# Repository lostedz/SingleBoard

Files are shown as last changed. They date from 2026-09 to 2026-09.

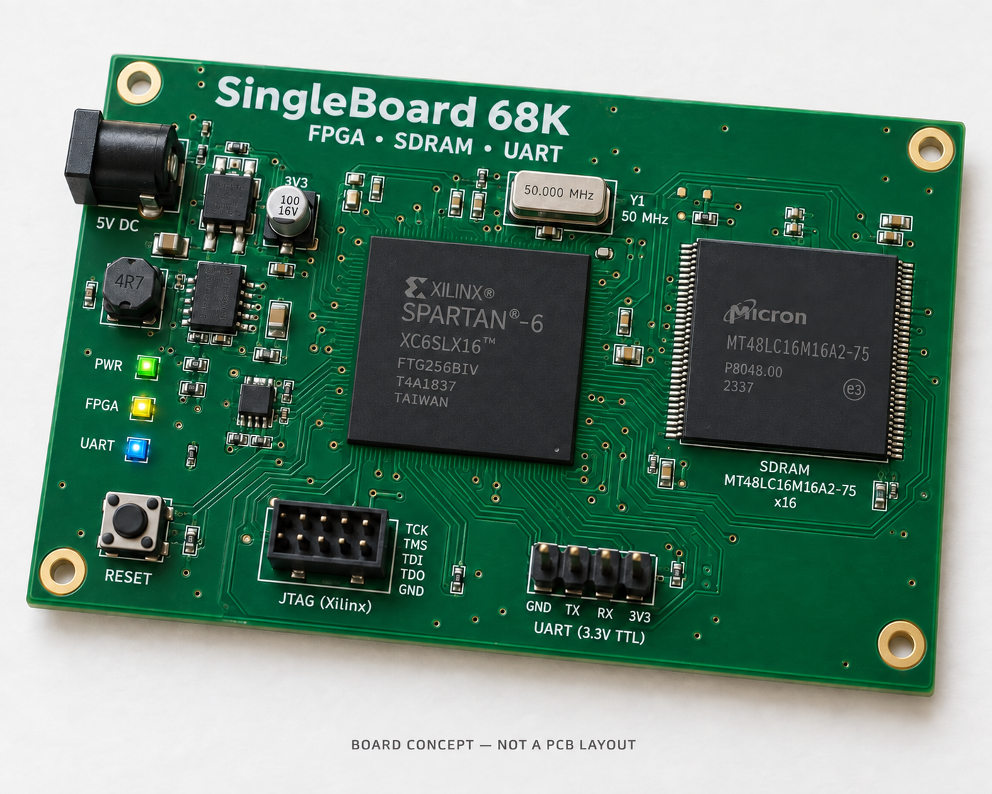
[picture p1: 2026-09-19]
docs/images/singleboard-concept.png

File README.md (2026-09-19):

# 68000 Verilog CPU

Target: **Xilinx Spartan-6 XC6SLX16 / FTG256 at 50 MHz** (speed grade -2
provisional). See `fpga/spartan6/README.md` for the ISE/XST
synthesis flow and board integration requirements.

An **MT48LC16M16A2-75 SDRAM controller** is included for the same 50 MHz clock.
See [SDRAM integration](docs/sdram.md) for its 32 MiB address mapping, CPU bus
connection, Spartan-6 clock forwarding, initialization and refresh behavior.
Run its standalone and CPU integration tests with `python scripts/test_sdram.py`.

A [memory-mapped UART](docs/uart.md) is available at **0xFF0000**, defaulting
to **115200 baud, 8N1** at 50 MHz. It includes TX/RX buffering, receive error
flags and optional interrupts. Run `python scripts/test_uart.py` for serial
and 68000 interrupt/echo tests.

A [schematic and board](hardware/README.md) for this target are in `hardware/`, as
a KiCad 10 project covering power, FPGA supply and configuration, the boot flash,
the SDRAM and the UART/clock/reset front panel. Both are generated:
`python scripts/gen_schematic.py` emits the drawing and the matching
`fpga/spartan6/singleboard.ucf` from one ball-assignment table, and
`python scripts/gen_pcb.py` builds the board from the schematic's own netlist —
a 120 × 90 mm four-layer placement whose floorplan follows which bank each
block's balls are in. The schematic passes ERC, the board passes DRC, and the
copper has been read back and compared to the assignment table. It is still a
concept: **the board has no tracks on it**, and there has been no ISE run and no
hardware validation.

`rtl/m68000.v` provides a synthesizable Verilog-2005 CPU for FPGA integration,
based on Frederic Requin's ISC-licensed [J68](https://github.com/fredrequin/j68_cpu).
The execution engine is vendored J68 RTL, not a newly written CPU. Local work
adds a 24-bit address interface, portable inferred memories, and executable
self-checking integration tests.

J68 implements the 68000 instruction set using a microcoded 16-bit datapath:
eight 32-bit data registers, eight address registers, separate user and
supervisor stacks, condition codes, effective-address decoding, multiply/divide,
traps, and autovectored interrupts. See `rtl/j68/PROVENANCE.md` for the pinned
revision and changes.

## Interface

All signals use one rising-edge clock. Inputs must be synchronous to `clk`.

| Signal | Meaning |
| --- | --- |
| `clk`, `reset` | Clock and active-high reset; hold reset for at least two clock edges and deassert synchronously |
| `clk_en` | CPU step enable; tie high for continuous execution |
| `ipl_n[2:0]` | Active-low encoded interrupt level; `111` is no interrupt, `101` is level 2 |
| `bus_valid` | Pending memory transaction |
| `bus_write` | 1 for write, 0 for read; meaningful while valid |
| `bus_addr[23:0]` | Byte address, including the low bit; high internal address bits are truncated to the 68000's 24-bit address space |
| `bus_be[1:0]` | Active-high byte lanes: bit 1 selects the even-address/high byte, bit 0 the odd-address/low byte |
| `bus_wdata[15:0]` | Write data already positioned in the selected lanes |
| `bus_rdata[15:0]` | Read data for the aligned word containing `bus_addr` |
| `bus_ready` | Memory acknowledgement; reads must have valid data on the completion edge |
| `bus_fc[2:0]` | J68 function-code output (user/supervisor, data/program/vector) |
| `debug_pc`, `debug_sr` | Internal 32-bit program counter and 16-bit status register |

A transfer completes on a rising edge when **`clk_en && bus_valid && bus_ready`**.
The memory slave must use that same condition for write side effects. Address,
direction, lanes, function code and write data remain stable during a pending
transaction, including CPU pauses. A slave may keep `bus_ready` high, or delay
it for any number of cycles. If the CPU is paused, retain read data/acknowledgement
until an enabled completion edge. Reset cancels a pending transaction.

Memory is big-endian. A longword uses two word transactions, high word first
for normal forward accesses. Fetch the initial SSP from addresses 0–3 and
initial PC from 4–7. Supply a valid reset-vector table and executable memory.
The testbench is a complete example memory slave.

## Build and test

Run from the project root so `$readmemb` can locate `rtl/j68/*.mem`. Include
every source in `rtl/files.f` and select `m68000` as the synthesis top. Memory
initialization must be supported by the target FPGA/toolchain; this is not
an ASIC ROM implementation. There are no vendor primitives or SystemVerilog
dependencies in the RTL.

With Python 3 and Icarus Verilog (`iverilog` and `vvp`) on PATH:

```sh
python scripts/test.py
python scripts/test.py --vcd
```

The runner also recognizes a local portable Windows installation in
`.tools/bin`. Test firmware is committed as `tests/smoke.hex`; an assembler
is not needed to run tests. To rebuild it with vasm:

```sh
vasmm68k -m68000 -Fbin -o build/smoke.bin tests/smoke.asm
python scripts/rom_to_hex.py
```

The self-checking program covers reset vectors, MOVE and MOVEQ, big-endian
byte/word/long transfers, postincrement/predecrement/indexed addressing,
arithmetic and overflow/carry/zero/negative flags, logic, shifts, bit operations,
DBRA, subroutine calls, signed/unsigned multiply/divide, MOVEM, TRAP/RTE,
STOP wakeup, and level-2 interrupts. It runs twice per simulation to check
reset recovery, with zero/one/seven wait cycles, periodic CPU pauses, and
deterministic irregular pauses with thirteen wait cycles. The bench also
checks request stability while stalled. Any failure or missing PASS fails
the Python runner, including with older VVP versions that return zero on `$fatal`.

## Compatibility limits

- This is not cycle-exact or a pin-compatible replacement for a physical MC68000.
  The interface is synchronous valid/ready, without AS/UDS/LDS, bus arbitration,
  a peripheral E clock, or a locked bus-cycle signal. External logic is needed
  for such system interfaces; multiprocessor atomic TAS is not provided.
- Bus-error exceptions and externally supplied interrupt vectors are not
  implemented. Interrupts use internal autovectors, without an external IACK cycle.
- J68's `RESET` opcode enters its CPU initialization routine; it does not emit
  the original processor's external peripheral-reset pulse.
- Address-error and other exception machinery comes from upstream. The included
  tests are smoke/integration coverage, not exhaustive instruction or exception
  conformance certification. No FPGA synthesis, timing closure, or hardware
  validation has been performed for this project.

Licensed under ISC; upstream attribution and licensing are retained.

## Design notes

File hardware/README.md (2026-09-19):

# SingleBoard 68K schematic and board

A KiCad schematic and board for the target the rest of this repository aims at: the
J68-derived 68000 soft CPU running inside an **XC6SLX16-FTG256** at 50 MHz, with the
**MT48LC16M16A2-75** SDRAM of [docs/sdram.md](../docs/sdram.md) and the 3.3 V
logic-level UART of [docs/uart.md](../docs/uart.md).

**This is a concept.** The schematic has not been simulated, fabricated or reviewed
by anyone, and the board is **placed but not routed** — it has no tracks on it at
all. Nothing here has been checked against silicon. Read
[Before you build one](#before-you-build-one) before spending money on it.

## Opening it

Open `singleboard.kicad_pro` in KiCad 10 (the files are written in KiCad 10's
formats: schematic `version 20260101`, board `version 20260206`).
`singleboard.pdf` is the drawing plotted out and `singleboard-pcb.pdf` is the
board's layer plot, if you only want to read them.

Project-specific symbols live in `symbols/singleboard.kicad_sym` and are found
through `sym-lib-table`. Everything else, footprints included, comes from KiCad's
stock libraries, so the board carries no local footprint library.

## Regenerating

Neither file is drawn by hand. The schematic comes first, and the board is
generated from the schematic's own netlist:

```sh
python scripts/gen_schematic.py
python scripts/gen_pcb.py
```

The first run writes the six sheets, the project symbol library, the project file
**and** `fpga/spartan6/singleboard.ucf`. The ball assignment exists once — the
SDRAM half is read from [sp6_SDRAM.ucf](../fpga/spartan6/sp6_SDRAM.ucf), the rest is
in the `BANK0_MAP` / `BANK2_MAP` tables at the top of the script — so the drawing and
the ISE constraints cannot drift apart. Edit the source, re-run; do not edit the
`.kicad_sch`, `.kicad_pcb`, `.kicad_pro` or `singleboard.ucf` by hand.

The second run exports the netlist from the schematic with `kicad-cli` and builds
the board from it, so footprints, references and nets cannot drift away from the
drawing either. It needs KiCad 10 installed and re-executes itself under KiCad's
bundled Python to get `pcbnew`; set `KICAD_HOME` if it is not in the usual place.

Before it draws anything the generator checks that every assigned ball exists on
the FTG256, is an I/O rather than a supply ball, and that the SDRAM sits wholly in
one bank. It fails loudly rather than emitting a wrong drawing.

The FPGA symbol itself is built from `sources/XC6SLX16-FTG256.lib`, so its 256
ball names and numbers are not retyped anywhere.

UUIDs are derived deterministically from sheet and reference names in both
generators, so regenerating an unchanged design produces byte-identical files.
`pcbnew` hands out random ones and sorts footprints by them, so the board
generator reseeds every item from its reference designator before saving.

## Sheets

| Page | Sheet | Contents |
| --- | --- | --- |
| 1 | `singleboard` | Overview and sheet index |
| 2 | `power` | 5 V input protection, 3.3 V and 1.2 V buck converters, test points |
| 3 | `fpga_core` | FPGA supply and ground balls, decoupling, configuration pins, boot flash, JTAG |
| 4 | `fpga_io` | The two I/O bank units, VCCO decoupling (A2 sheet) |
| 5 | `sdram` | MT48LC16M16A2P-75 and its decoupling |
| 6 | `io` | Oscillator, UART header, reset button, status LEDs |

Cross-sheet connectivity is by **global label**; the sheets carry no hierarchy
pins. Every device pin is drawn as a short stub terminated in a label or a power
port, which is the usual style for a part with this many pins and keeps the
generator honest.

## Power

Two rails from a 5 V barrel jack:

| Rail | Source | Feeds |
| --- | --- | --- |
| +3V3 | TPS562200 buck, 100k/30.1k feedback | VCCO banks 0–3, VCCAUX, SDRAM, boot flash, oscillator, LEDs |
| +1V2 | TPS562200 buck, 56.2k/100k feedback | VCCINT |

The input has a 1.1 A polyfuse, a series SS34 for reverse polarity (about 0.4 V
of drop; both bucks accept 4.5 V minimum) and an SMAJ5.0A clamp.

**VCCAUX is run at 3.3 V rather than 2.5 V**, which is what removes the third
rail. The bitstream has to agree, so the generated UCF carries
`CONFIG VCCAUX = 3.3;`.

R3/C3 hold the 3.3 V enable about 100 ms behind the 1.2 V enable, so VCCINT comes
up before VCCO and VCCAUX. This follows the recommended order; confirm against
DS162 whether your device actually requires a sequence.

Decoupling is one 100 nF per supply ball — 8 on VCCINT, 8 on VCCAUX, 20 across the
four VCCO banks, 7 on the SDRAM — plus bulk on each rail. They are only meaningful
if layout puts each one against its ball, which is what the board's
[bypass placement](#bypass-placement) is for.

## Pin assignment

**The SDRAM balls are not chosen here.** All 39 of them are read out of
[sp6_SDRAM.ucf](../fpga/spartan6/sp6_SDRAM.ucf), the constraints file for the
reference Spartan-6 SDRAM board, at generation time. Only the signal names are
translated (`Data[0]` → `SDRAM_DQ0`, `SDCS0` → `SDRAM_CS_N`, and so on); every
`LOC` is taken verbatim, so the schematic follows the physical board rather than
the other way round. Change that file and re-run the generator.

They all land in **bank 3**, and the generator refuses to run if they do not.
Note that the assignment does not line up with the hard memory controller's own
ball names — `SDRAM_DQ0` sits on `IO_L83N_VREF_3`, for instance. That is fine
here: the MCB is not instantiated, and the soft controller in
`rtl/sdram_mt48lc16m16a2.v` drives these as ordinary LVCMOS33 I/O.

Bank 0 carries the 50 MHz clock (on GCLK-capable ball E7), the UART, the reset
button, the four LEDs and the HSWAPEN strap. Bank 2 carries the master-SPI
configuration interface. **Bank 1 is entirely spare**, as is most of bank 0.

`sp6_SDRAM.ucf` also fixes four non-SDRAM pins for its own board — `CLK_50M_IN`
A10, `sys_rst_n` R7, `led_1` T9, `led_2` R9 — which this schematic does *not*
follow; its clock, reset and LEDs are on the bank-0 balls above. If the intent is
to match that board rather than to design a new one, those four should move too.

Unused bank pins carry a no-connect flag. To bring one out later, delete its flag
on the `fpga_io` sheet and add a `LOC` to the UCF.

`R30` (22 Ω) damps the forwarded SDRAM clock. The FPGA-side net is
`SDRAM_CLK_FPGA` and the device-side net is `SDRAM_CLK`;
`rtl/sdram_spartan6_clock.v` drives the FPGA side from an ODDR2 with the clock
inverted so the device samples mid-cycle.

## Configuration

Master SPI from a W25Q32JVSS (32 Mbit; an XC6SLX16 bitstream is about 3.73 Mbit),
with JTAG on a 6-pin 0.1" header in the Digilent order (1 TMS, 2 TDI, 3 TDO,
4 TCK, 5 GND, 6 VREF).

The mode pins are strapped **M[1:0] = 01**. Each strap has a fitted resistor and a
DNP alternate (R16 and R17) so the mode can be changed by rework.
DONE gets the 330 Ω pull-up UG380 asks for; D4 lights while the device is
*un*configured.

## Board

`singleboard.kicad_pcb` is **120 × 90 mm, four layers, placed and planed but with
no tracks on it**. All 129 footprints are down, every pad carries the net the
schematic gives it (bar the barrel jack's unused switched contact), the
planes are poured, and all 220 nets are still ratsnest lines. Routing it is the
next piece of work, not something this file has had.

| Layer | Use |
| --- | --- |
| F.Cu | Components and signal routing |
| In1.Cu (`GND`) | Solid ground plane, 10466 mm² poured |
| In2.Cu (`PWR`) | +3V3 plane with a 1180 mm² +1V2 island cut into it |
| B.Cu | Bypass capacitors, ground pour, signal routing |

Design rules live in `singleboard.kicad_pro` and are sized for an escape out of a
1.0 mm pitch BGA: 0.15 mm track on 0.13 mm clearance with 0.45/0.25 mm vias by
default, and a `Power` class at 0.6 mm track and 0.8/0.4 mm vias for GND, +5V,
+3V3, +1V2 and the two buck switch nodes.

### Floorplan

Nothing about the arrangement is arbitrary — each block sits on the side of the
package its balls are on, which the generator reads out of the same ball map the
schematic uses:

| Block | Where | Why |
| --- | --- | --- |
| SDRAM, `R30` | Left of the FPGA | All 39 SDRAM balls are in bank 3, the −X side |
| Oscillator, reset, LEDs, UART header | Above it | Bank 0 is the −Y side |
| Boot flash, mode straps, JTAG header, PROG | Below it | Bank 2 is the +Y side |
| Both bucks, barrel jack, fuse, TVS, test points | Right-hand column | Bank 1 is entirely spare, so nothing competes for it |

The 1.2 V island on In2.Cu is one connected region spanning the FPGA core, the
1.2 V buck and a neck between them; +3V3 fills the rest of that layer, and the
two are resolved by zone priority rather than by a hand-drawn split.

### Bypass placement

The 36 FPGA bypass capacitors are on the **back**, in the ball shadow. Each one is
assigned to a specific supply ball — `C100`–`C107` to the eight VCCINT balls,
`C120`–`C127` to the eight VCCAUX balls, `C200`–`C219` to the twenty VCCO balls,
in ball order — and then placed on the free slot nearest that ball, closest pair
first. The middle of the package is where the VCCINT cluster is, so it gets the
middle slots.

A 0402 is 1.91 × 1.01 mm and the FTG256 balls are on a 1.0 mm pitch, so one cap
cannot sit centred on every ball; the slot grid is 2.2 × 1.8 mm, which clears the
courtyards both ways. Their reference designators are on the fab layer only —
there is no room to letter them on silkscreen at that pitch. The seven SDRAM caps
are likewise on the back, in a column under the body.

## What has been checked

Run against the generated files with KiCad 10.0.6:

- **ERC: 0 violations** (`kicad-cli sch erc`), errors and warnings.
- **Netlist**: 220 nets. Every net in the assignment tables was confirmed to reach
  the intended FPGA ball, every SDRAM signal was confirmed to reach the intended
  TSOP pin, and every `LOC` in the generated UCF was confirmed against the
  exported netlist. No net has fewer than two nodes apart from the deliberate
  no-connects.
- **SDRAM balls**: all 39 `LOC` values in the generated UCF compared equal to
  `sp6_SDRAM.ucf`, and all 39 are bank-3 I/O balls on the FTG256.
- **Plot**: no content falls outside any sheet frame and no two text strings
  overlap on any sheet.
- **DRC: 0 errors, 1 warning** (`kicad-cli pcb drc`), run by `gen_pcb.py` itself
  on every generation; it exits non-zero if an error appears. The warning is an
  isolated copper fill on the +1V2 island, which is inherent to an unrouted
  board: nothing on an outer layer reaches In2.Cu until there are vias. The 252
  unconnected items are the unrouted nets.
- **Copper against the assignment**: all 55 assigned balls were read back off the
  board and compared to the generator's tables; every one carries the intended
  net. All 39 SDRAM signals land on the intended FTG256 ball, all 38 device-side
  ones reach the intended TSOP pin, and the clock reaches pin 38 through `R30`.
  Every VCCINT, VCCAUX, VCCO and GND ball is on the rail it should be.
- **Placement**: every footprint except `J1` is wholly inside the outline, which
  the generator checks and refuses to write a board otherwise; `J1`'s barrel is
  meant to reach the edge. No courtyards overlap and no silkscreen collides,
  which is what the clean DRC above covers.
- **Reproducibility**: both generators were run twice from scratch and produced
  byte-identical `.kicad_sch`, `.kicad_pcb` and `.kicad_pro`.

## Before you build one

None of the following has been done, and each could change the design:

- **No routing.** The board is placed and poured, and that is all. Every net is
  still a ratsnest line. The FTG256 escape has not been attempted, so whether 220
  nets actually get out of that package on four layers — and whether four layers
  are enough — is an open question; a real escape usually wants via-in-pad or
  more layers, and finding out could push the bypass caps somewhere else.
- **No signal or power integrity work.** No stackup or impedance target, no
  length or skew matching on the SDRAM bus at 50 MHz, no return-path analysis
  across the In2.Cu plane split, no thermal work on the two bucks.
- **No fabrication outputs.** No gerbers, no drill file, no pick-and-place, no
  BOM. The design rules in the project file are a plausible four-layer
  capability, not a quote from a fab.
- **No ISE run.** The UCF has never been through MAP, PAR or static timing. Bank
  and clock-region legality of the assignment is unverified, as is whether the
  design fits and closes timing.
- **No supply validation.** Rail currents are estimates (VCCINT ~0.3 A,
  VCCAUX+VCCO ~0.4 A, SDRAM ~0.15 A). Inductor and capacitor values were chosen by
  convention, not calculated against a load profile or checked for loop stability.
- **Datasheet cross-checks still owed.** In particular: the SDRAM pin numbers
  (drawn to the JEDEC 54-pin TSOP-II arrangement), the Spartan-6 configuration
  mode encoding against UG380 Table 2-3, and the VCCAUX = 3.3 V choice against
  DS162 for the speed grade you buy.
- **The speed grade is still provisional** (-2), as noted in
  [fpga/spartan6/README.md](../fpga/spartan6/README.md).
- **There is no board-level top module yet.** The UCF names ports after
  `rtl/sdram_mt48lc16m16a2.v`, `rtl/uart_mmio.v` and `rtl/sdram_spartan6_clock.v`;
  something still has to instantiate the CPU, the memory arbiter, the boot ROM and
  the UART together and bring those ports out.

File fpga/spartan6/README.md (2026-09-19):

# Spartan-6 / ISE integration

Configured target: **XC6SLX16, FTG256, 50 MHz (20 ns)** in `target.json`.
Speed grade **-2 is provisional**, since it was not specified. Confirm the
full device marking before relying on timing reports; `--part` overrides it.

For the MT48LC16M16A2-75 memory controller, see `docs/sdram.md` and use
`python scripts/synth_spartan6.py --top sdram_mt48lc16m16a2`. Its SDRAM clock
must be forwarded through the supplied ODDR2 module at the board boundary.

For serial I/O, see `docs/uart.md`. Generate the UART core synthesis inputs
with `python scripts/synth_spartan6.py --top uart_mmio --generate-only`.

Use Xilinx ISE/XST for this target. The RTL is Verilog-2005; the core has no
Intel primitives. Microcode uses a 2048 x 20-bit memory (with two byte-write
enables for the register region); instruction decode uses a 256 x 36-bit ROM.
The RAM read output has a synchronous reset, and both memories request block
implementation through XST attributes. Memory contents are included as `.mem`
files. Small internal stacks may map to distributed RAM or registers.

After initializing your ISE environment, synthesize using the saved target:

```sh
python scripts/synth_spartan6.py
```

Add `--generate-only` to inspect the `.prj`, `.xst`, and `.xcf` without ISE.
Override settings with `--part xc6slx16-3-ftg256 --clock-mhz 50` if the
actual speed grade is -3, for example.
Run XST from the repository root to resolve all RTL and `$readmemb` paths.
The resulting NGC is a **core netlist**, with I/O and clock-buffer insertion
disabled. Instantiate it in a board-level design, or include `rtl/files.f`
directly in that design's ISE project.

At board level:

- Feed `clk` from a global clock buffer. Use `clk_en` for throttling; do not
  gate the clock with fabric logic. Constrain the actual clock, without
  assuming multicycle paths from `clk_en`.
- Synchronize deassertion of the external reset and hold the CPU reset for
  at least two running clock edges. Synchronize external interrupt sources
  before forming the active-low priority code.
- Implement the memory slave/arbiter and boot-vector ROM. The microcode files
  are CPU internals, not program memory. Acknowledge each access according to
  the valid/ready contract in the root README.
- Add board-specific UCF pin LOCs, I/O standards and external memory timing.
  The generated XCF constrains only core synthesis; put the corresponding
  PERIOD constraint in the board UCF for implementation.
- Inspect the XST RAM/ROM inference and utilization report. Check that the
  large memories map to block RAM and fit the chosen device. Run MAP, PAR,
  and static timing analysis before generating a board bitstream.

No ISE installation was available for this implementation, so RAM mapping,
resource utilization, maximum frequency and hardware behavior are not yet
validated. Simulation covers the same inferred-memory RTL used for synthesis.

References: AMD/Xilinx [UG687, XST User Guide](https://docs.amd.com/api/khub/documents/PmWWcoPdaZa5uE2SYAF8Vg/content)
and [UG383, Spartan-6 Block RAM User Guide](https://docs.amd.com/api/khub/documents/Xs~b~O94R6gZSgSD34Yh5Q/content).

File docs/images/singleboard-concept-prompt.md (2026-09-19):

# SingleBoard board concept

Generated with the built-in image-generation tool. Concept only; component placement, silkscreen, power circuitry and traces are illustrative, not an electrically validated PCB design.

## Initial prompt

Use case: product-mockup.
Create a high-resolution photorealistic electronics board concept for the SingleBoard project: a 68000-compatible soft CPU implemented INSIDE a Xilinx Spartan-6 XC6SLX16 FPGA, FTG256 BGA package, at 50 MHz, with a Micron MT48LC16M16A2-75 x16 SDRAM and a logic-level UART interface.
Show one compact rectangular green PCB, approximately 100 x 80 mm, in a clean three-quarter near-top-down studio product view on a light neutral background. Entire board in frame, crisp component detail, soft shadows. Realistic solder mask, fine copper traces, plated vias, white silkscreen, sensible decoupling and connector clearances, four mounting holes.
Main square black FPGA has no exposed gull-wing leads because it is BGA; marking "XILINX", "SPARTAN-6", "XC6SLX16". Adjacent rectangular SDRAM in plausible 54-pin TSOP-II package with leads along its two long edges, marked "MT48LC16M16A2-75". A small metal oscillator marked "50 MHz". Near an edge a clearly labeled four-pin 3.3V TTL UART header with silkscreen "GND", "TX", "RX", "3V3". Include a modest JTAG programming header, reset pushbutton, power connector with nearby regulation components, and a few status LEDs as plausible supporting board hardware. No separate physical Motorola 68000 chip, no RS-232 DB9 connector, no invented USB data interface.
Board silkscreen title: "SingleBoard 68K". Secondary silkscreen: "FPGA • SDRAM • UART". Small tasteful caption below the board: "BOARD CONCEPT — NOT A PCB LAYOUT". Prioritize a believable engineered physical board over decorative futuristic circuitry. This is a conceptual visualization, not an existing manufactured board or an electrically validated layout.

## Final edit prompt

Edit this board concept image. Keep the composition, PCB, SDRAM, connectors, oscillator, lighting and board title unchanged. Correct the central Xilinx Spartan-6 FPGA to an FTG256 BGA package: REMOVE EVERY exposed metallic lead and perimeter solder pad along ALL FOUR edges of the FPGA. The FPGA must be a clean square black package with smooth straight sides, sitting slightly above the PCB, all solder balls hidden underneath. Surrounding traces should end at small vias outside the smooth package; absolutely no comb-like pins, no gull-wing leads, no QFP footprint. Preserve its XILINX SPARTAN-6 XC6SLX16 FTG256 marking. Remove the invented decorative slogans "Classic Ideas Modern Logic" and "Small Board Big Possibilities" leaving plain green solder mask in their place. Correct the power connector label to just "5V DC", remove "(7-12V)". Keep the caption "BOARD CONCEPT — NOT A PCB LAYOUT".

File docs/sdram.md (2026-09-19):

# MT48LC16M16A2-75 SDRAM

`rtl/sdram_mt48lc16m16a2.v` is a Verilog-2005 controller for the Micron
MT48LC16M16A2-75 at **50 MHz**. It exposes a 16-bit memory slave compatible
with the CPU's valid/ready bus and implements the full 32 MiB device geometry.
It is deliberately a single-outstanding, single-word controller: burst length
one, CAS latency two, explicit precharge after every access, no open-row cache,
and no self-refresh or clock stopping.

## Device and timing

The device has four banks, 8192 rows per bank, and 512 sixteen-bit columns.
Native bus addresses are 25-bit **byte** addresses:

| Address bits | SDRAM field |
| --- | --- |
| `[24:23]` | Bank BA1:BA0 |
| `[22:10]` | Row A12:A0 during ACTIVE |
| `[9:1]` | Column A8:A0 during READ/WRITE |
| `[0]` | Byte position, expressed by `bus_be`; not sent as a column bit |

The controller uses conservative fixed timing for the -75 at a 20 ns period.
Each access issues ACTIVE, waits, issues READ or WRITE, waits for data/recovery,
then PRECHARGE ALL and waits before allowing another operation. It does not
perform auto-precharge, so write recovery follows the explicit-precharge rule.

| Requirement | Device minimum / limit | Implementation |
| --- | --- | --- |
| Power-up pause | 100 us after stable power/clock | 200 us (`INIT_CYCLES=10000`) |
| Initialization | Precharge, at least 2 refreshes, mode set | PRECHARGE ALL, 2 AUTO REFRESH, MRS `0x020` |
| tRCD / tRP | 20 ns | At least 60 ns between applicable commands |
| tRFC / tRC | 66 ns | Refresh command spacing at least 100 ns; accesses slower |
| tRAS | 44 ns min / 120 us max | Rows closed after each access (at least 120 ns active) |
| tWR, explicit precharge | 15 ns | 60 ns after WRITE |
| tMRD | 2 clocks | At least 2 clocks |
| CL2 tAC | 6 ns max | Falling-edge input capture described below |
| Standard/industrial refresh | 8192 refreshes per 64 ms | Refresh due every 300 clocks (6 us), plus bounded in-flight access |

The FSM may delay a due refresh by at most one short transaction. The default
worst-case gap remains below 7.8125 us. A pending bus response never blocks
refresh. `REFRESH_CYCLES=75` supports the stricter 16 ms/8192-row automotive
refresh interval. Do not exceed 300 or reduce below 16; use the actual device's
temperature grade requirements. These parameters do **not** make the controller
frequency-independent: command delays and the read phase are fixed at 50 MHz.
Do not reduce `INIT_CYCLES` below 10000 for this configuration.

Source: Micron, *256Mb: x4, x8, x16 SDRAM*, Rev. W, May 2015
([manufacturer-authored datasheet mirror](https://www.rxelectronics.pl/datasheet/2e/MT48LC16M16A2P-75-D-TR.pdf)),
particularly the x16 block diagram, -75 AC timing table, initialization, and
READ/WRITE timing sections.

## Clock and FPGA boundary

Feed the controller the existing 50 MHz global clock. Instantiate
`rtl/sdram_spartan6_clock.v` beside it to forward **the inverted clock** to
the SDRAM pin using the Spartan-6 ODDR2 output primitive. The external SDRAM
clock remains running even when the CPU's `clk_en` is low.

```verilog
sdram_spartan6_clock clock_output (
    .clk(clk_50mhz), .sdram_clk(sdram_clk_pin)
);
```

Command/address/write signals launch on the FPGA clock's rising edge and the
SDRAM samples them on its falling edge, giving nominally half a cycle of setup.
For a READ launched at rising edge P0, the device samples it at N0 and supplies
CL2 data after N2. An input register captures that data at N3, before the
device's next clock-to-output transition; the FSM transfers the sample into
the response register at P4. The input register requests IOB placement. This
provides a nominal 20 ns data-arrival interval (14 ns after subtracting the
part's 6 ns maximum tAC), subject to forwarded-clock skew, PCB flight times,
FPGA input delay and setup/hold requirements.

Use a 3.3 V-compatible FPGA I/O bank and appropriate LVTTL/LVCMOS33 constraints
for the actual board. Add UCF LOCs for the SDRAM clock, CKE, CS/RAS/CAS/WE,
A[12:0], BA[1:0], DQM[1:0], and DQ[15:0]. DQM[1] is DQMH and DQM[0] is DQML.
Place the bidirectional DQ nets at the board boundary so XST can infer IOBUFs.
Include the ISE UNISIM library when simulating the ODDR2 wrapper.

The board UCF must constrain the 20 ns clock plus SDRAM input/output timing
relative to the forwarded clock, including its phase and board delays. The
standalone synthesis XCF is **not** a complete external-memory timing constraint
set. No pin assignments or guessed board trace delays are supplied.

## Bus contract and 68000 connection

Hold `bus_valid`, address, direction, byte enables and write data until a rising
edge with `bus_valid && bus_clk_en && bus_ready`. Requests are latched only
while `bus_clk_en` is high. Once accepted internally, an operation finishes
independently of CPU clock enable. The response stays asserted and read data
stays stable until that completion handshake. Tie `bus_clk_en` to the CPU's
`clk_en` (or 1 for an always-running master).

Byte lanes use the CPU's existing big-endian convention: bit 1 selects DQ15:8
at the even byte address; bit 0 selects DQ7:0 at the odd address. Write DQM is
`~bus_be`. Read returns the entire aligned word; the CPU selects the needed
byte. A zero-byte-enable write leaves memory unchanged. DQM remains low during
reads to account for the device's read-mask latency.

The CPU can address only 16 MiB. For an uncomplicated mapping, connect
`bus_addr` to `{1'b0, cpu_addr}` (the lower half of SDRAM). To expose the upper
half, use a software-controlled page bit: `{page, cpu_addr}`. That bit must be
stable for each request. A board-level address decoder should select SDRAM
versus boot ROM and peripherals:

```verilog
// Signals are wires in your board-level module; select comes from your map.
// Controller: bus_valid = cpu_valid && select_sdram
//             bus_clk_en = cpu_clk_en
//             bus_addr = {page, cpu_addr}
//             bus_write/be/wdata = corresponding CPU outputs
assign cpu_ready = select_sdram ? ram_ready : rom_io_ready;
assign cpu_rdata = select_sdram ? ram_rdata : rom_io_rdata;
```

Initialization stalls requests; `init_done` indicates the memory is ready.
SDRAM powers up with undefined contents. Provide a boot ROM at the CPU reset
vectors and a loader (or another master) to populate SDRAM. The integration
test preloads the simulation model; that is not a hardware initialization path.

Controller `reset` is synchronous and restarts initialization, cancelling any
pending response. Treat a controller reset as destructive to memory validity:
an already issued write cannot be undone, and refresh is suspended during
reinitialization. Use a separate CPU warm reset if SDRAM must be preserved;
the controller and SDRAM clock must continue running. Hold controller reset
until power and the FPGA clock are stable, and synchronize its release.

## Build and verification

The source list `rtl/files.f` includes the controller and clock-forwarding module.
Generate or run an ISE synthesis job for the controller with:

```sh
python scripts/synth_spartan6.py --top sdram_mt48lc16m16a2 --generate-only
python scripts/synth_spartan6.py --top sdram_mt48lc16m16a2
python scripts/test_sdram.py
```

The controller synthesis job produces a core netlist; synthesize the ODDR2,
I/O buffers, memory decode and CPU together in the final board design.

The tests use an independent, command-level sparse SDRAM model with complete
physical address tags, CL2 output delay, DQM handling, and checks for power-up,
MRS, tRCD, tRP, tRAS, tRC, tRRD, tWR, tRFC, and refresh deadlines. They cover
both byte lanes, masked writes, all-bank/row/column boundaries, deterministic
random addresses, read/write turnaround, idle refresh, and responses held
while the CPU is paused. The standalone bench includes 2 ns forwarded-clock
delay and 2 ns read flight delay. It checks both standard (64 ms) and automotive
(16 ms) refresh deadlines. The 68000 firmware also runs through SDRAM
with continuous and irregularly paused CPU execution and a CPU warm reset.

The model covers this controller's command subset, not the entire SDRAM
protocol or analog behavior. ISE fit/timing and physical-board validation remain
outstanding; passing simulation is not a claim of hardware timing closure.

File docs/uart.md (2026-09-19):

# Memory-mapped UART

`rtl/uart_mmio.v` implements a full-duplex UART for the SingleBoard CPU bus.
Defaults are **50 MHz, 115200 baud, 8N1**, with no hardware flow control.
The rounded divider is 434 clocks/bit (about 115207 baud). `CLOCK_HZ` and
`BAUD` are synthesis parameters; the divider is not software-programmable.
Use parameter combinations giving 8 through 65535 clocks/bit.

There is a one-byte RX holding register and a one-byte TX holding register
in addition to the TX shift register. Software can queue the next TX byte
while one is transmitting. An RX overrun preserves the unread byte and drops
the new one. RX has a two-flop synchronizer, validates the start bit halfway
through it, samples data at bit centers, and checks the stop bit. A framing
error discards the frame; a continuously low line waits for a return to idle
before detecting another start.

## Register map

The default eight-byte region starts at **0xFF0000**. Change the aligned
`BASE_ADDR` parameter to relocate it; address bits [2:0] of that parameter
are ignored. Byte addresses within a register pair refer to the same register.

| Offset | Register | Read | Write |
| --- | --- | --- | --- |
| +0/+1 | DATA | RX byte, or zero if empty; consumes a valid byte | Queue a TX byte; waits if TX holding register is full |
| +2/+3 | STATUS | Status bits below | Write one to bits 3/4 to clear their sticky error flags |
| +4/+5 | CONTROL | Interrupt enables | Bit 0 RX-ready IRQ; bit 1 TX-space IRQ; bit 2 error IRQ |
| +6/+7 | DIVIDER | 16-bit clocks per serial bit (434 by default) | Ignored |

STATUS bits:

| Bit | Meaning |
| --- | --- |
| 0 | RX byte available |
| 1 | TX can accept a byte |
| 2 | TX completely idle, including its holding register |
| 3 | Sticky RX overrun |
| 4 | Sticky framing error |
| 5–6 | Zero |
| 7 | Interrupt output active |

DATA, STATUS and CONTROL reads duplicate the byte onto both CPU lanes. Thus
68000 byte accesses work at either address in the pair. For writes,
`bus_be[1]` selects `bus_wdata[15:8]`, and `bus_be[0]` selects
`bus_wdata[7:0]`; if both lanes are enabled, the low byte is used once.
Zero-lane transactions have no side effects. Read DIVIDER as a word.

## CPU and SDRAM integration

All bus side effects occur exactly on a rising edge with
`bus_valid && bus_clk_en && bus_ready`. Hold the request until that handshake.
The UART acknowledges only its own address range. Its ready/data outputs are
combinational: status and RX availability are sampled at the completion edge,
not frozen when the CPU pauses. TX and RX continue running independently of
`bus_clk_en`, which must match the CPU's `clk_en`.

Reserve the UART region in the board address decoder; **exclude it from
SDRAM writes**. A typical response mux is:

```verilog
wire uart_select = cpu_addr[23:3] == 21'h1fe000; // 0xFF0000–0xFF0007
// UART gets cpu_valid (it has its own address decoder).
// SDRAM gets cpu_valid && !uart_select && !boot_select.
// Boot ROM gets cpu_valid && boot_select && !uart_select.
assign cpu_ready = uart_select ? uart_ready :
                   boot_select ? boot_ready : sdram_ready;
assign cpu_rdata = uart_select ? uart_rdata :
                   boot_select ? boot_rdata : sdram_rdata;
```

`irq` is an active-high **level** output. With UART as the only interrupt
source, use `ipl_n = irq ? 3'b101 : 3'b111` for 68000 level 2, and install
the handler in autovector 26 at address 0x68. Combine multiple interrupt
sources in a board-level priority encoder. Interrupt enables reset to zero.
Reading DATA clears RX-ready; STATUS W1C clears errors. TX-space IRQ remains
asserted while space is available, so disable it when there is nothing left
to send. A new receive/error event wins over a simultaneous read/clear.

Example polled transmit using odd-address byte accesses:

```asm
wait_tx:
    btst    #1,$ff0003
    beq     wait_tx
    move.b  #'A',$ff0001
```

A write can also wait directly for space, but polling allows software to do
other work. `tests/uart_smoke.asm` is a complete CPU example that transmits
`OK`, receives `!` using a level-2 interrupt, and echoes it.

## FPGA pins and build

Connect `uart_rx` and `uart_tx` to the board's logic-level serial connector
or a compatible USB-to-UART adapter. Cross TX to RX and connect ground. These
are FPGA logic signals, not RS-232 voltage levels; use a transceiver for an
RS-232 connector. Assign LOC and I/O standard in the board UCF according to
the actual connector and bank voltage. RX should idle high. Keep the 50 MHz
clock running while using CPU clock enables.

The design uses ordinary Verilog-2005 registers, with no vendor IP. ISE may
use the `ASYNC_REG` attribute to recognize the RX synchronizer. Board timing
constraints should treat the external RX input as asynchronous, without
cutting the path between the two synchronizer registers.

```sh
python scripts/test_uart.py
python scripts/synth_spartan6.py --top uart_mmio --generate-only
python scripts/synth_spartan6.py --top uart_mmio
```

Tests use independent serial transmit/receive stimulus at the default baud
rate, including a slightly mismatched receive baud. They cover byte lanes,
full-duplex operation, TX backpressure, zero-lane accesses, a paused CPU read,
interrupts, overrun, framing errors, false starts, reset and address decode.
The second test executes the included 68000 firmware against the UART.
The firmware image is committed; rebuilding it requires vasm:

```sh
vasmm68k -m68000 -Fbin -o build/uart_smoke.bin tests/uart_smoke.asm
python scripts/rom_to_hex.py --name uart_smoke
```

ISE fit/timing and board-level validation have not been run here. Pin locations
remain board-specific; no connector pinout has been assumed.

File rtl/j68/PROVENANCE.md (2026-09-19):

# J68 provenance

Source: https://github.com/fredrequin/j68_cpu

Commit: `538badf8def66dc900947be665d0eac6f9ff833e`

Author: Frederic Requin. Upstream declares ISC licensing in its README,
preserved as `UPSTREAM_README.md`. Original copyright headers are retained.
See the project LICENSE for the ISC text.

This directory contains the CPU dependencies, four memory initialization
images, and the microcode assembly source. It excludes the upstream SoC,
UART, third-party assembler, emulator, executables and unrelated ROMs.

Local RTL changes, reproducible with `scripts/import_j68.py`:

- Select inferred memories instead of Intel `altsyncram` primitives.
- Resolve initialization filenames relative to the project root.
- Use synchronous reset for the microcode read output and XST `ram_style` /
  `rom_style` attributes to request Spartan-6 block memories.
- Select the microcode image with an explicit conditional `$readmemb`, avoiding
  differently sized string parameters that older Icarus versions misinterpret.

The top-level wrapper uses the standard `USE_CLK_ENA=0` microcode, whose
decode pipeline includes the extra cycle needed for consecutive enabled
clocks. The upstream optimized clock-enable microcode assumes gaps between
enabled clocks and is not used by this wrapper.

To reproduce, clone upstream into `.upstream-j68`, check out the exact commit
above, and run `python scripts/import_j68.py`. No download is needed to build
or simulate the committed RTL.

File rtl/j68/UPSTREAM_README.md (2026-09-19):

J68 - A Size-Optimized Microcoded 68000 CPU
===========================================

J68 is a CPU core that implements the Motorola/Freescale/NXP [68000 Instruction Set](https://www.nxp.com/files/archives/doc/ref_manual/M68000PRM.pdf).

J68 is free and open hardware licensed under the [ISC license](http://en.wikipedia.org/wiki/ISC_license)
(a license that is similar in terms to the MIT license or the 2-clause BSD license).

Features and Typical Applications
---------------------------------

- Small (1900 LUTs + 8 x M9k on a Cyclone III)
- High f<sub>max</sub> (90 MHz on a Cyclone III, 180 MHz on a Stratix II)
- Stack based CPU with Forth-like microcode
- Not cycle exact : needs a frequency ~3 times higher
- All 68000 instructions are implemented
- Almost all 68000 exceptions are implemented (only bus error missing)
- Only auto-vector interrupts supported

This CPU is meant to be used in Retro gaming / Retro compututing applications. Due to its high f<sub>max</sub>,
it can operate at the SDRAM controller frequency, without clock domain crossing.

Files in this Repository
------------------------

#### README.md

You are reading it right now.

#### rtl/cpu_j68.v

This is the top level of the J68 CPU

#### rtl/j68_addsub_32.v

Optimized 32-bit add / subtract.

#### rtl/j68_alu.v

The 16-bit ALU (ADD, SUB, AND, OR, XOR, NOT and bitmask) with C and V flags generation.

#### rtl/j68_decode.v

Instruction decoder, it generates a 8-bit index for a 256-entry jump table.
It also generates the 4-bit effective address indexes and the immediate values.
Finally, it detects the invalid and privileged instructions.

#### rtl/j68_decode_rom.v

ROM containing the 256-entry jump table.

#### rtl/j68_dpram_2048x20.v

2048 x 20-bit ROM/RAM containing microcode and CPU registers (D0-D7, A0-A7).

#### rtl/j68_flags.v

Flags read / write in the condition code register (CCR).

#### rtl/j68_loop.v

Microcode loop for multi-cycle instructions (MUL, DIV, MOVEM).

#### rtl/j68_test.v

Microcode conditional branching.

#### rtl/j68_mem_io.v

External bus management and special registers (PC, SR, EA1, EA2, VBR, ACCU, SHIFTER).

#### rtl/soc_j68.v

A system-on-a-chip that re-create the Raymatic M68000 development board (68000 + 16 KB ROM + 32 KB RAM + 2 x ACIAs 6850).
The VUBUG debugger can run on this SOC (https://www.retro.co.za/68000/VUBUG/).

#### rtl/acia_6850.v

The 6850 ACIA from the Suska project (https://www.experiment-s.de/en/), translated into verilog.

#### rtl/onchip_ram.v

Parameterized RAM block for Verilator and Altera Cyclone III.

#### rtl/onchip_rom.v

Parameterized ROM block for Verilator and Altera Cyclone III.

#### rtl/tb/tb_clock.v

100 MHz clock and reset generator for the Verilator testbench.

#### rtl/tb/tb_soc_j68.v

Verilator testbench top level.

#### verilator/clock_gen/

Configurable clock generator for Verilator.

#### verilator/m68k_trace/musashi/

Musashi 680x0 trace/emulator from MAME project (https://github.com/kstenerud/Musashi).

#### verilator/m68k_trace/m68k_trace.cpp

DPI-C interface for Musashi.

#### verilator/m68k_trace/musashi.cpp

C++ wrapper for the Musashi 680x0 trace/emulator.

#### verilator/compile

Compile script for the Verilator testbench.

#### verilator/main.cpp

Main loop of the Verilator testbench.

#### verilator/tb_top.v

Verilator testbench configuration file.

#### tools/microcode20/

Micro-code assembler.

#### tools/srecord/

SRecord v1.64 tool (http://srecord.sourceforge.net/).

#### tools/vasmm68k/

VASM M68k assembler (http://sun.hasenbraten.de/vasm/).

#### roms/rom_vubug.asm

Assembly source code of the VUBUG debugger ROM.

#### roms/rom_testbench.asm

Assembly source code of the 1500+ test cases.

#### ucode/j68_ucode.asm

The J68 Forth-like microcode.

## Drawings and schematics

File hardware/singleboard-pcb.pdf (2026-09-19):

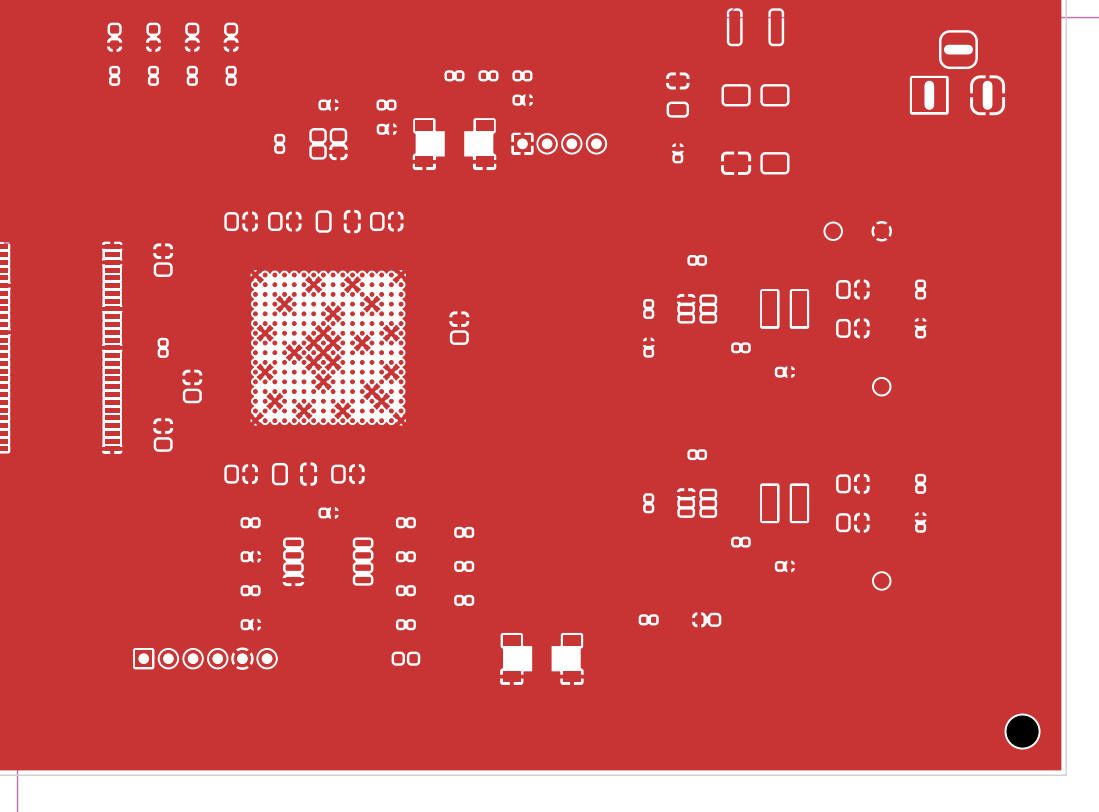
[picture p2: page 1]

Size: A4 | Rev:
KiCad E.D.A. 10.0.6 | Id: 1/7

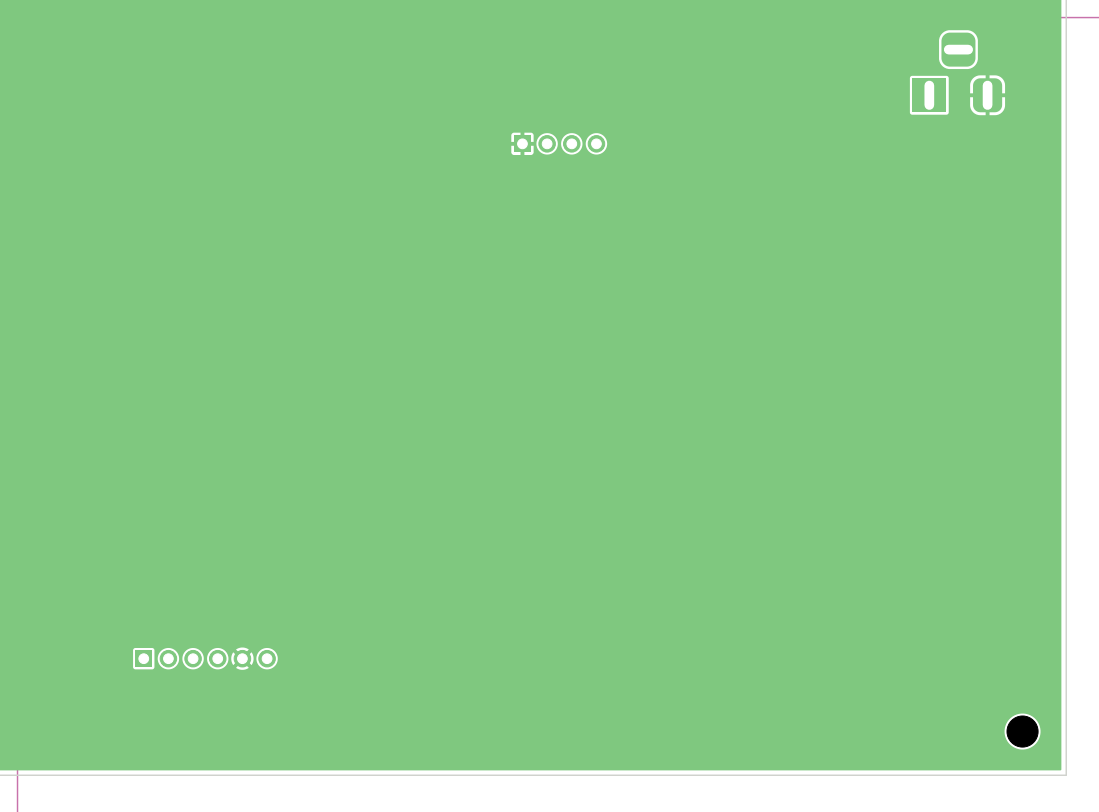
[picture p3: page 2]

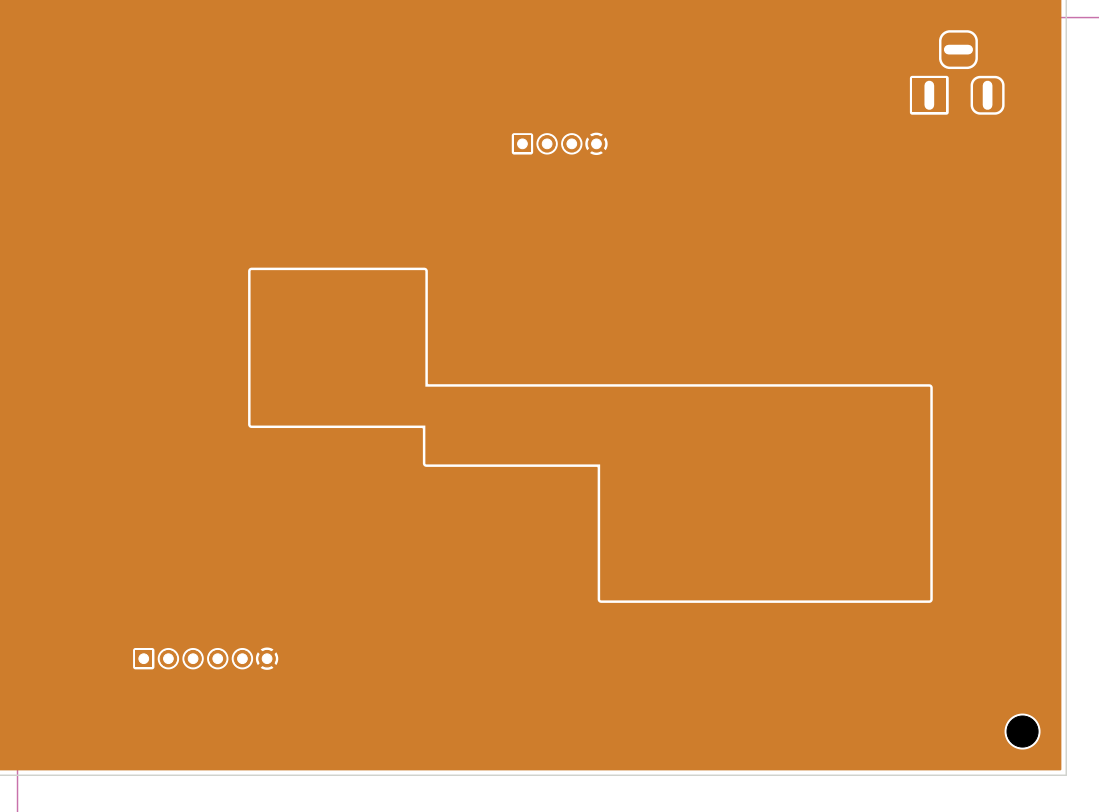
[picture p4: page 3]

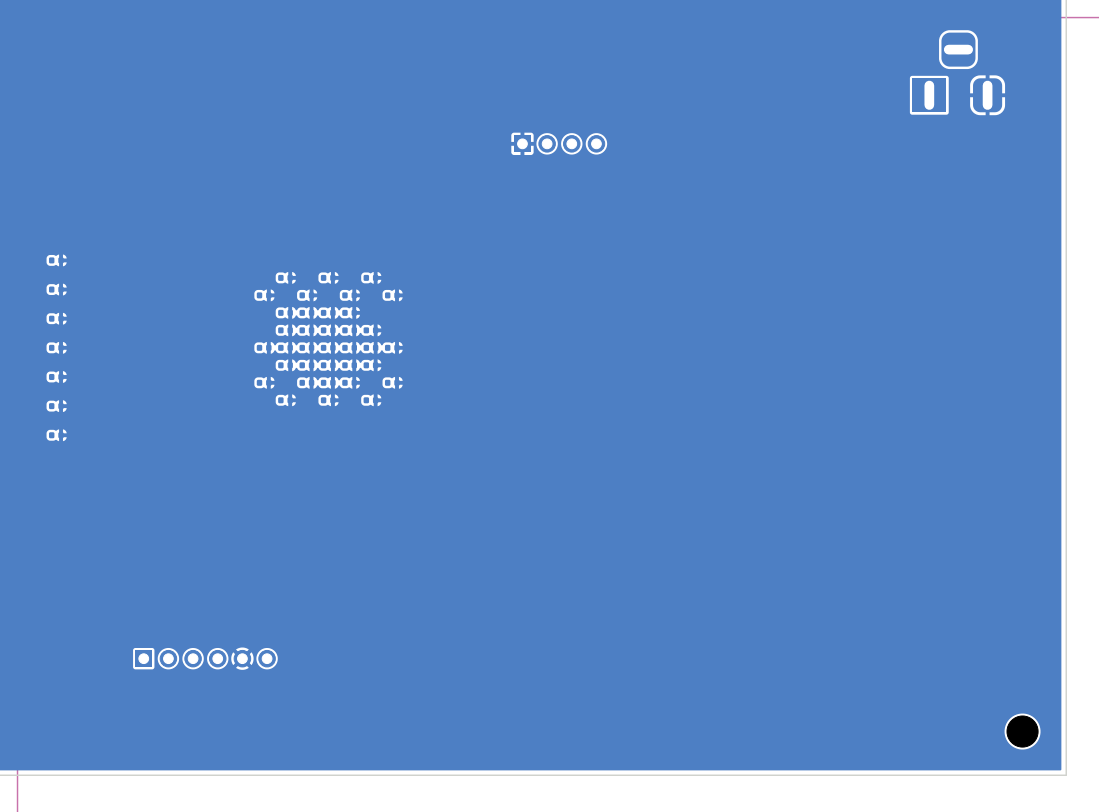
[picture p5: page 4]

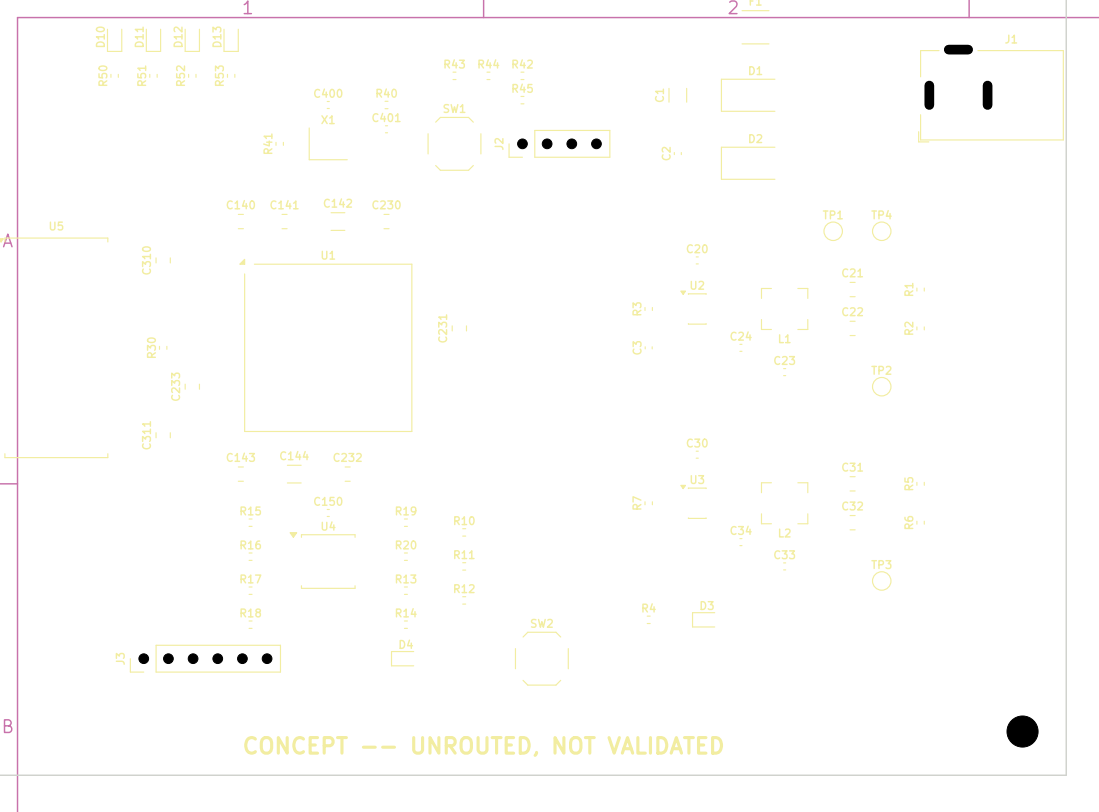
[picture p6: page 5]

XC6SLX16-FTG256 / MT48LC16M16A2 / rev A CONCEPT -- UNROUTED, NOT VALIDATED

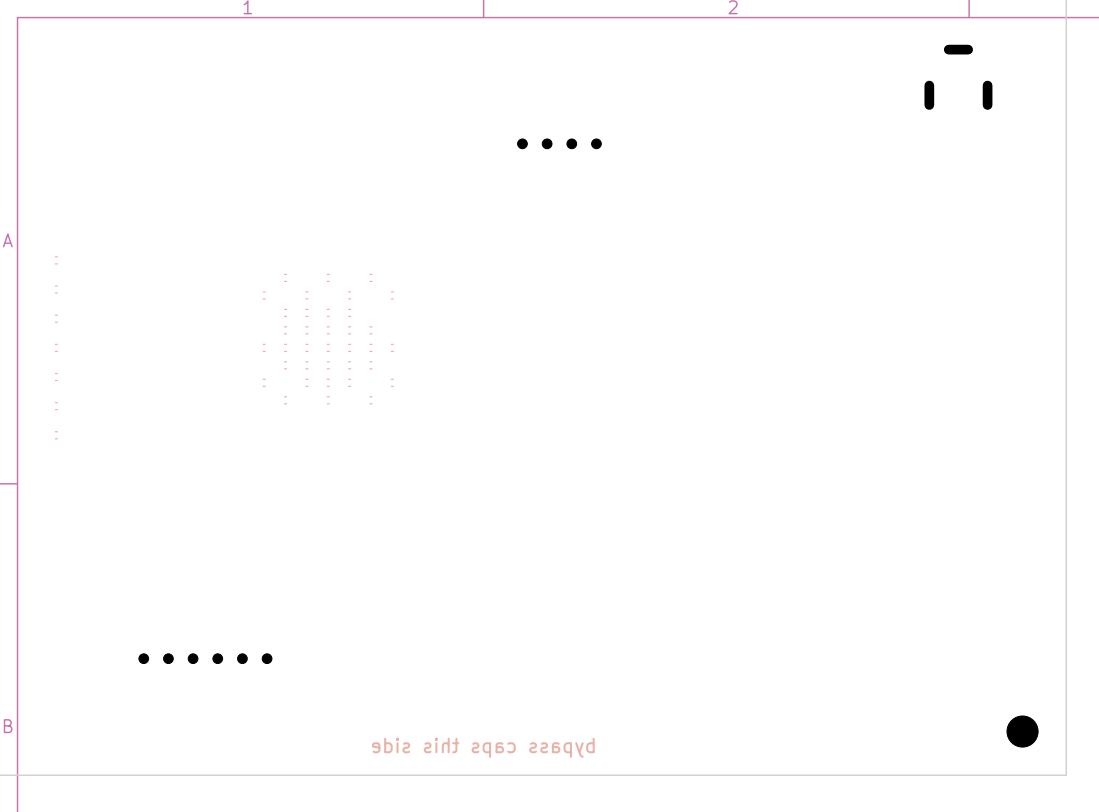
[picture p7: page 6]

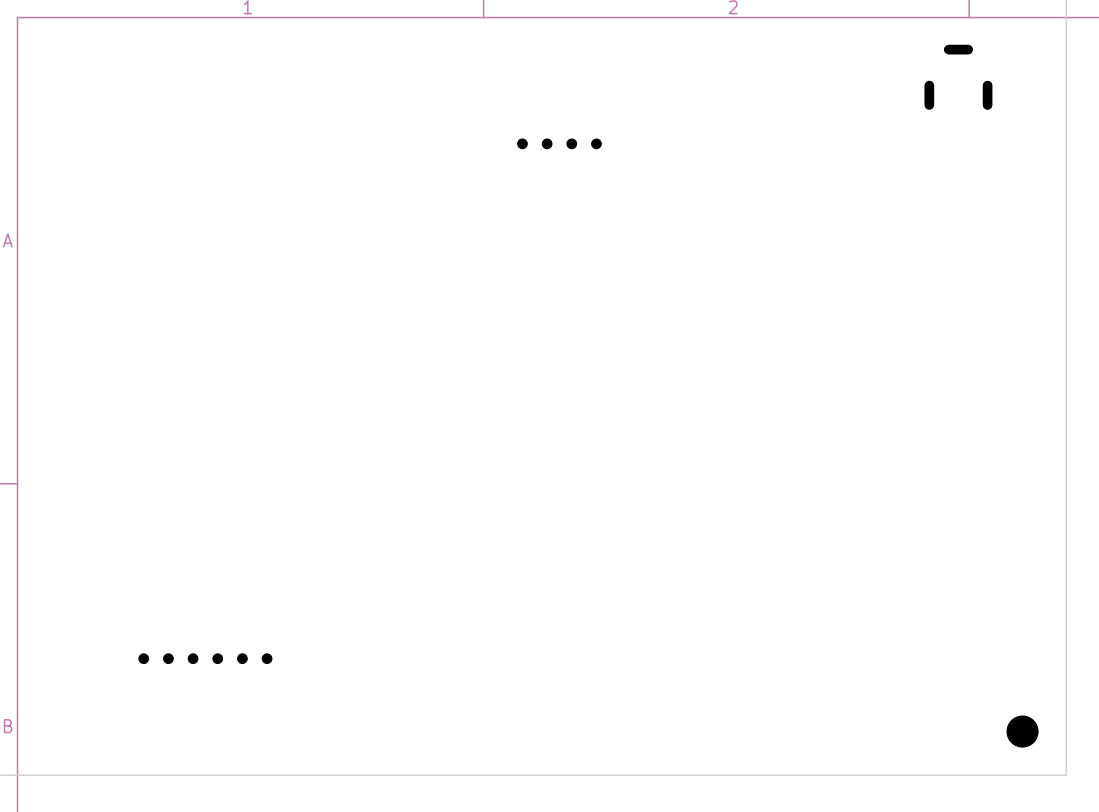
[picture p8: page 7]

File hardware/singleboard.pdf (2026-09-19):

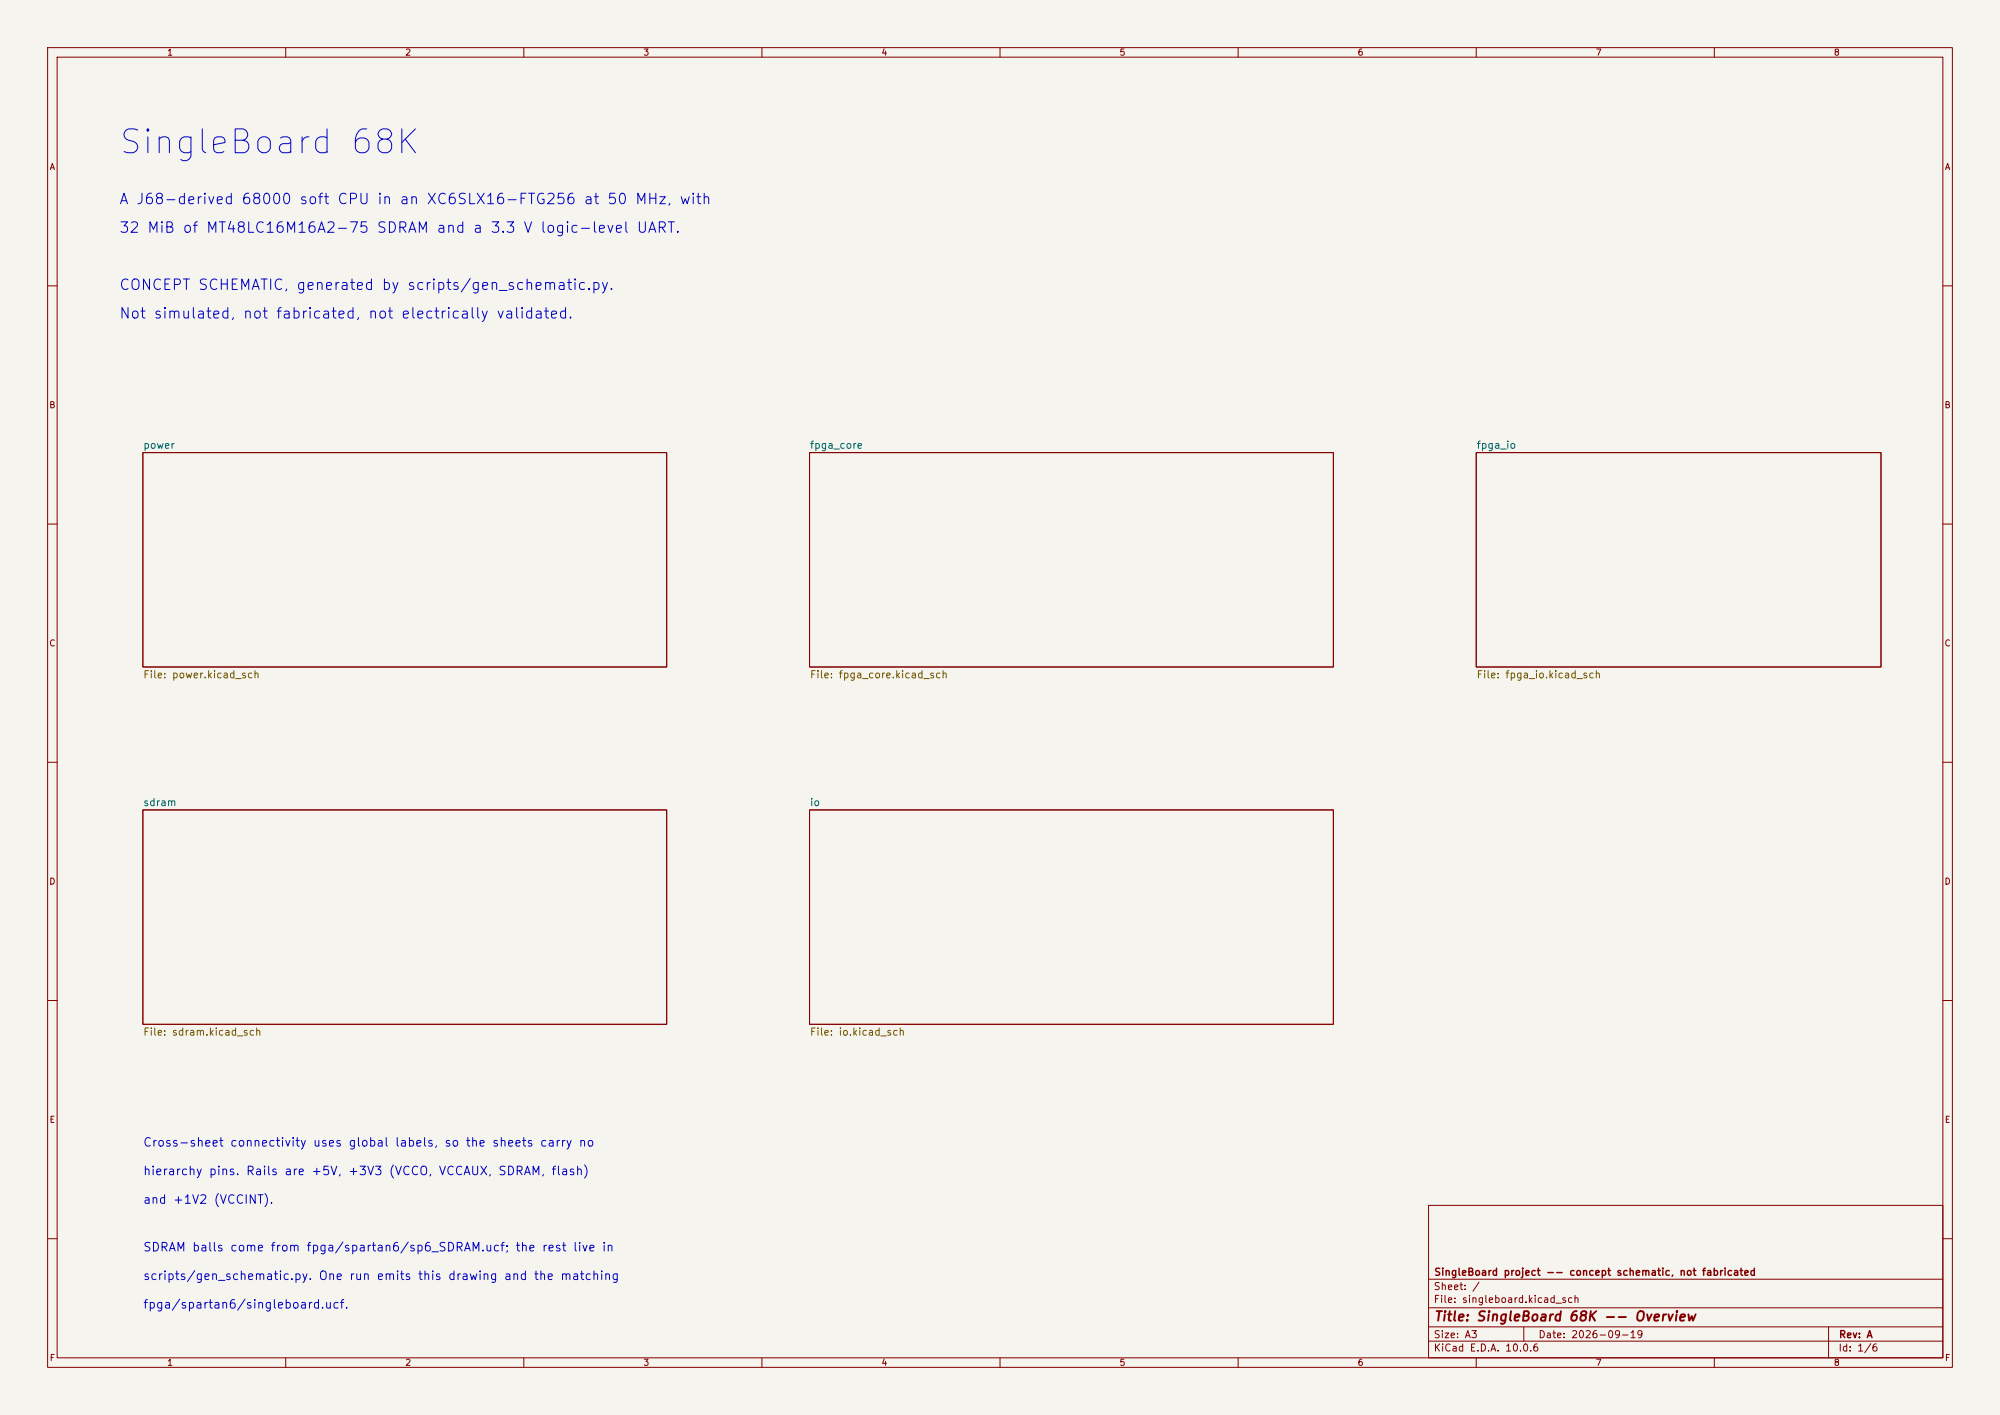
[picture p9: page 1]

A J68-derived 68000 soft CPU in an XC6SLX16-FTG256 at 50 MHz, with
32 MiB of MT48LC16M16A2-75 SDRAM and a 3.3 V logic-level UART.

CONCEPT SCHEMATIC, generated by scripts/gen_schematic.py.
Not simulated, not fabricated, not electrically validated.

Cross-sheet connectivity uses global labels, so the sheets carry no

hierarchy pins. Rails are +5V, +3V3 (VCCO, VCCAUX, SDRAM, flash)

SDRAM balls come from fpga/spartan6/sp6_SDRAM.ucf; the rest live in

scripts/gen_schematic.py. One run emits this drawing and the matching

SingleBoard project -- concept schematic, not fabricated
Sheet: /
File: singleboard.kicad_sch
Title: SingleBoard 68K -- Overview

Size: A3 | Rev: A | F Date: 2026-09-19
KiCad E.D.A. 10.0.6 | Id: 1/6

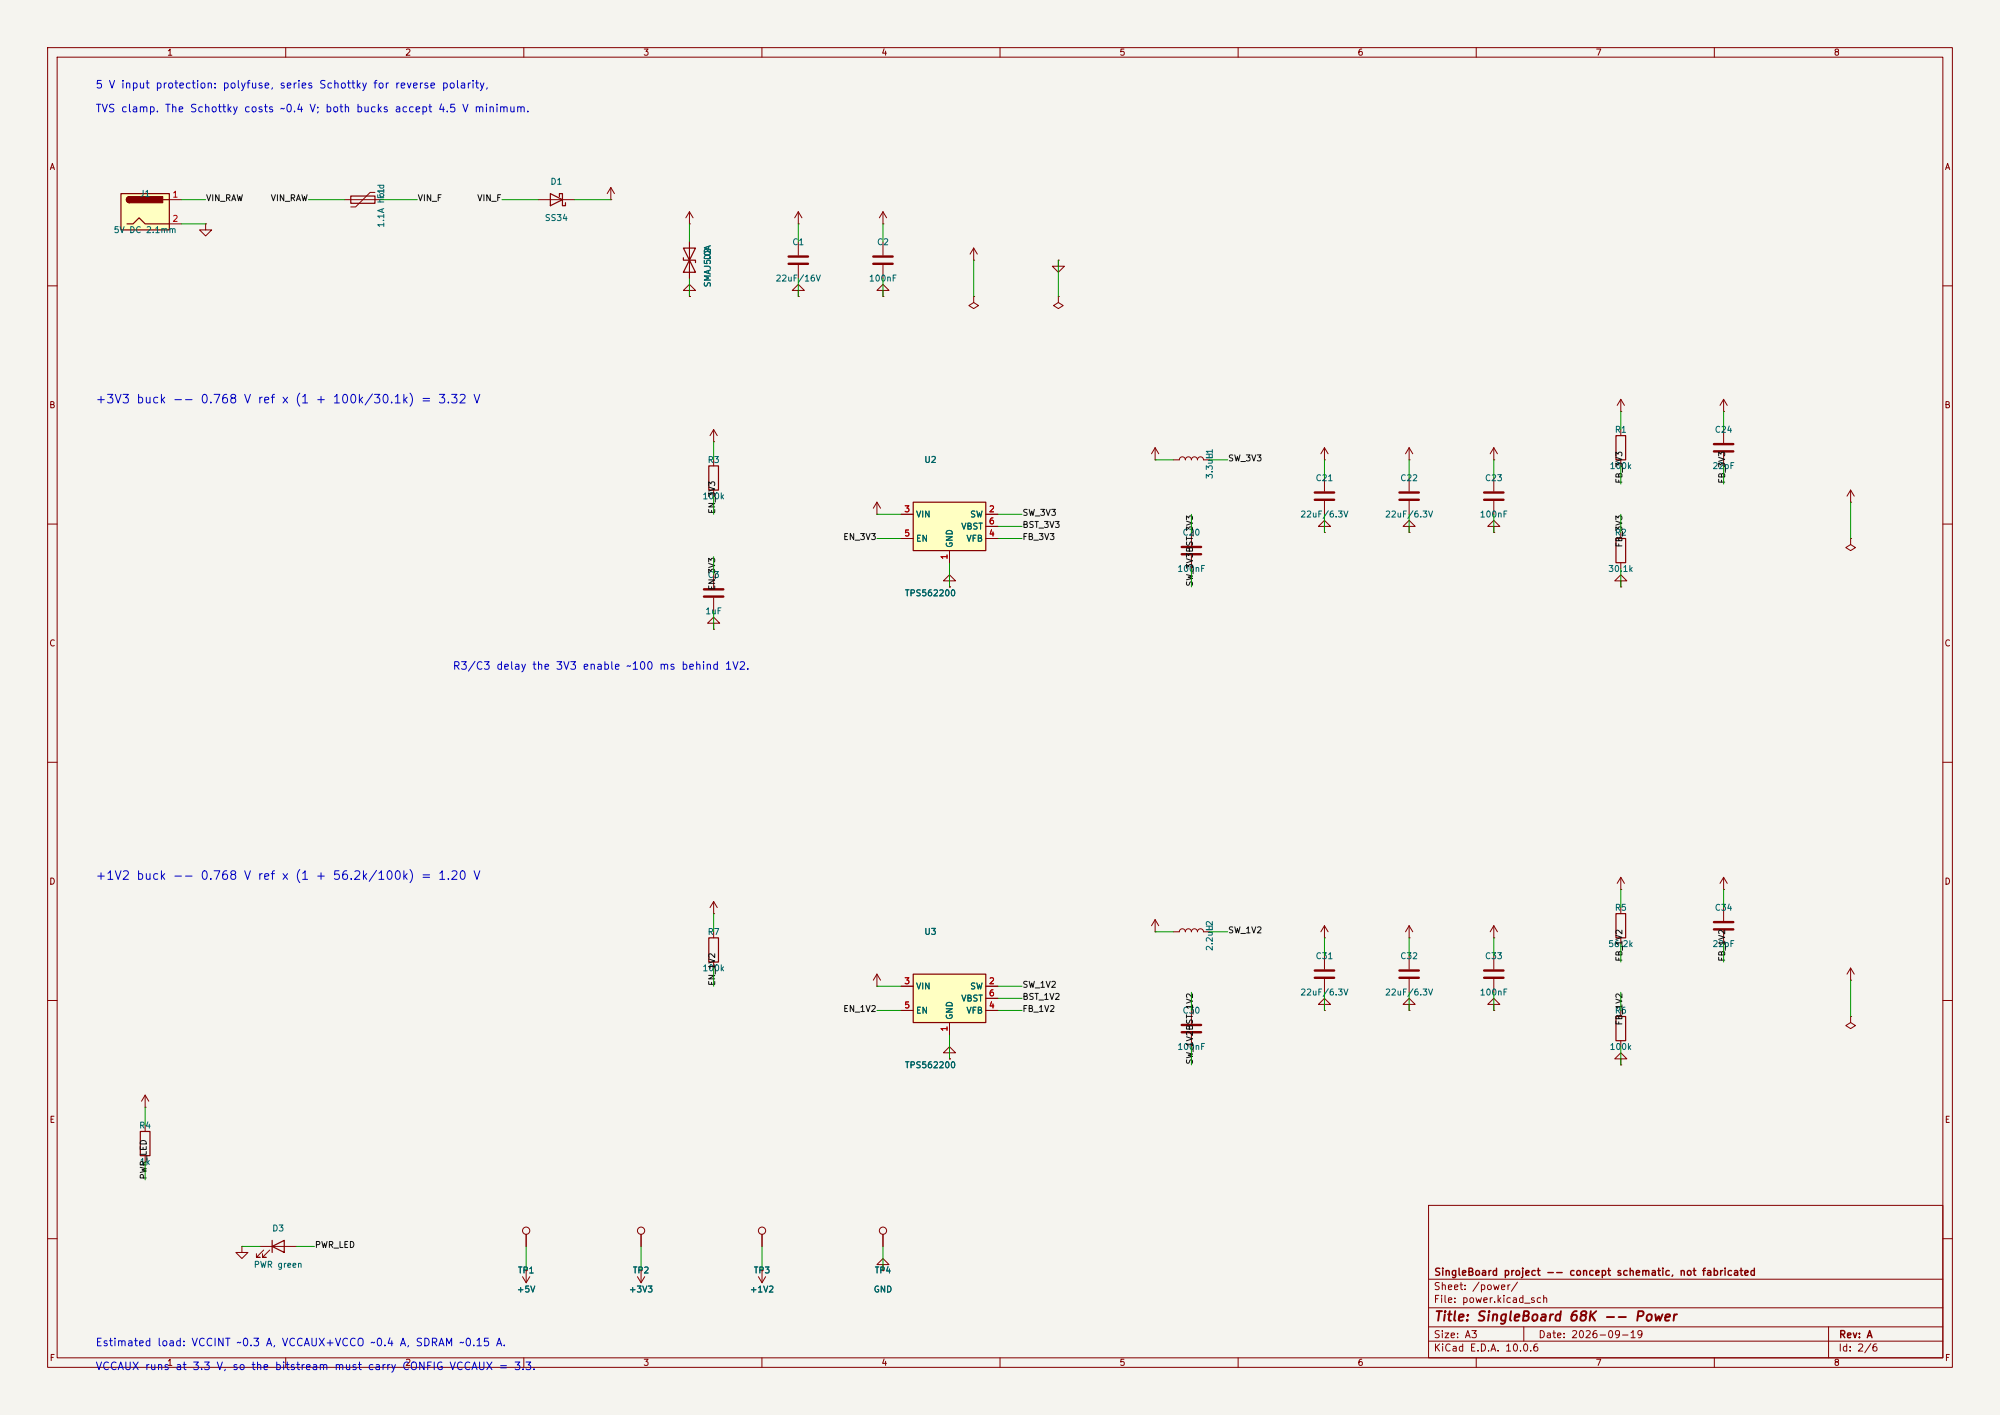
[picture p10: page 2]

5 V input protection: polyfuse, series Schottky for reverse polarity,

TVS clamp. The Schottky costs ~0.4 V; both bucks accept 4.5 V minimum.

R3/C3 delay the 3V3 enable ~100 ms behind 1V2.

SingleBoard project -- concept schematic, not fabricated
Sheet: /power/
File: power.kicad_sch
Title: SingleBoard 68K -- Power

Estimated load: VCCINT ~0.3 A, VCCAUX+VCCO ~0.4 A, SDRAM ~0.15 A.

VCCAUX runs at 3.3 V, so the bitstream must carry CONFIG VCCAUX = 3.3.

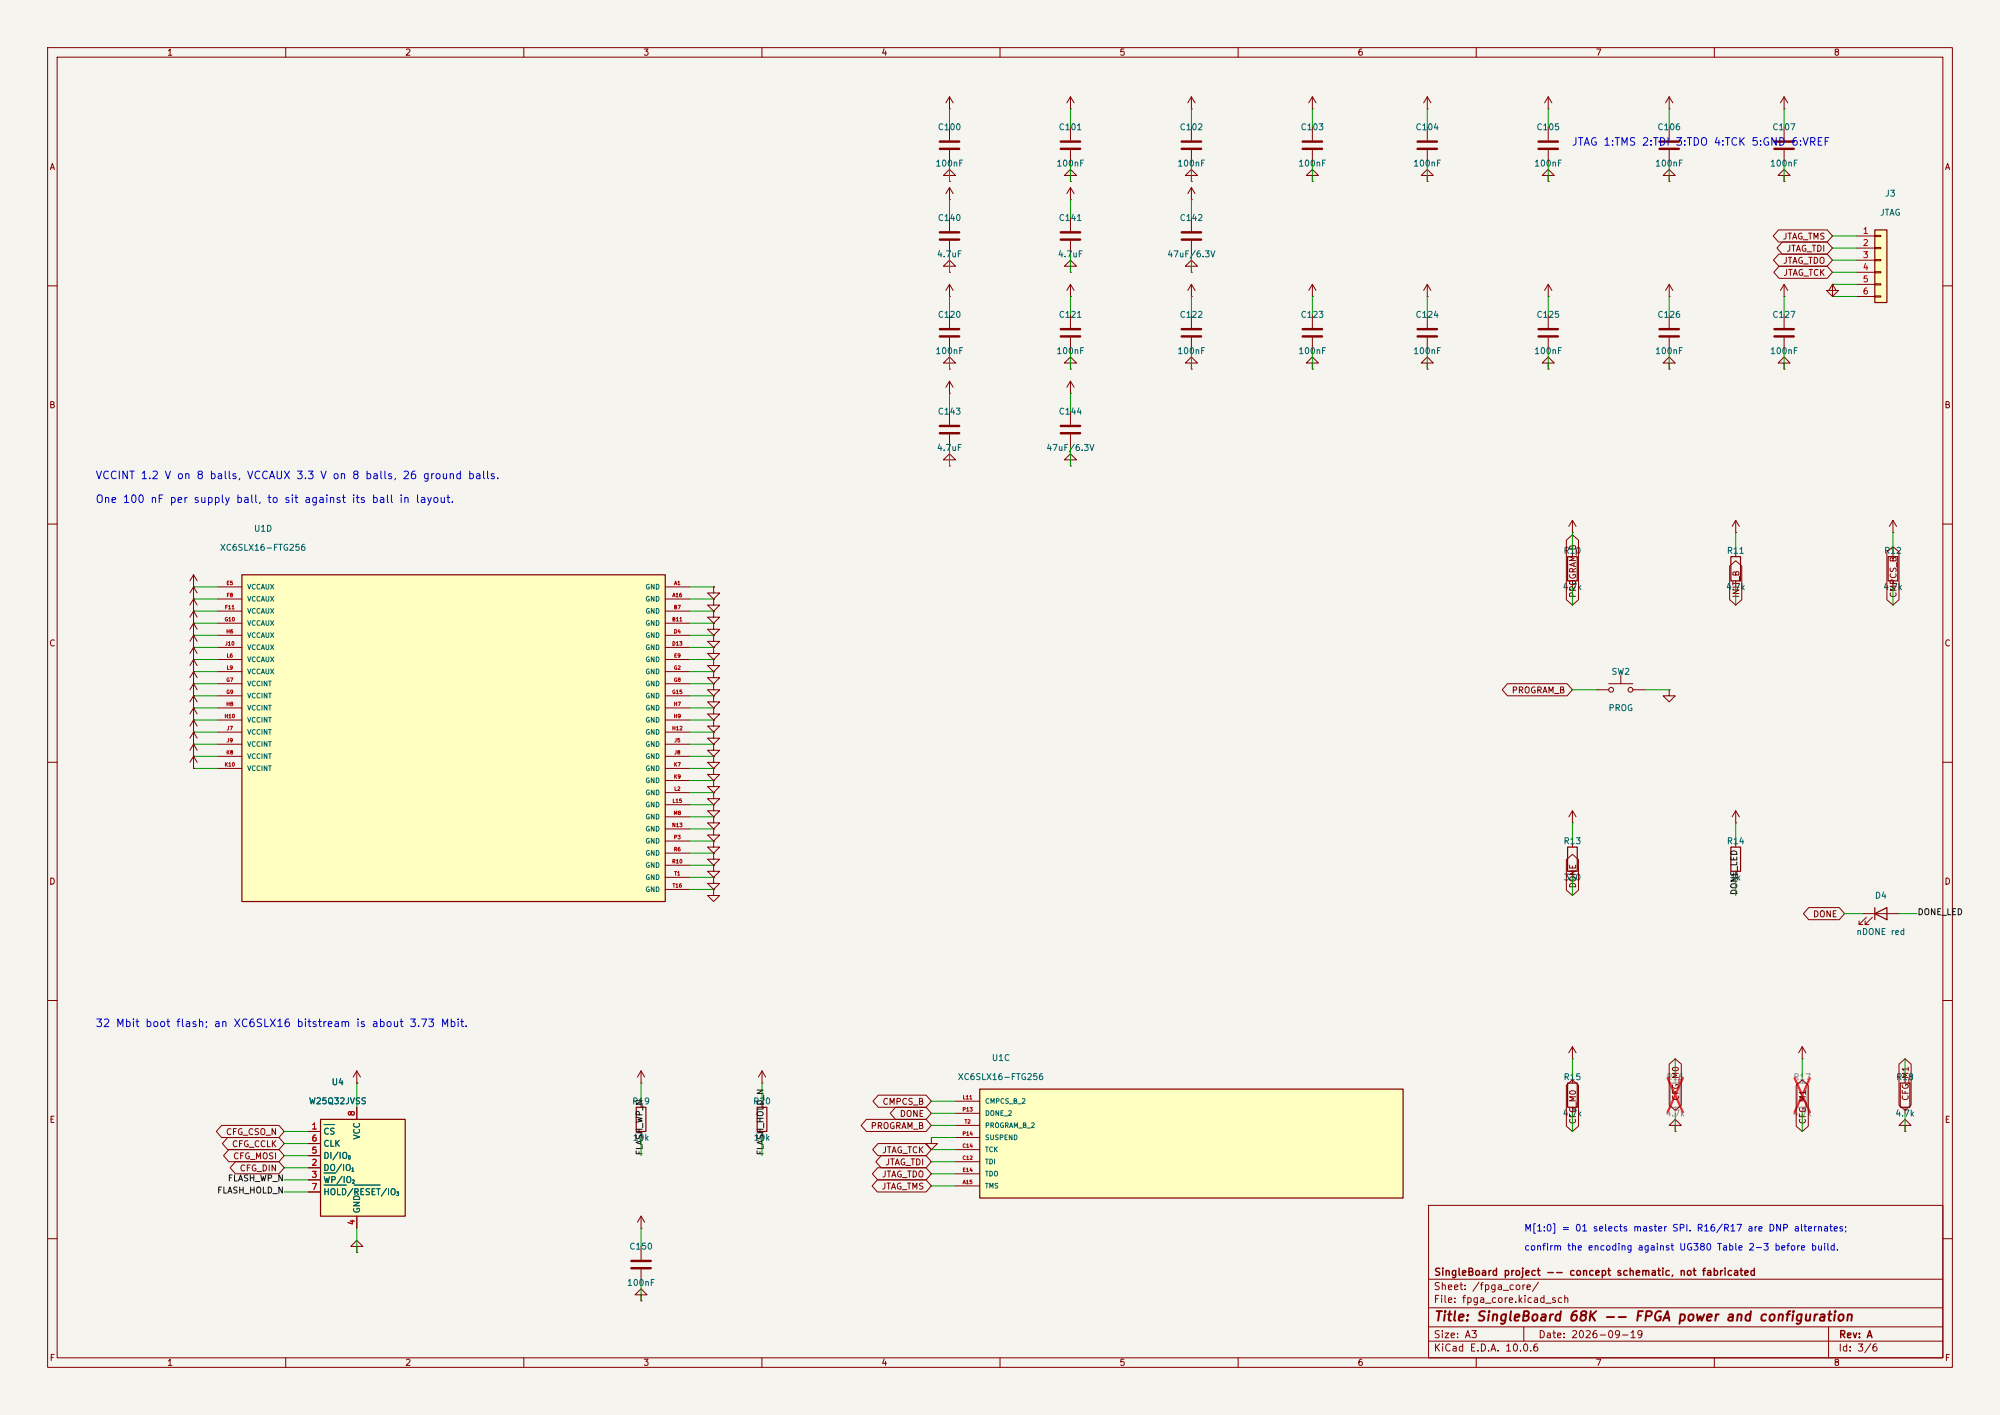
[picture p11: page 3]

JTAG 1:TMS 2:TDI 3:TDO 4:TCK 5:GND 6:VREF

VCCINT 1.2 V on 8 balls, VCCAUX 3.3 V on 8 balls, 26 ground balls.

One 100 nF per supply ball, to sit against its ball in layout.

4 DI/IO0 5 CLK 6 HOLD/RESET/IO3 7 VCC

SingleBoard project -- concept schematic, not fabricated
Sheet: /fpga_core/
File: fpga_core.kicad_sch
Title: SingleBoard 68K -- FPGA power and configuration

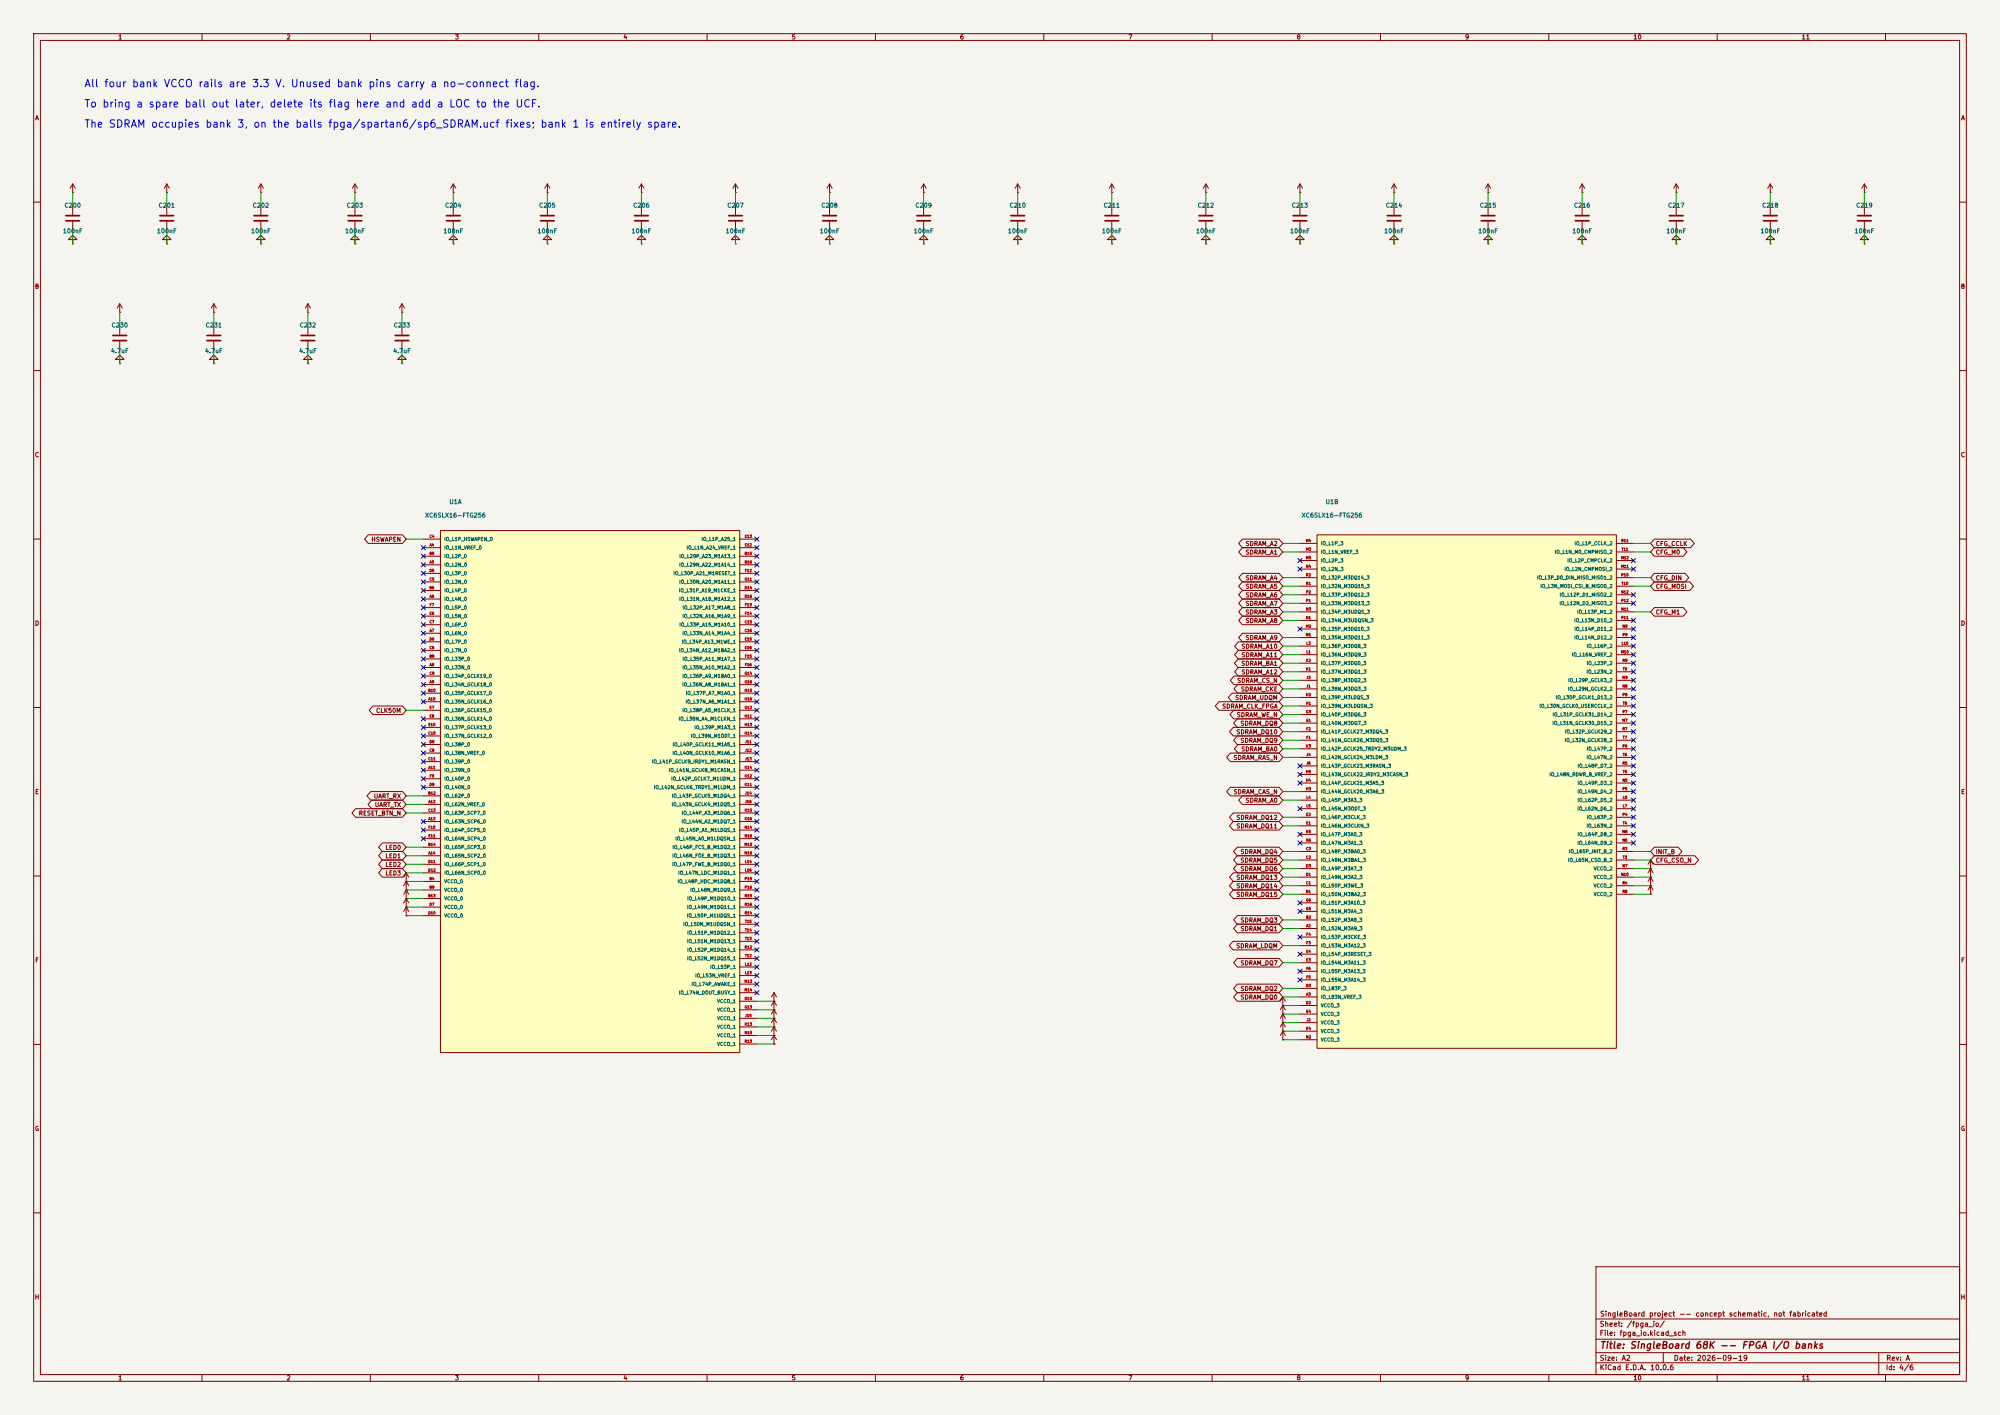
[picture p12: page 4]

All four bank VCCO rails are 3.3 V. Unused bank pins carry a no-connect flag.
To bring a spare ball out later, delete its flag here and add a LOC to the UCF.
The SDRAM occupies bank 3, on the balls fpga/spartan6/sp6_SDRAM.ucf fixes; bank 1 is entirely spare.

SingleBoard project -- concept schematic, not fabricated
Sheet: /fpga_io/
File: fpga_io.kicad_sch
Title: SingleBoard 68K -- FPGA I/O banks

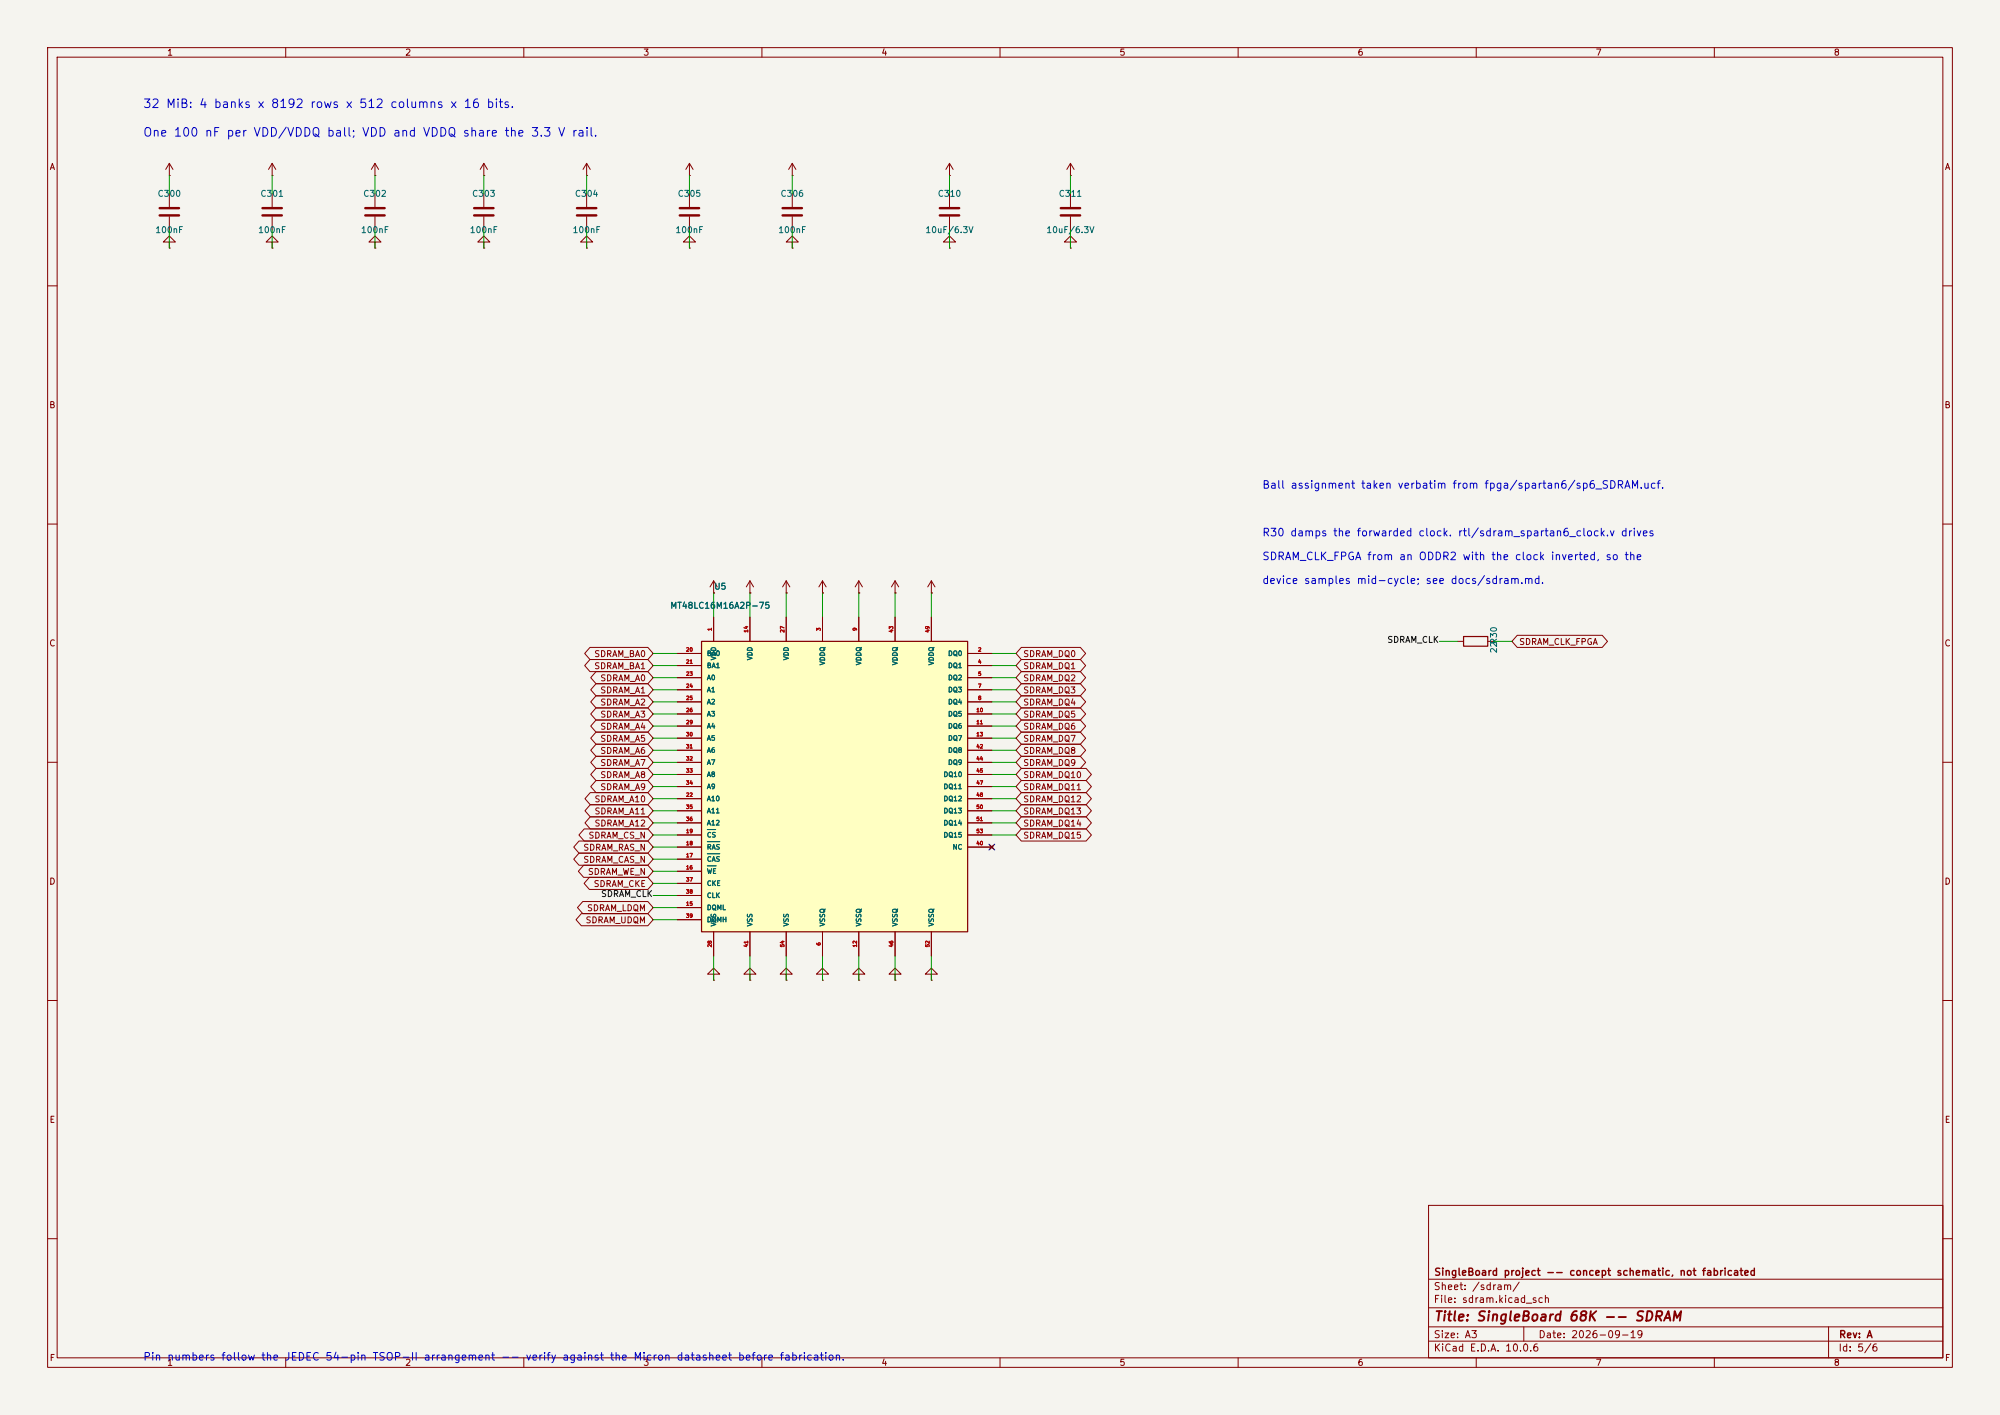
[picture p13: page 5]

One 100 nF per VDD/VDDQ ball; VDD and VDDQ share the 3.3 V rail.

9 DQ5 10 DQ6 11 VSSQ 12 DQ7 13 VDD 14 DQML 15 WE 16 CAS 17 RAS 18 CS 19 BA0 20 BA1 21 A10 22 A0 23 A1 24 A2 25 A3 26 VDD 27 VSS 28 A4 29 A5 30 A6 31 A7 32 A8 33 A9 34 A11 35 A12 36 CKE 37 CLK 38 DQMH 39 NC 40 VSS 41 DQ8 42 VDDQ 43 DQ9 44 DQ10 45 VSSQ 46 DQ11 47 DQ12 48 VDDQ 49 DQ13 50 DQ14 51 VSSQ 52 DQ15 53 VSS 54 U5 MT48LC16M16A2P-75 C310

Ball assignment taken verbatim from fpga/spartan6/sp6_SDRAM.ucf.

R30 damps the forwarded clock. rtl/sdram_spartan6_clock.v drives

SDRAM_CLK_FPGA from an ODDR2 with the clock inverted, so the

device samples mid-cycle; see docs/sdram.md.

SDRAM_CLK Pin numbers follow the JEDEC 54-pin TSOP-II arrangement -- verify against the Micron datasheet before fabrication.

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

SingleBoard project -- concept schematic, not fabricated
Sheet: /sdram/
File: sdram.kicad_sch
Title: SingleBoard 68K -- SDRAM


Active-low button. Synchronise and stretch it in the RTL: the CPU

50 MHz oscillator into GCLK ball E7; the UCF carries the 20 ns PERIOD.

reset must be held for at least two running clock edges. X1

Status LEDs, about 4 mA each, driven high-true from bank 0.

LED1_A J2 1:GND 2:TX board output 3:RX board input 4:3V3. 115200 8N1.

R43 idles RX high when nothing is plugged in.
LED0_A HDR_TX HDR_RX

HSWAPEN low keeps the configuration pull-ups enabled.

SingleBoard project -- concept schematic, not fabricated
Sheet: /io/
File: io.kicad_sch
Title: SingleBoard 68K -- Clock, UART, reset and LEDs

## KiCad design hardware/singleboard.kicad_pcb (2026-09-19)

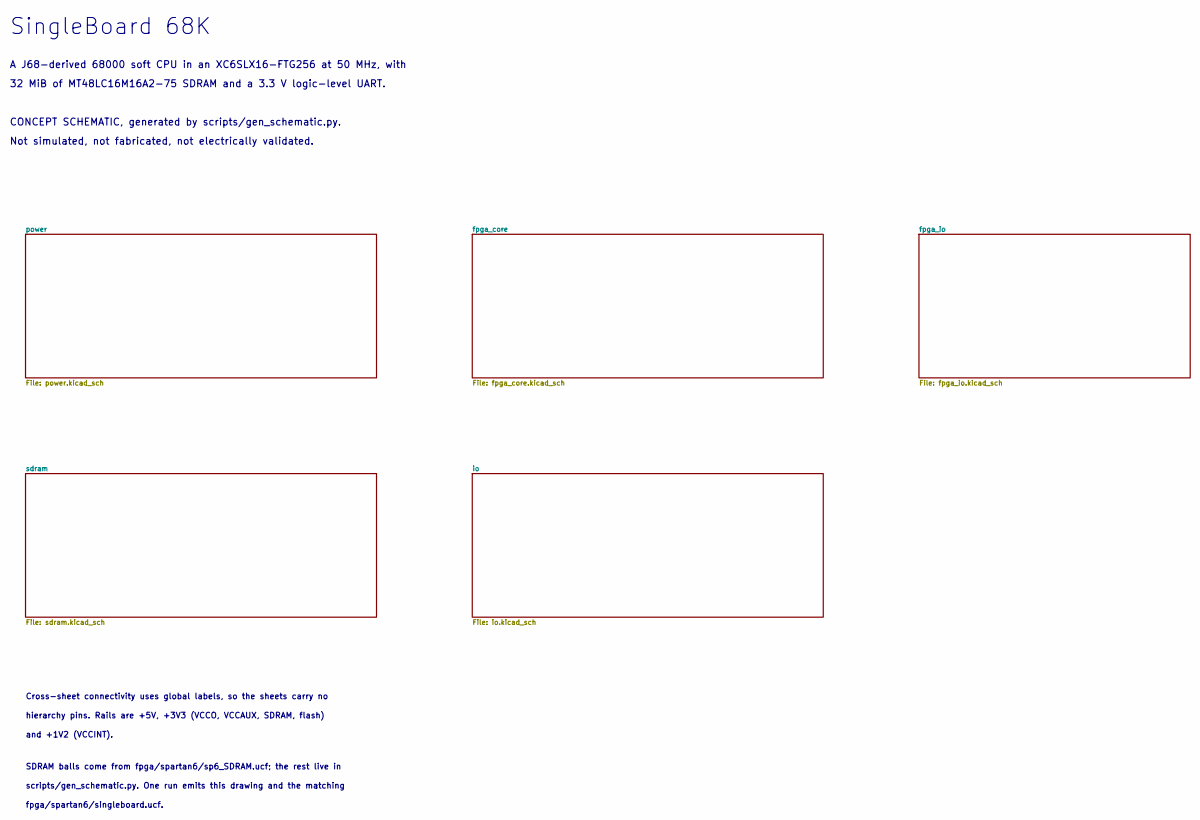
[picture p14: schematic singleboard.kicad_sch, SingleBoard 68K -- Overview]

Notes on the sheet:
SingleBoard 68K
A J68-derived 68000 soft CPU in an XC6SLX16-FTG256 at 50 MHz, with
32 MiB of MT48LC16M16A2-75 SDRAM and a 3.3 V logic-level UART.
CONCEPT SCHEMATIC, generated by scripts/gen_schematic.py.
Not simulated, not fabricated, not electrically validated.
Cross-sheet connectivity uses global labels, so the sheets carry no
hierarchy pins. Rails are +5V, +3V3 (VCCO, VCCAUX, SDRAM, flash)
and +1V2 (VCCINT).
SDRAM balls come from fpga/spartan6/sp6_SDRAM.ucf; the rest live in
scripts/gen_schematic.py. One run emits this drawing and the matching
fpga/spartan6/singleboard.ucf.

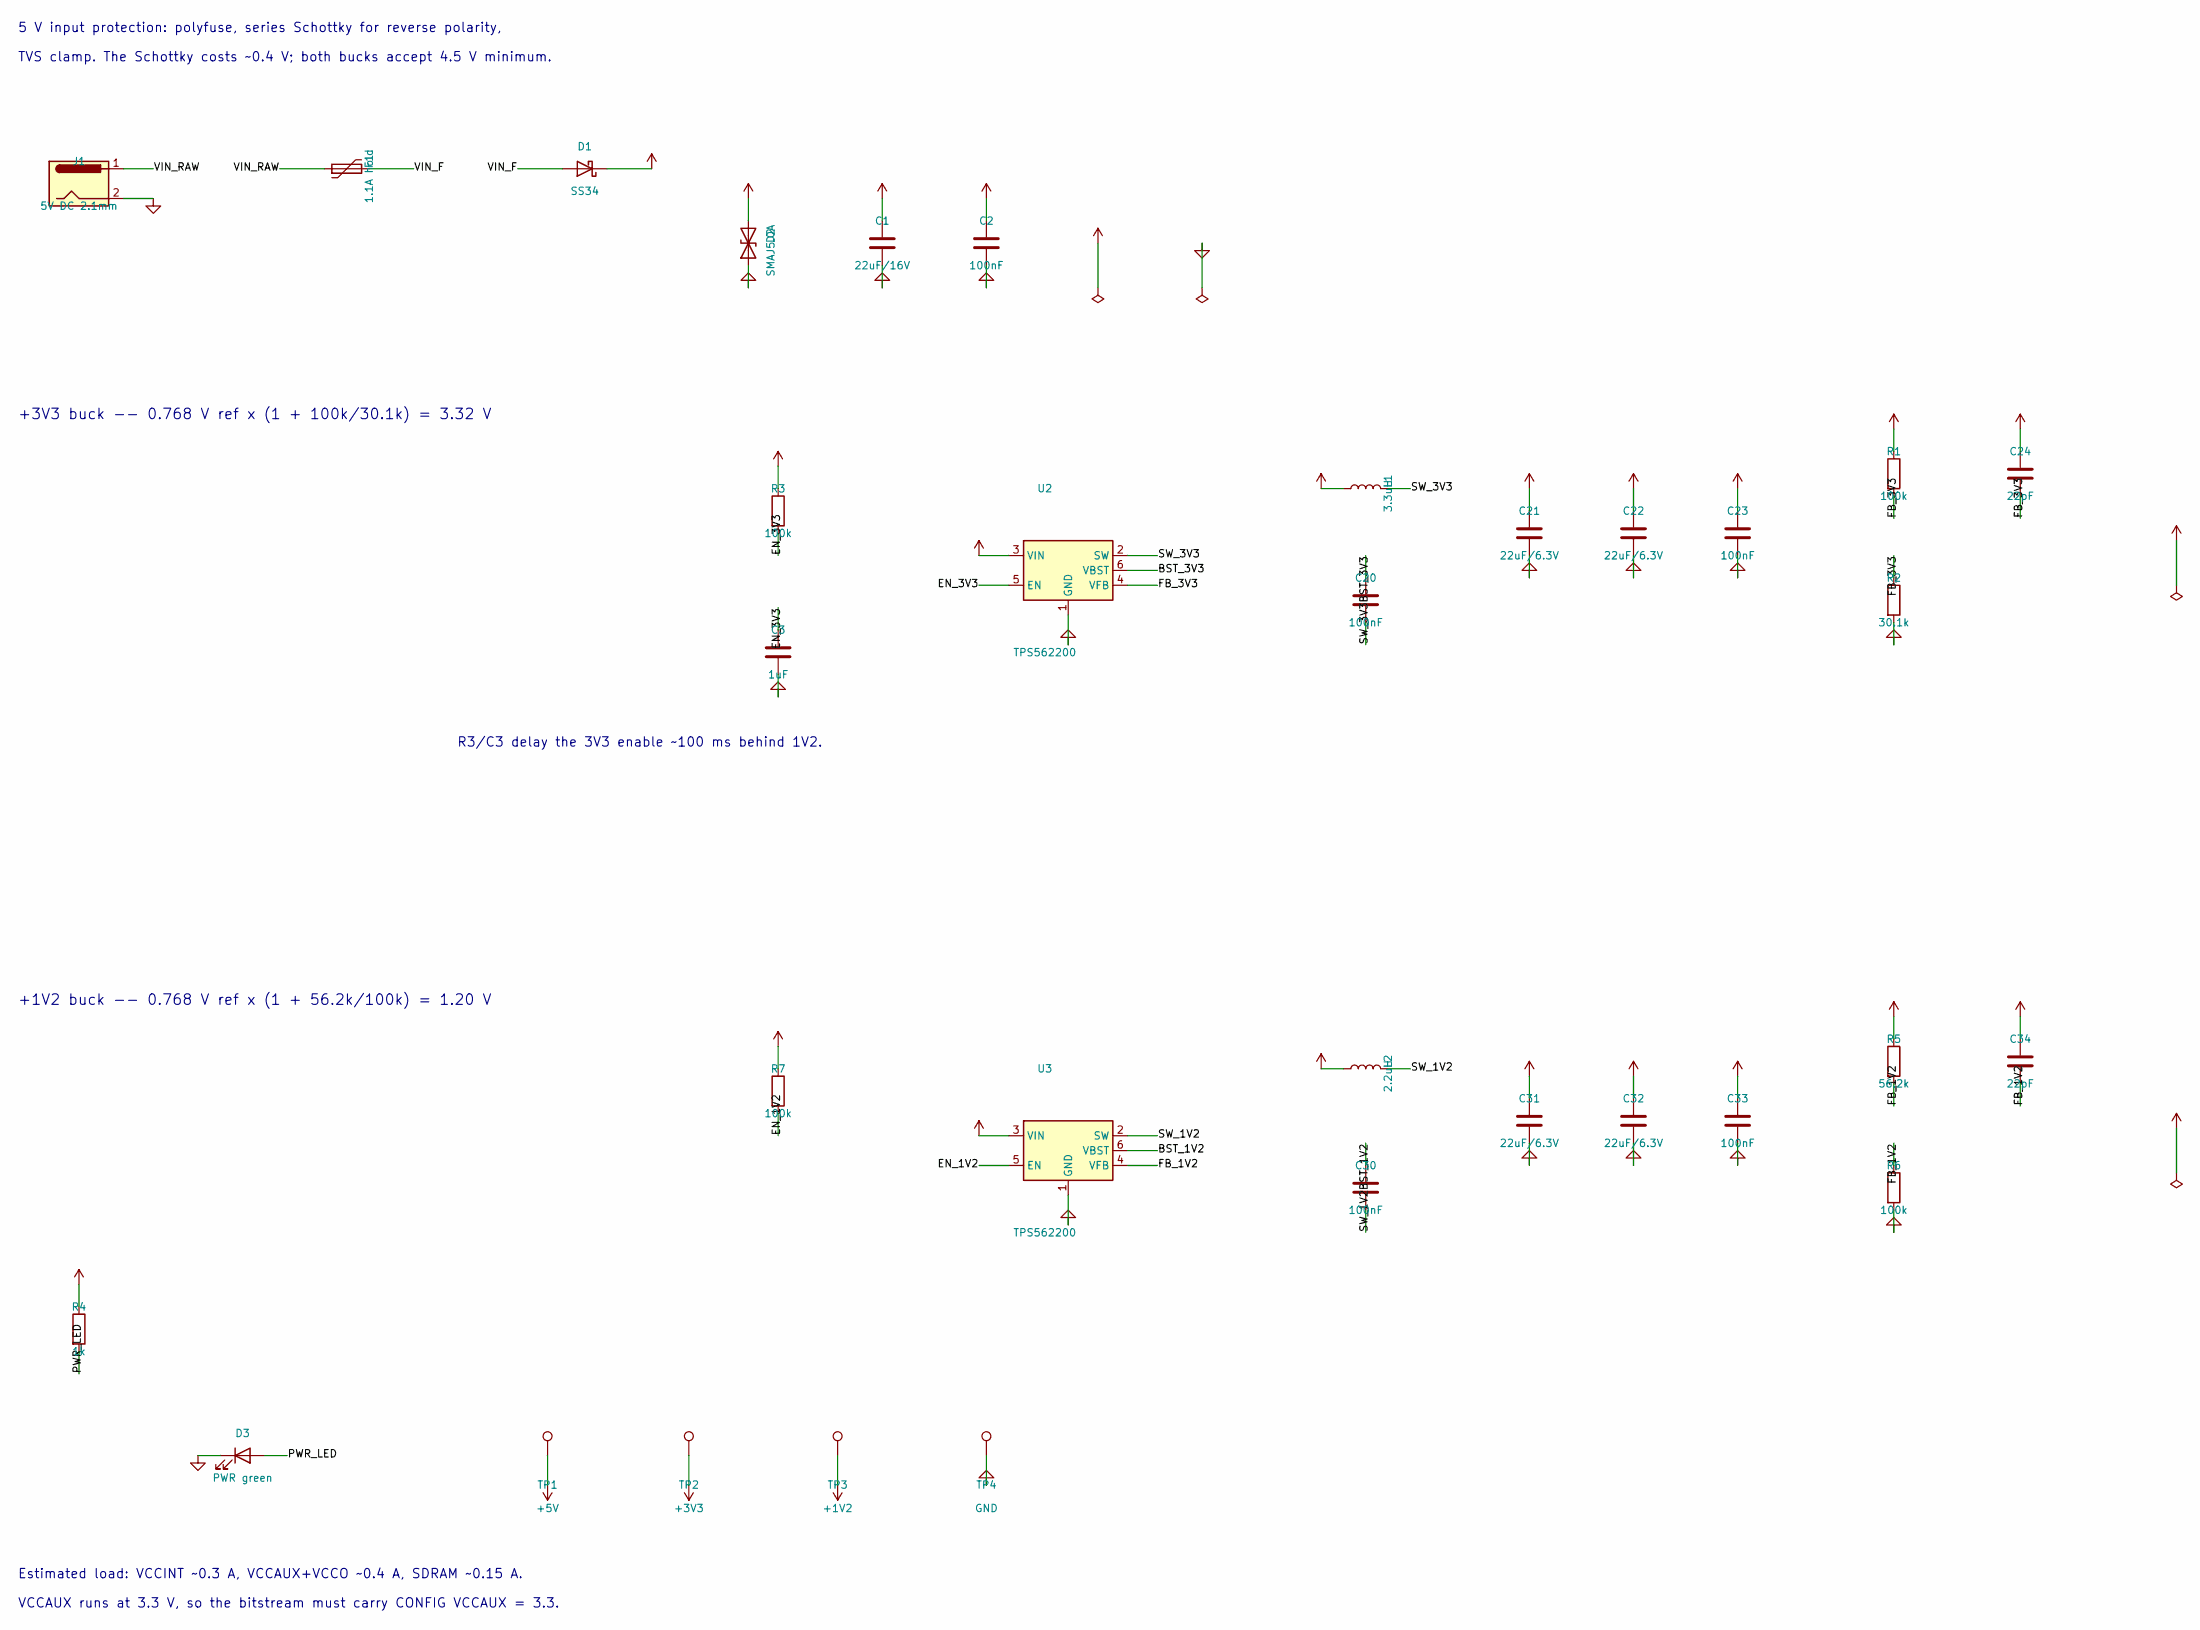
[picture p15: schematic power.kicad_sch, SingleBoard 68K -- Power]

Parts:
C1: 22uF/16V; C_1206_3216Metric
C2, C20, C23, C30, C33: 100nF; C_0402_1005Metric
C3: 1uF; C_0402_1005Metric
C21, C22, C31, C32: 22uF/6.3V; C_0805_2012Metric
C24, C34: 22pF; C_0402_1005Metric
D1: SS34; D_SMA
D2: SMAJ5.0A; D_SMA
D3: PWR green; LED_0603_1608Metric
F1: 1.1A hold; Fuse_1812_4532Metric
J1: 5V DC 2.1mm; BarrelJack_Horizontal
L1: 3.3uH; L_Bourns-SRN4018
L2: 2.2uH; L_Bourns-SRN4018
R1, R3, R6, R7: 100k; R_0402_1005Metric
R2: 30.1k; R_0402_1005Metric
R4: 1k; R_0402_1005Metric
R5: 56.2k; R_0402_1005Metric
TP1: +5V; TestPoint_Pad_D1.5mm
TP2: +3V3; TestPoint_Pad_D1.5mm
TP3: +1V2; TestPoint_Pad_D1.5mm
TP4: GND; TestPoint_Pad_D1.5mm
U2, U3: TPS562200; SOT-23-6

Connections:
+1V2: C31.1, C32.1, C33.1, C34.1, L2.1, R5.1, TP3.1; also elsewhere on the board
+3V3: C21.1, C22.1, C23.1, C24.1, L1.1, R1.1, R4.1, TP2.1; also elsewhere on the board
+5V: C1.1, C2.1, D1.1 (K), D2.2 (A2), R3.1, R7.1, TP1.1, U2.3 (VIN), U3.3 (VIN)
/power/BST_1V2: C30.1, U3.6 (VBST)
/power/BST_3V3: C20.1, U2.6 (VBST)
/power/EN_1V2: R7.2, U3.5 (EN)
/power/EN_3V3: C3.1, R3.2, U2.5 (EN)
/power/FB_1V2: C34.2, R5.2, R6.1, U3.4 (VFB)
/power/FB_3V3: C24.2, R1.2, R2.1, U2.4 (VFB)
/power/PWR_LED: D3.2 (A), R4.2
/power/SW_1V2: C30.2, L2.2, U3.2 (SW)
/power/SW_3V3: C20.2, L1.2, U2.2 (SW)
/power/VIN_F: D1.2 (A), F1.2
/power/VIN_RAW: F1.1, J1.1
GND: C1.2, C2.2, C3.2, C21.2, C22.2, C23.2, C31.2, C32.2, C33.2, D2.1 (A1), D3.1 (K), J1.2, R2.2, R6.2, TP4.1, U2.1 (GND), U3.1 (GND); also elsewhere on the board

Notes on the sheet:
5 V input protection: polyfuse, series Schottky for reverse polarity,
TVS clamp. The Schottky costs ~0.4 V; both bucks accept 4.5 V minimum.
+3V3 buck -- 0.768 V ref x (1 + 100k/30.1k) = 3.32 V
+1V2 buck -- 0.768 V ref x (1 + 56.2k/100k) = 1.20 V
R3/C3 delay the 3V3 enable ~100 ms behind 1V2.
Estimated load: VCCINT ~0.3 A, VCCAUX+VCCO ~0.4 A, SDRAM ~0.15 A.
VCCAUX runs at 3.3 V, so the bitstream must carry CONFIG VCCAUX = 3.3.

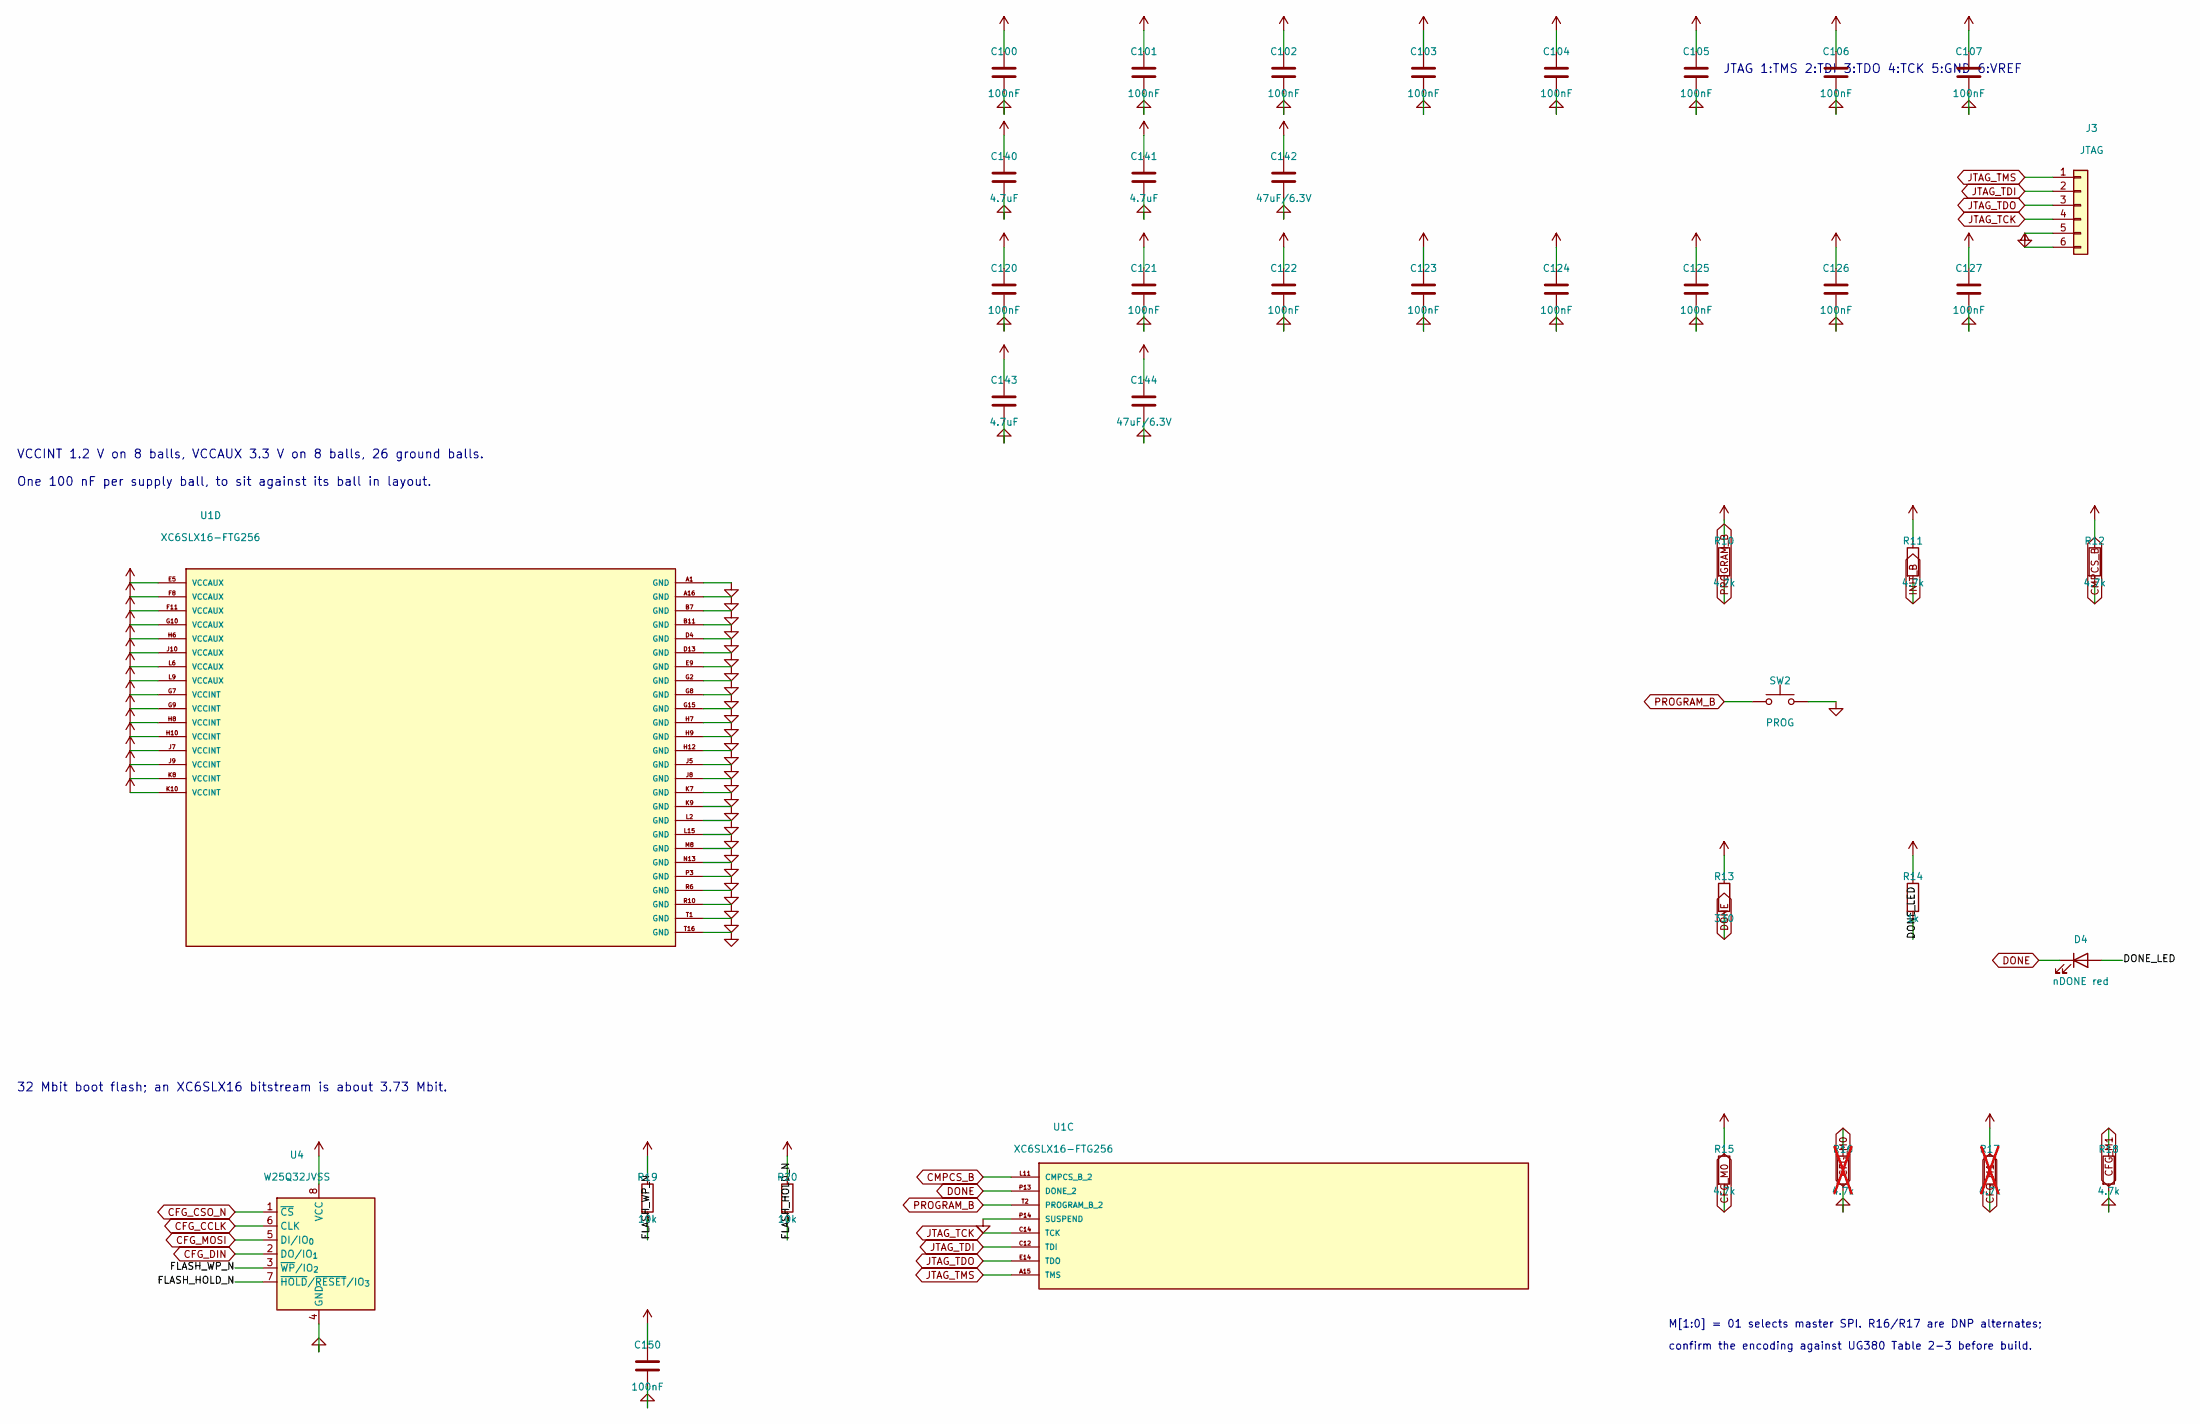
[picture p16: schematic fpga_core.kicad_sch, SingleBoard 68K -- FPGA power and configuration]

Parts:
C100, C101, C102, C103, C104, C105, C106, C107, C120, C121, C122, C123, C124, C125, C126, C127, C150: 100nF; C_0402_1005Metric
C140, C141, C143: 4.7uF; C_0805_2012Metric
C142, C144: 47uF/6.3V; C_1206_3216Metric
D4: nDONE red; LED_0603_1608Metric
J3: JTAG; PinHeader_1x06_P2.54mm_Vertical
R10, R11, R12, R15, R18: 4.7k; R_0402_1005Metric
R13: 330; R_0402_1005Metric
R14: 1k; R_0402_1005Metric
R16, R17: 4.7k; R_0402_1005Metric; not fitted
R19, R20: 10k; R_0402_1005Metric
SW2: PROG; SW_SPST_SKQG_WithStem
U1: XC6SLX16-FTG256; Xilinx_FTG256
U4: W25Q32JVSS; SOIC-8_5.3x5.3mm_P1.27mm

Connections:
+1V2: C100.1, C101.1, C102.1, C103.1, C104.1, C105.1, C106.1, C107.1, C140.1, C141.1, C142.1, U1.G7 (VCCINT), U1.G9 (VCCINT), U1.H8 (VCCINT), U1.H10 (VCCINT), U1.J7 (VCCINT), U1.J9 (VCCINT), U1.K8 (VCCINT), U1.K10 (VCCINT); also elsewhere on the board
+3V3: C120.1, C121.1, C122.1, C123.1, C124.1, C125.1, C126.1, C127.1, C143.1, C144.1, C150.1, J3.6, R10.1, R11.1, R12.1, R13.1, R14.1, R15.1, R17.1, R19.1, R20.1, U1.E5 (VCCAUX), U1.F8 (VCCAUX), U1.F11 (VCCAUX), U1.G10 (VCCAUX), U1.H6 (VCCAUX), U1.J10 (VCCAUX), U1.L6 (VCCAUX), U1.L9 (VCCAUX), U4.8 (VCC); also elsewhere on the board
/fpga_core/DONE_LED: D4.2 (A), R14.2
/fpga_core/FLASH_HOLD_N: R20.2, U4.7 (~HOLD/~RESET/IO_{3})
/fpga_core/FLASH_WP_N: R19.2, U4.3 (~WP/IO_{2})
CFG_CCLK: U4.6 (CLK); also elsewhere on the board
CFG_CSO_N: U4.1 (~CS); also elsewhere on the board
CFG_DIN: U4.2 (DO/IO_{1}); also elsewhere on the board
CFG_M0: R15.2, R16.1; also elsewhere on the board
CFG_M1: R17.2, R18.1; also elsewhere on the board
CFG_MOSI: U4.5 (DI/IO_{0}); also elsewhere on the board
CMPCS_B: R12.2, U1.L11 (CMPCS_B_2)
DONE: D4.1 (K), R13.2, U1.P13 (DONE_2)
GND: C100.2, C101.2, C102.2, C103.2, C104.2, C105.2, C106.2, C107.2, C120.2, C121.2, C122.2, C123.2, C124.2, C125.2, C126.2, C127.2, C140.2, C141.2, C142.2, C143.2, C144.2, C150.2, J3.5, R16.2, R18.2, SW2.2, U1.A1 (GND), U1.A16 (GND), U1.B7 (GND), U1.B11 (GND), U1.D4 (GND), U1.D13 (GND), U1.E9 (GND), U1.G2 (GND), U1.G8 (GND), U1.G15 (GND), U1.H7 (GND), U1.H9 (GND), U1.H12 (GND), U1.J5 (GND), U1.J8 (GND), U1.K7 (GND), U1.K9 (GND), U1.L2 (GND), U1.L15 (GND), U1.M8 (GND), U1.N13 (GND), U1.P3 (GND), U1.P14 (SUSPEND), U1.R6 (GND), U1.R10 (GND), U1.T1 (GND), U1.T16 (GND), U4.4 (GND); also elsewhere on the board
INIT_B: R11.2; also elsewhere on the board
JTAG_TCK: J3.4, U1.C14 (TCK)
JTAG_TDI: J3.2, U1.C12 (TDI)
JTAG_TDO: J3.3, U1.E14 (TDO)
JTAG_TMS: J3.1, U1.A15 (TMS)
PROGRAM_B: R10.2, SW2.1, U1.T2 (PROGRAM_B_2)

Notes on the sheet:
VCCINT 1.2 V on 8 balls, VCCAUX 3.3 V on 8 balls, 26 ground balls.
One 100 nF per supply ball, to sit against its ball in layout.
M[1:0] = 01 selects master SPI. R16/R17 are DNP alternates;
confirm the encoding against UG380 Table 2-3 before build.
32 Mbit boot flash; an XC6SLX16 bitstream is about 3.73 Mbit.
JTAG 1:TMS 2:TDI 3:TDO 4:TCK 5:GND 6:VREF

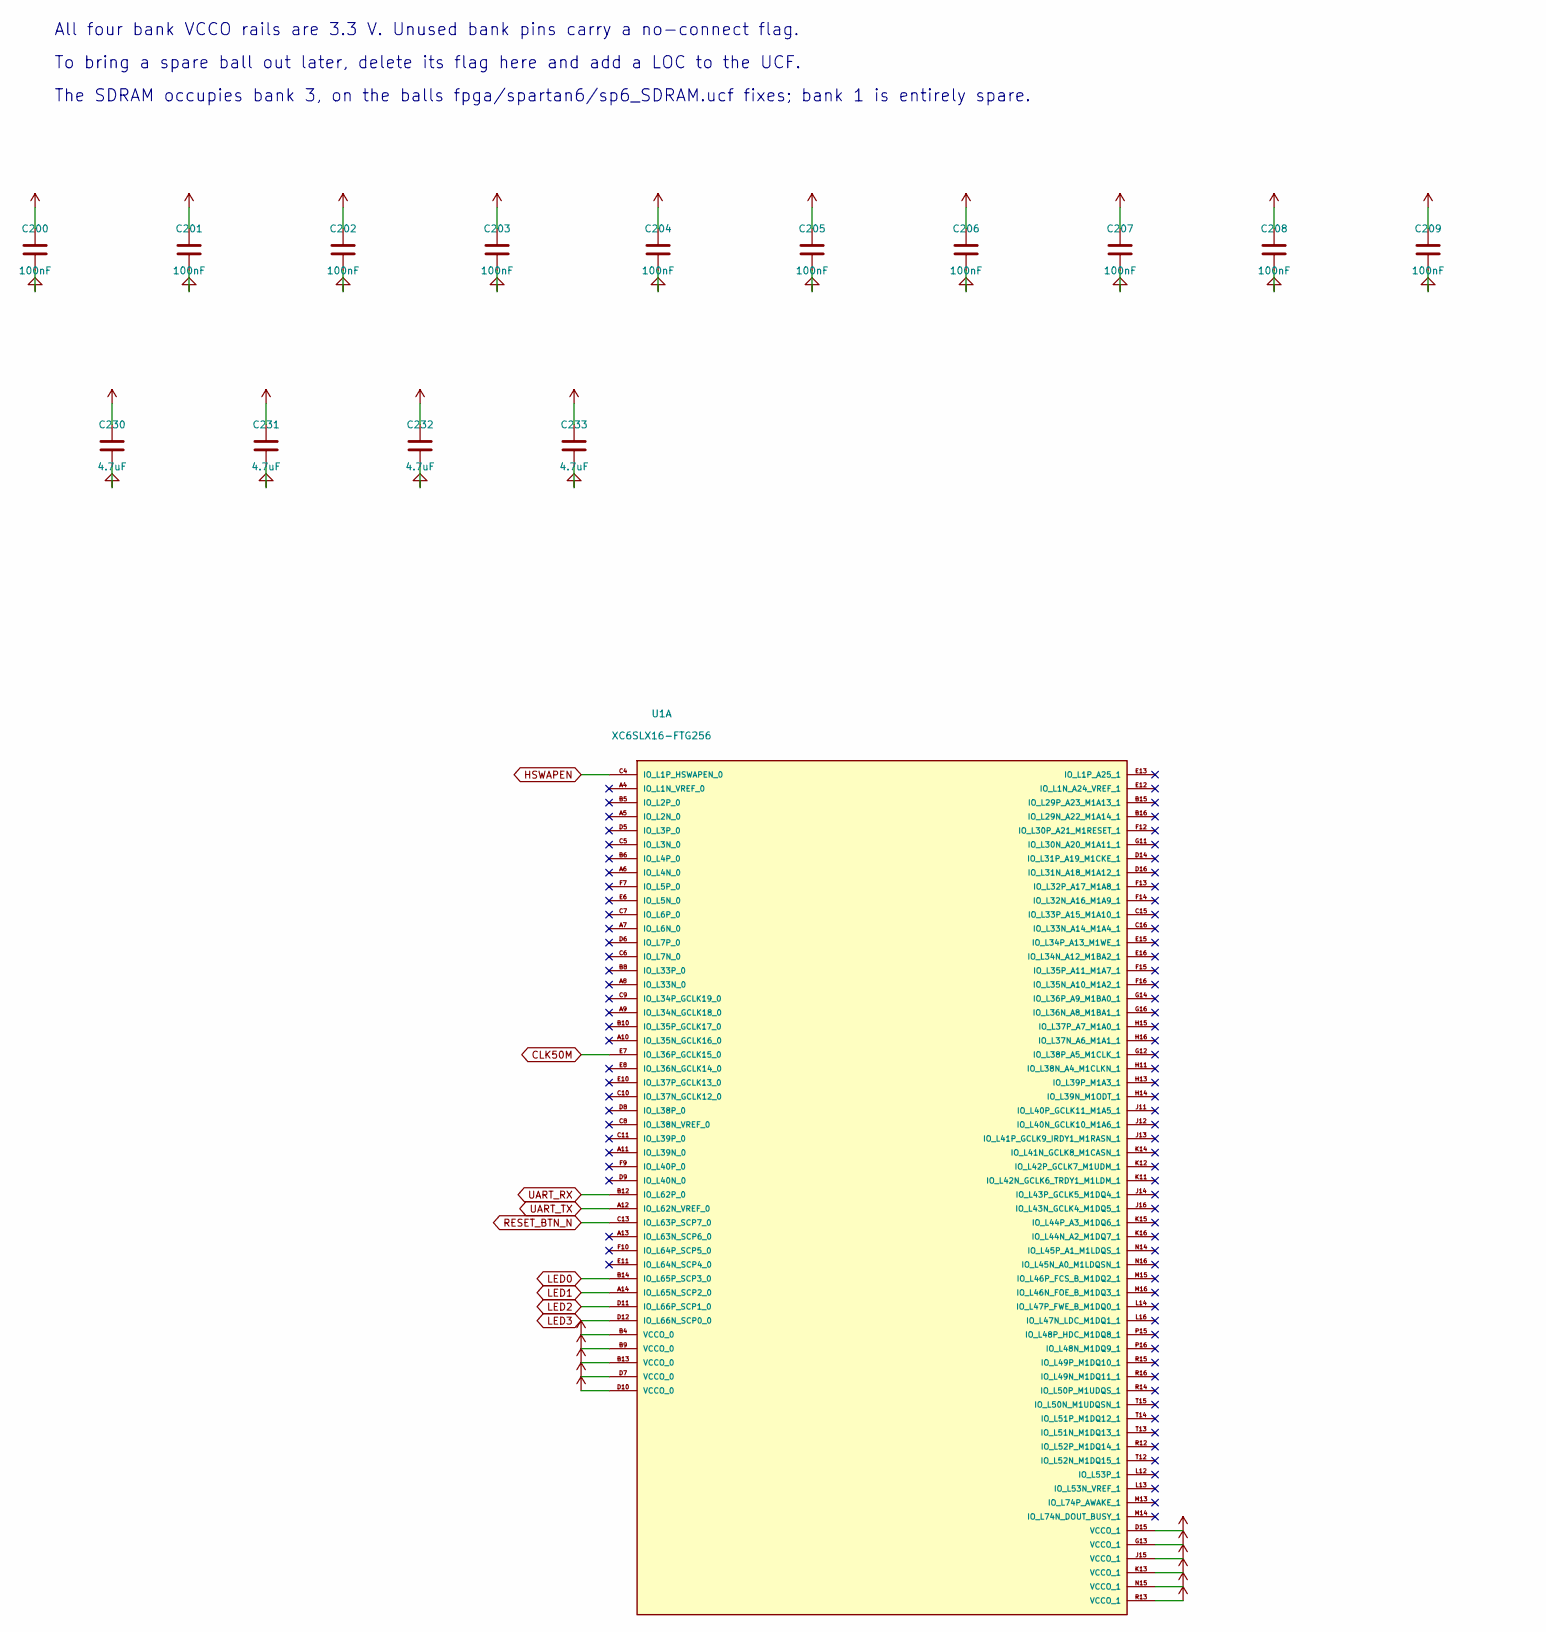
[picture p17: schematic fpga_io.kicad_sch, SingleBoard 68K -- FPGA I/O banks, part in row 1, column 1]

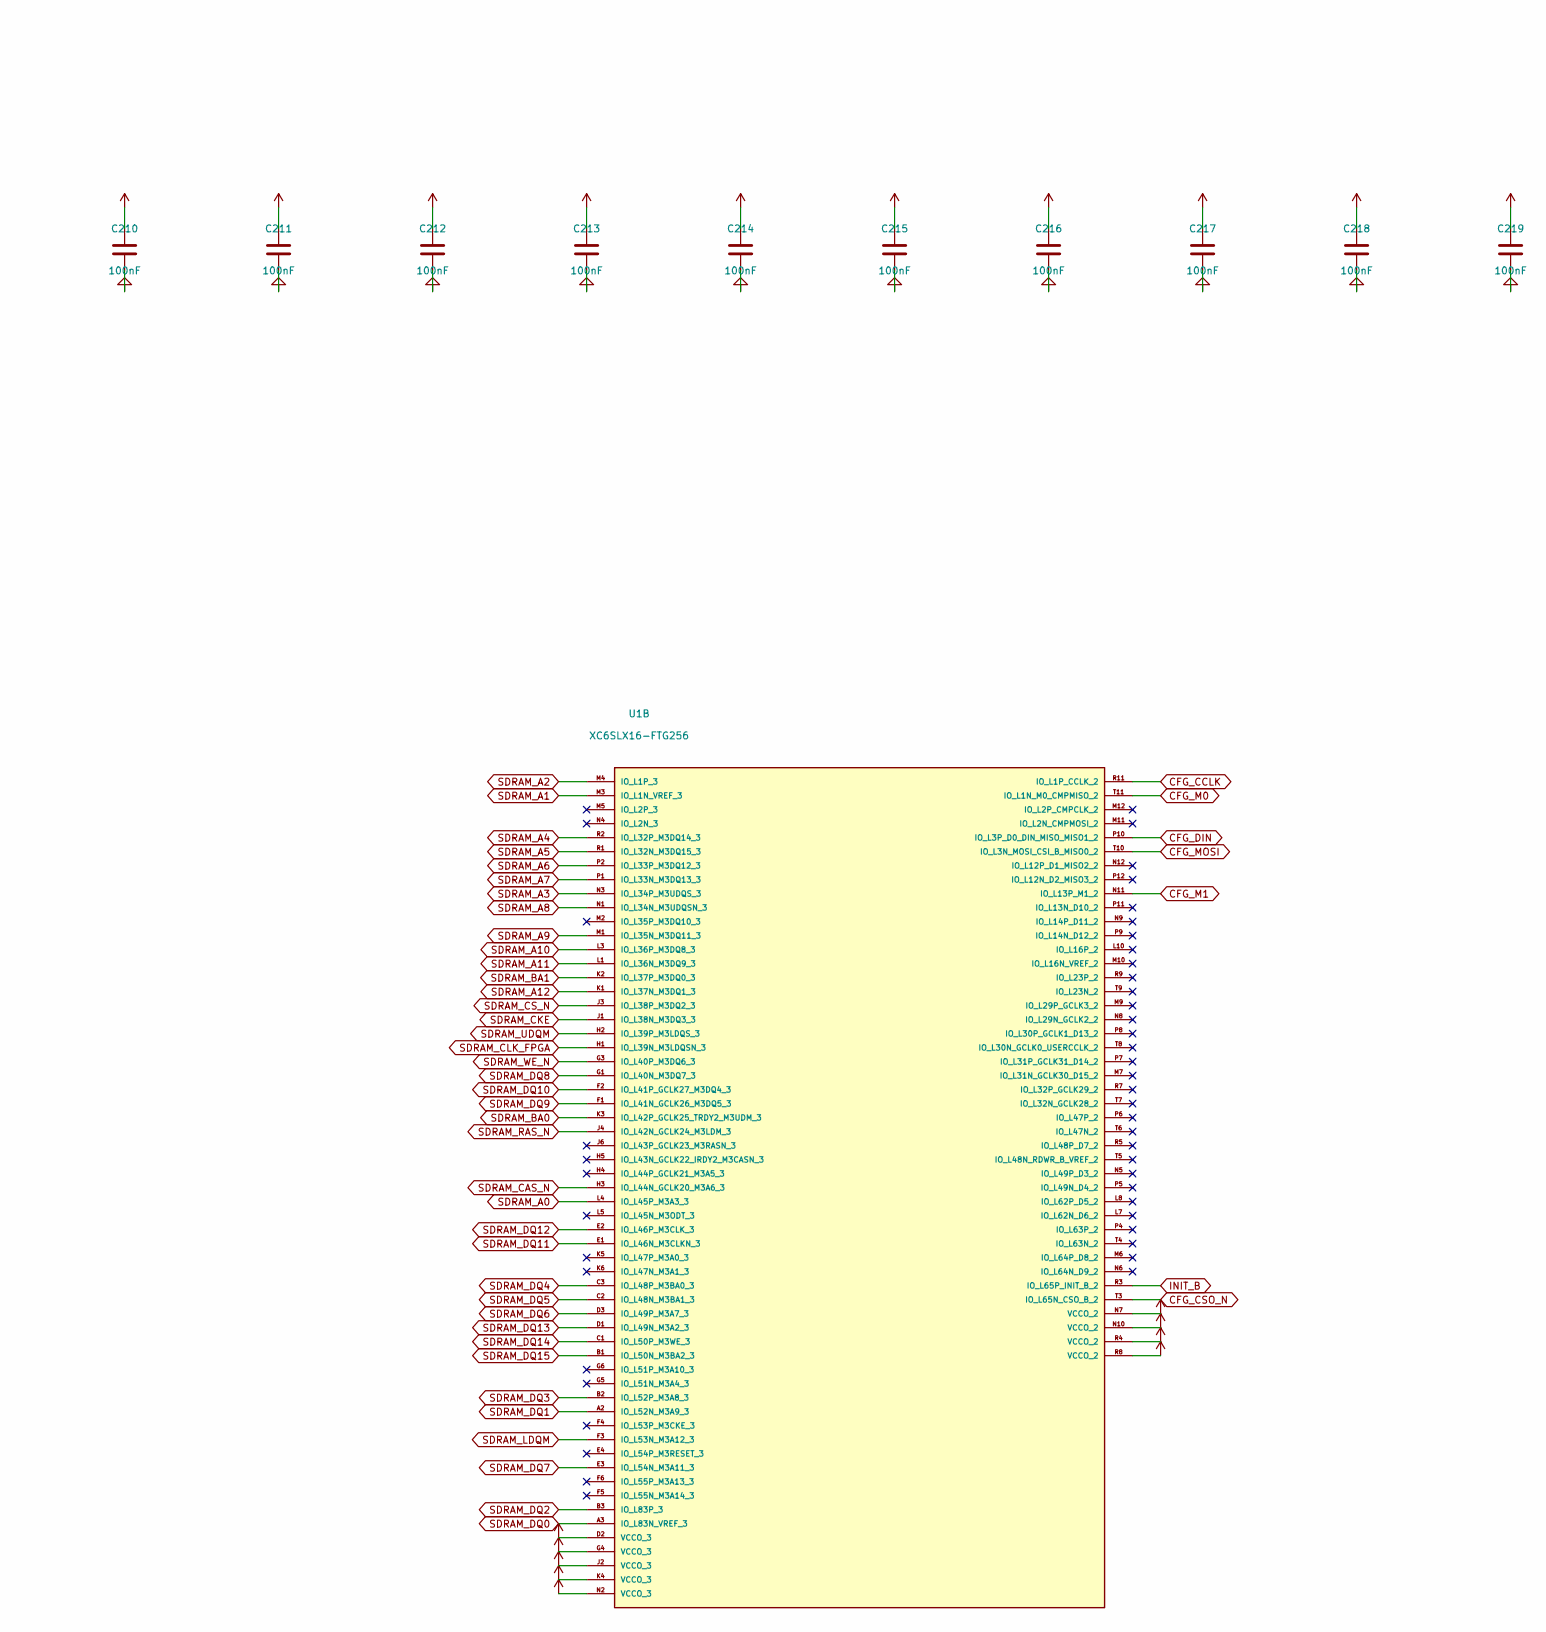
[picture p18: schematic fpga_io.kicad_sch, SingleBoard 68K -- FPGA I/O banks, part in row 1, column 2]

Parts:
C200, C201, C202, C203, C204, C205, C206, C207, C208, C209, C210, C211, C212, C213, C214, C215, C216, C217, C218, C219: 100nF; C_0402_1005Metric
C230, C231, C232, C233: 4.7uF; C_0805_2012Metric
U1: XC6SLX16-FTG256; Xilinx_FTG256

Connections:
+3V3: C200.1, C201.1, C202.1, C203.1, C204.1, C205.1, C206.1, C207.1, C208.1, C209.1, C210.1, C211.1, C212.1, C213.1, C214.1, C215.1, C216.1, C217.1, C218.1, C219.1, C230.1, C231.1, C232.1, C233.1, U1.B4 (VCCO_0), U1.B9 (VCCO_0), U1.B13 (VCCO_0), U1.D2 (VCCO_3), U1.D7 (VCCO_0), U1.D10 (VCCO_0), U1.D15 (VCCO_1), U1.G4 (VCCO_3), U1.G13 (VCCO_1), U1.J2 (VCCO_3), U1.J15 (VCCO_1), U1.K4 (VCCO_3), U1.K13 (VCCO_1), U1.N2 (VCCO_3), U1.N7 (VCCO_2), U1.N10 (VCCO_2), U1.N15 (VCCO_1), U1.R4 (VCCO_2), U1.R8 (VCCO_2), U1.R13 (VCCO_1); also elsewhere on the board
CFG_CCLK: U1.R11 (IO_L1P_CCLK_2); also elsewhere on the board
CFG_CSO_N: U1.T3 (IO_L65N_CSO_B_2); also elsewhere on the board
CFG_DIN: U1.P10 (IO_L3P_D0_DIN_MISO_MISO1_2); also elsewhere on the board
CFG_M0: U1.T11 (IO_L1N_M0_CMPMISO_2); also elsewhere on the board
CFG_M1: U1.N11 (IO_L13P_M1_2); also elsewhere on the board
CFG_MOSI: U1.T10 (IO_L3N_MOSI_CSI_B_MISO0_2); also elsewhere on the board
CLK50M: U1.E7 (IO_L36P_GCLK15_0); also elsewhere on the board
GND: C200.2, C201.2, C202.2, C203.2, C204.2, C205.2, C206.2, C207.2, C208.2, C209.2, C210.2, C211.2, C212.2, C213.2, C214.2, C215.2, C216.2, C217.2, C218.2, C219.2, C230.2, C231.2, C232.2, C233.2; also elsewhere on the board
HSWAPEN: U1.C4 (IO_L1P_HSWAPEN_0); also elsewhere on the board
INIT_B: U1.R3 (IO_L65P_INIT_B_2); also elsewhere on the board
LED0: U1.B14 (IO_L65P_SCP3_0); also elsewhere on the board
LED1: U1.A14 (IO_L65N_SCP2_0); also elsewhere on the board
LED2: U1.D11 (IO_L66P_SCP1_0); also elsewhere on the board
LED3: U1.D12 (IO_L66N_SCP0_0); also elsewhere on the board
RESET_BTN_N: U1.C13 (IO_L63P_SCP7_0); also elsewhere on the board
SDRAM_A0: U1.L4 (IO_L45P_M3A3_3); also elsewhere on the board
SDRAM_A1: U1.M3 (IO_L1N_VREF_3); also elsewhere on the board
SDRAM_A2: U1.M4 (IO_L1P_3); also elsewhere on the board
SDRAM_A3: U1.N3 (IO_L34P_M3UDQS_3); also elsewhere on the board
SDRAM_A4: U1.R2 (IO_L32P_M3DQ14_3); also elsewhere on the board
SDRAM_A5: U1.R1 (IO_L32N_M3DQ15_3); also elsewhere on the board
SDRAM_A6: U1.P2 (IO_L33P_M3DQ12_3); also elsewhere on the board
SDRAM_A7: U1.P1 (IO_L33N_M3DQ13_3); also elsewhere on the board
SDRAM_A8: U1.N1 (IO_L34N_M3UDQSN_3); also elsewhere on the board
SDRAM_A9: U1.M1 (IO_L35N_M3DQ11_3); also elsewhere on the board
SDRAM_A10: U1.L3 (IO_L36P_M3DQ8_3); also elsewhere on the board
SDRAM_A11: U1.L1 (IO_L36N_M3DQ9_3); also elsewhere on the board
SDRAM_A12: U1.K1 (IO_L37N_M3DQ1_3); also elsewhere on the board
SDRAM_BA0: U1.K3 (IO_L42P_GCLK25_TRDY2_M3UDM_3); also elsewhere on the board
SDRAM_BA1: U1.K2 (IO_L37P_M3DQ0_3); also elsewhere on the board
SDRAM_CAS_N: U1.H3 (IO_L44N_GCLK20_M3A6_3); also elsewhere on the board
SDRAM_CKE: U1.J1 (IO_L38N_M3DQ3_3); also elsewhere on the board
SDRAM_CLK_FPGA: U1.H1 (IO_L39N_M3LDQSN_3); also elsewhere on the board
SDRAM_CS_N: U1.J3 (IO_L38P_M3DQ2_3); also elsewhere on the board
SDRAM_DQ0: U1.A3 (IO_L83N_VREF_3); also elsewhere on the board
SDRAM_DQ1: U1.A2 (IO_L52N_M3A9_3); also elsewhere on the board
SDRAM_DQ2: U1.B3 (IO_L83P_3); also elsewhere on the board
SDRAM_DQ3: U1.B2 (IO_L52P_M3A8_3); also elsewhere on the board
SDRAM_DQ4: U1.C3 (IO_L48P_M3BA0_3); also elsewhere on the board
SDRAM_DQ5: U1.C2 (IO_L48N_M3BA1_3); also elsewhere on the board
SDRAM_DQ6: U1.D3 (IO_L49P_M3A7_3); also elsewhere on the board
SDRAM_DQ7: U1.E3 (IO_L54N_M3A11_3); also elsewhere on the board
SDRAM_DQ8: U1.G1 (IO_L40N_M3DQ7_3); also elsewhere on the board
SDRAM_DQ9: U1.F1 (IO_L41N_GCLK26_M3DQ5_3); also elsewhere on the board
SDRAM_DQ10: U1.F2 (IO_L41P_GCLK27_M3DQ4_3); also elsewhere on the board
SDRAM_DQ11: U1.E1 (IO_L46N_M3CLKN_3); also elsewhere on the board
SDRAM_DQ12: U1.E2 (IO_L46P_M3CLK_3); also elsewhere on the board
SDRAM_DQ13: U1.D1 (IO_L49N_M3A2_3); also elsewhere on the board
SDRAM_DQ14: U1.C1 (IO_L50P_M3WE_3); also elsewhere on the board
SDRAM_DQ15: U1.B1 (IO_L50N_M3BA2_3); also elsewhere on the board
SDRAM_LDQM: U1.F3 (IO_L53N_M3A12_3); also elsewhere on the board
SDRAM_RAS_N: U1.J4 (IO_L42N_GCLK24_M3LDM_3); also elsewhere on the board
SDRAM_UDQM: U1.H2 (IO_L39P_M3LDQS_3); also elsewhere on the board
SDRAM_WE_N: U1.G3 (IO_L40P_M3DQ6_3); also elsewhere on the board
UART_RX: U1.B12 (IO_L62P_0); also elsewhere on the board
UART_TX: U1.A12 (IO_L62N_VREF_0); also elsewhere on the board

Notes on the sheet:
All four bank VCCO rails are 3.3 V. Unused bank pins carry a no-connect flag.
To bring a spare ball out later, delete its flag here and add a LOC to the UCF.
The SDRAM occupies bank 3, on the balls fpga/spartan6/sp6_SDRAM.ucf fixes; bank 1 is entirely spare.

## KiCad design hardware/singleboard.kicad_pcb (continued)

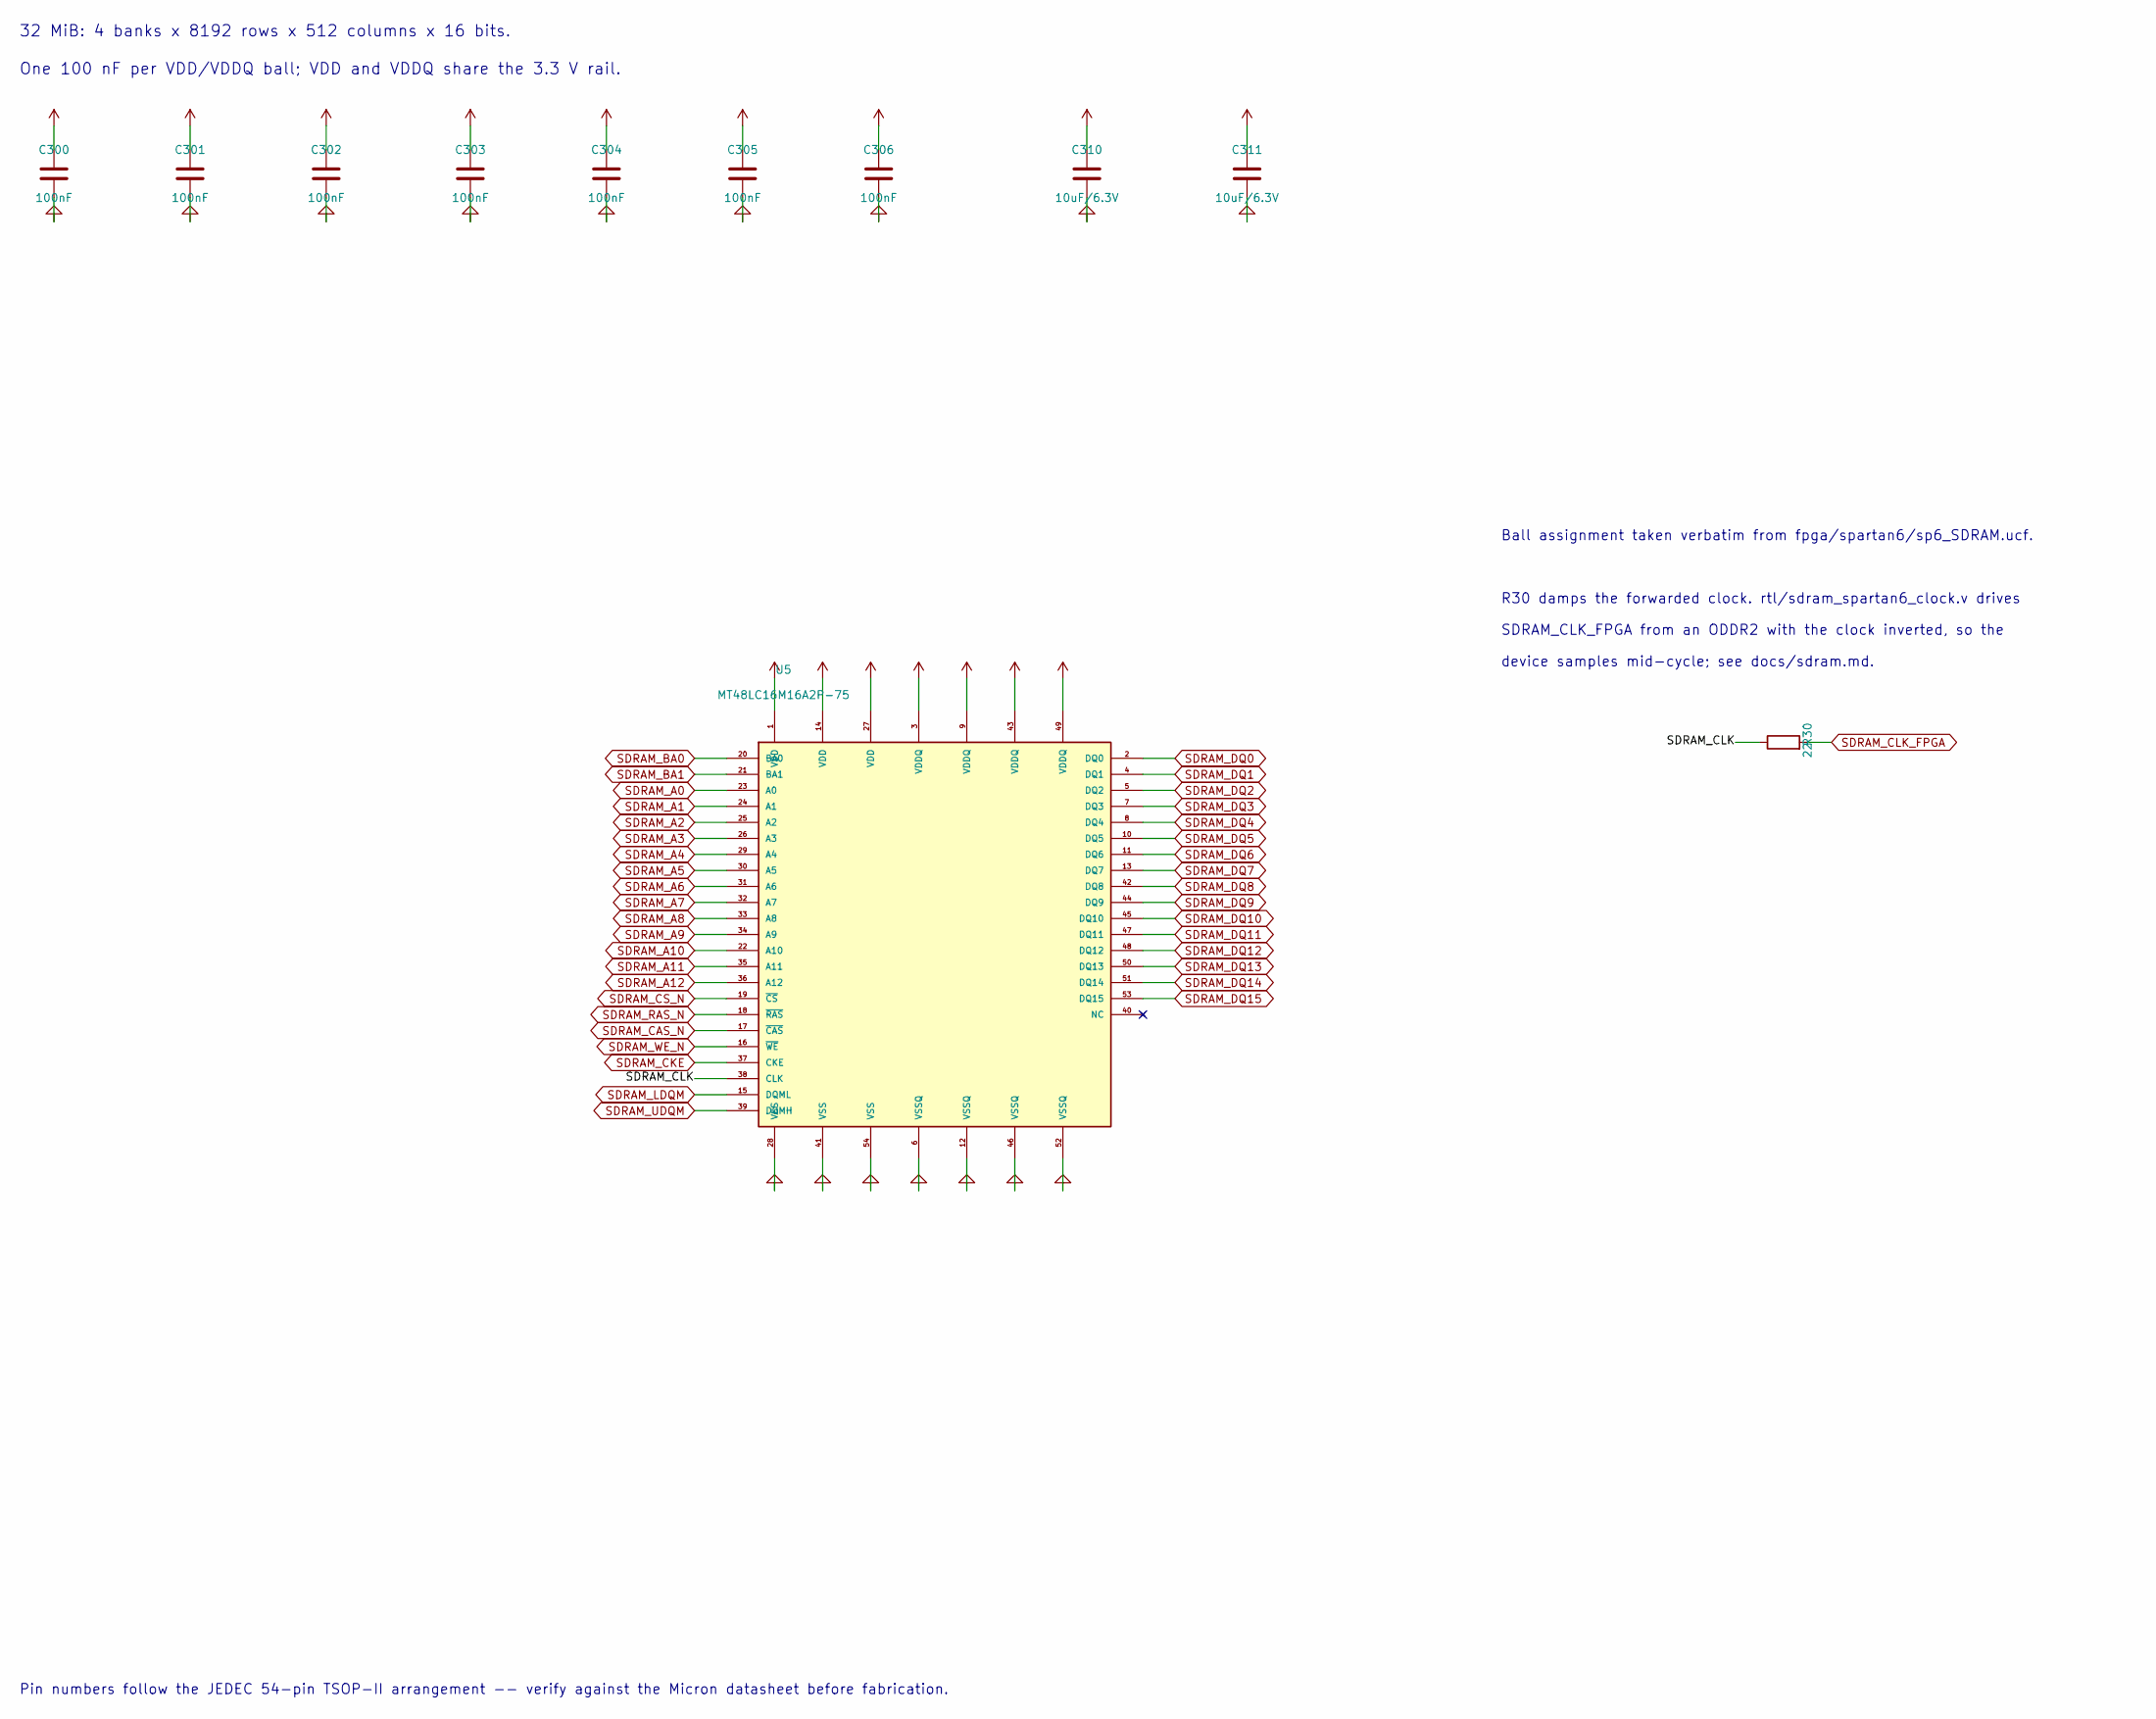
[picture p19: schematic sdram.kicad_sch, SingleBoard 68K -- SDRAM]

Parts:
C300, C301, C302, C303, C304, C305, C306: 100nF; C_0402_1005Metric
C310, C311: 10uF/6.3V; C_0805_2012Metric
R30: 22; R_0402_1005Metric
U5: MT48LC16M16A2P-75; TSOP-II-54_22.2x10.16mm_P0.8mm

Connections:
+3V3: C300.1, C301.1, C302.1, C303.1, C304.1, C305.1, C306.1, C310.1, C311.1, U5.1 (VDD), U5.3 (VDDQ), U5.9 (VDDQ), U5.14 (VDD), U5.27 (VDD), U5.43 (VDDQ), U5.49 (VDDQ); also elsewhere on the board
/sdram/SDRAM_CLK: R30.1, U5.38 (CLK)
GND: C300.2, C301.2, C302.2, C303.2, C304.2, C305.2, C306.2, C310.2, C311.2, U5.6 (VSSQ), U5.12 (VSSQ), U5.28 (VSS), U5.41 (VSS), U5.46 (VSSQ), U5.52 (VSSQ), U5.54 (VSS); also elsewhere on the board
SDRAM_A0: U5.23 (A0); also elsewhere on the board
SDRAM_A1: U5.24 (A1); also elsewhere on the board
SDRAM_A2: U5.25 (A2); also elsewhere on the board
SDRAM_A3: U5.26 (A3); also elsewhere on the board
SDRAM_A4: U5.29 (A4); also elsewhere on the board
SDRAM_A5: U5.30 (A5); also elsewhere on the board
SDRAM_A6: U5.31 (A6); also elsewhere on the board
SDRAM_A7: U5.32 (A7); also elsewhere on the board
SDRAM_A8: U5.33 (A8); also elsewhere on the board
SDRAM_A9: U5.34 (A9); also elsewhere on the board
SDRAM_A10: U5.22 (A10); also elsewhere on the board
SDRAM_A11: U5.35 (A11); also elsewhere on the board
SDRAM_A12: U5.36 (A12); also elsewhere on the board
SDRAM_BA0: U5.20 (BA0); also elsewhere on the board
SDRAM_BA1: U5.21 (BA1); also elsewhere on the board
SDRAM_CAS_N: U5.17 (~CAS); also elsewhere on the board
SDRAM_CKE: U5.37 (CKE); also elsewhere on the board
SDRAM_CLK_FPGA: R30.2; also elsewhere on the board
SDRAM_CS_N: U5.19 (~CS); also elsewhere on the board
SDRAM_DQ0: U5.2 (DQ0); also elsewhere on the board
SDRAM_DQ1: U5.4 (DQ1); also elsewhere on the board
SDRAM_DQ2: U5.5 (DQ2); also elsewhere on the board
SDRAM_DQ3: U5.7 (DQ3); also elsewhere on the board
SDRAM_DQ4: U5.8 (DQ4); also elsewhere on the board
SDRAM_DQ5: U5.10 (DQ5); also elsewhere on the board
SDRAM_DQ6: U5.11 (DQ6); also elsewhere on the board
SDRAM_DQ7: U5.13 (DQ7); also elsewhere on the board
SDRAM_DQ8: U5.42 (DQ8); also elsewhere on the board
SDRAM_DQ9: U5.44 (DQ9); also elsewhere on the board
SDRAM_DQ10: U5.45 (DQ10); also elsewhere on the board
SDRAM_DQ11: U5.47 (DQ11); also elsewhere on the board
SDRAM_DQ12: U5.48 (DQ12); also elsewhere on the board
SDRAM_DQ13: U5.50 (DQ13); also elsewhere on the board
SDRAM_DQ14: U5.51 (DQ14); also elsewhere on the board
SDRAM_DQ15: U5.53 (DQ15); also elsewhere on the board
SDRAM_LDQM: U5.15 (DQML); also elsewhere on the board
SDRAM_RAS_N: U5.18 (~RAS); also elsewhere on the board
SDRAM_UDQM: U5.39 (DQMH); also elsewhere on the board
SDRAM_WE_N: U5.16 (~WE); also elsewhere on the board

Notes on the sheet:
Ball assignment taken verbatim from fpga/spartan6/sp6_SDRAM.ucf.
R30 damps the forwarded clock. rtl/sdram_spartan6_clock.v drives
SDRAM_CLK_FPGA from an ODDR2 with the clock inverted, so the
device samples mid-cycle; see docs/sdram.md.
32 MiB: 4 banks x 8192 rows x 512 columns x 16 bits.
One 100 nF per VDD/VDDQ ball; VDD and VDDQ share the 3.3 V rail.
Pin numbers follow the JEDEC 54-pin TSOP-II arrangement -- verify against the Micron datasheet before fabrication.

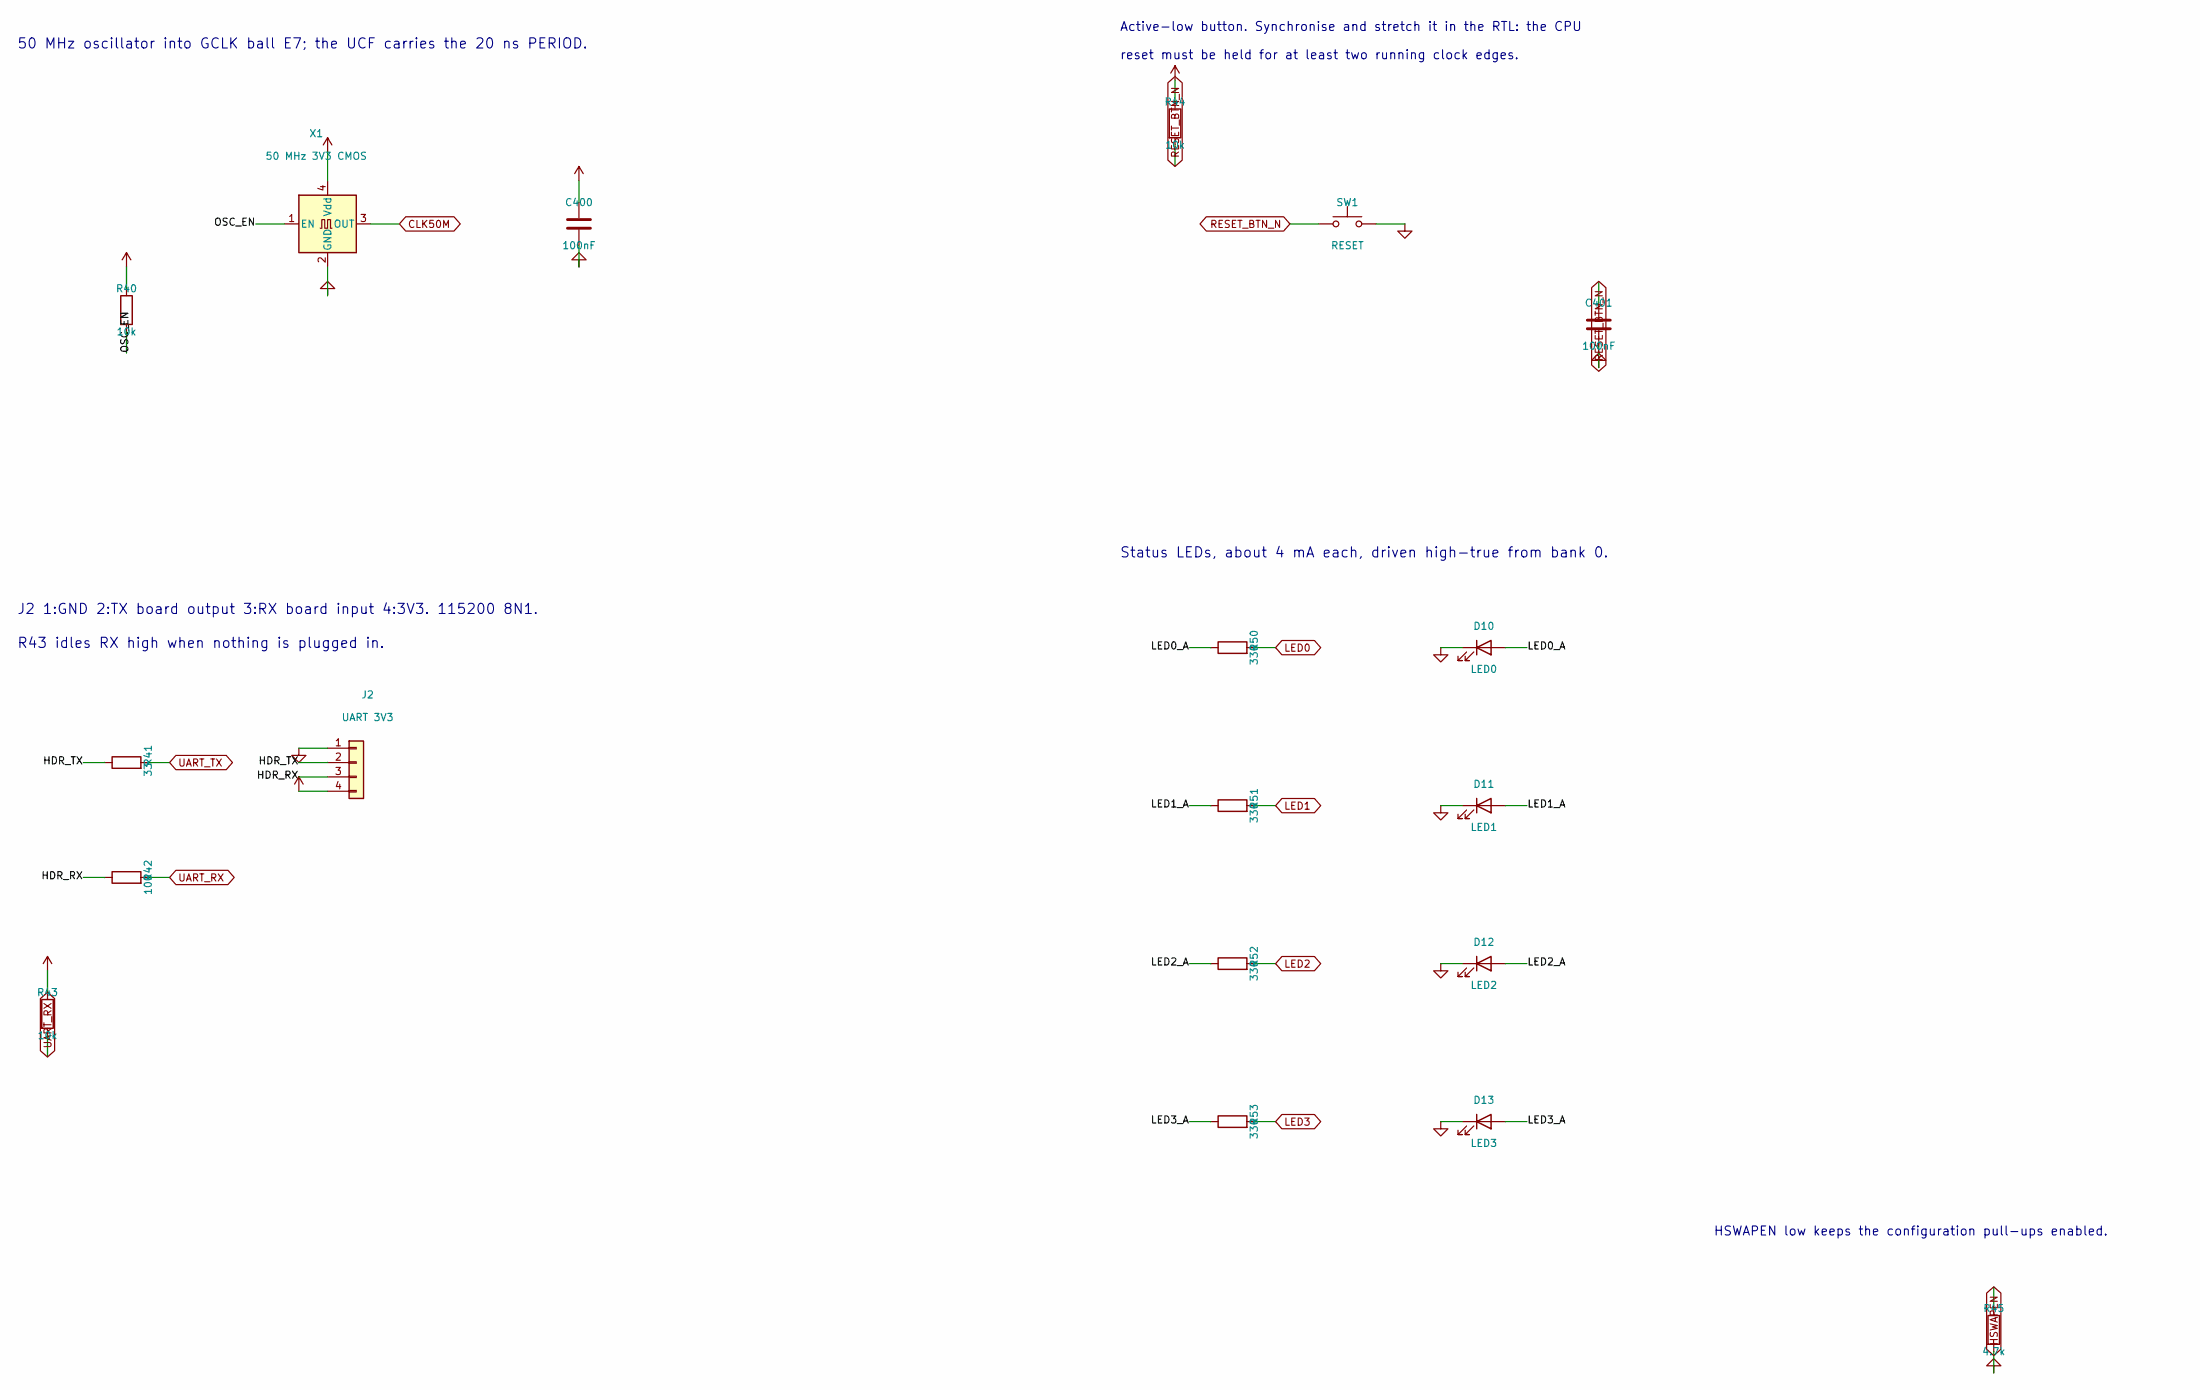
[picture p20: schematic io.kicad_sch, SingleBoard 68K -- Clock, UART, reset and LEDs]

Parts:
C400, C401: 100nF; C_0402_1005Metric
D10: LED0; LED_0603_1608Metric
D11: LED1; LED_0603_1608Metric
D12: LED2; LED_0603_1608Metric
D13: LED3; LED_0603_1608Metric
J2: UART 3V3; PinHeader_1x04_P2.54mm_Vertical
R40, R43, R44: 10k; R_0402_1005Metric
R41: 33; R_0402_1005Metric
R42: 100; R_0402_1005Metric
R45: 4.7k; R_0402_1005Metric
R50, R51, R52, R53: 330; R_0402_1005Metric
SW1: RESET; SW_SPST_SKQG_WithStem
X1: 50 MHz 3V3 CMOS; Oscillator_SMD_Abracon_ASE-4Pin_3.2x2.5mm

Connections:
+3V3: C400.1, J2.4, R40.1, R43.1, R44.1, X1.4 (Vdd); also elsewhere on the board
/io/HDR_RX: J2.3, R42.1
/io/HDR_TX: J2.2, R41.1
/io/LED0_A: D10.2 (A), R50.1
/io/LED1_A: D11.2 (A), R51.1
/io/LED2_A: D12.2 (A), R52.1
/io/LED3_A: D13.2 (A), R53.1
/io/OSC_EN: R40.2, X1.1 (EN)
CLK50M: X1.3 (OUT); also elsewhere on the board
GND: C400.2, C401.2, D10.1 (K), D11.1 (K), D12.1 (K), D13.1 (K), J2.1, R45.2, SW1.2, X1.2 (GND); also elsewhere on the board
HSWAPEN: R45.1; also elsewhere on the board
LED0: R50.2; also elsewhere on the board
LED1: R51.2; also elsewhere on the board
LED2: R52.2; also elsewhere on the board
LED3: R53.2; also elsewhere on the board
RESET_BTN_N: C401.1, R44.2, SW1.1; also elsewhere on the board
UART_RX: R42.2, R43.2; also elsewhere on the board
UART_TX: R41.2; also elsewhere on the board

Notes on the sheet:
50 MHz oscillator into GCLK ball E7; the UCF carries the 20 ns PERIOD.
J2 1:GND 2:TX board output 3:RX board input 4:3V3. 115200 8N1.
R43 idles RX high when nothing is plugged in.
Active-low button. Synchronise and stretch it in the RTL: the CPU
reset must be held for at least two running clock edges.
Status LEDs, about 4 mA each, driven high-true from bank 0.
HSWAPEN low keeps the configuration pull-ups enabled.

Board: 4 copper layers, 129 parts (43 on the bottom side), 88 nets, no tracks yet.

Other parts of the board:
H1, H2, H3, H4: M3; MountingHole_3.2mm_M3

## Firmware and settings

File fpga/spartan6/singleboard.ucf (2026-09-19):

# SingleBoard 68K board constraints for XC6SLX16-FTG256.
#
# Generated by scripts/gen_schematic.py from the same ball assignment
# as hardware/singleboard.kicad_sch. Do not edit by hand: change the
# tables in that script and re-run it.
#
# The SDRAM LOCs are read from sp6_SDRAM.ucf, the reference Spartan-6
# SDRAM board's constraints, so the schematic follows that board.
# Only the signal names are translated; no ball was chosen here.
#
# Port names follow rtl/sdram_mt48lc16m16a2.v, rtl/uart_mmio.v and
# rtl/sdram_spartan6_clock.v. Rename the left-hand side if the
# board-level top module uses different port names.
#
# No ISE run has validated this file. Nothing here has been placed,
# routed or timed.

CONFIG VCCAUX = 3.3;

NET "clk50m" TNM_NET = "clk50m";
TIMESPEC TS_clk50m = PERIOD "clk50m" 20.0 ns HIGH 50%;

NET "clk50m"          LOC = E7   | IOSTANDARD = LVCMOS33;
NET "uart_rx"         LOC = B12  | IOSTANDARD = LVCMOS33;
NET "uart_tx"         LOC = A12  | IOSTANDARD = LVCMOS33;
NET "reset_btn_n"     LOC = C13  | IOSTANDARD = LVCMOS33;

NET "led<0>"          LOC = B14  | IOSTANDARD = LVCMOS33;
NET "led<1>"          LOC = A14  | IOSTANDARD = LVCMOS33;
NET "led<2>"          LOC = D11  | IOSTANDARD = LVCMOS33;
NET "led<3>"          LOC = D12  | IOSTANDARD = LVCMOS33;

NET "sdram_addr<0>"   LOC = L4   | IOSTANDARD = LVCMOS33;
NET "sdram_addr<1>"   LOC = M3   | IOSTANDARD = LVCMOS33;
NET "sdram_addr<2>"   LOC = M4   | IOSTANDARD = LVCMOS33;
NET "sdram_addr<3>"   LOC = N3   | IOSTANDARD = LVCMOS33;
NET "sdram_addr<4>"   LOC = R2   | IOSTANDARD = LVCMOS33;
NET "sdram_addr<5>"   LOC = R1   | IOSTANDARD = LVCMOS33;
NET "sdram_addr<6>"   LOC = P2   | IOSTANDARD = LVCMOS33;
NET "sdram_addr<7>"   LOC = P1   | IOSTANDARD = LVCMOS33;
NET "sdram_addr<8>"   LOC = N1   | IOSTANDARD = LVCMOS33;
NET "sdram_addr<9>"   LOC = M1   | IOSTANDARD = LVCMOS33;
NET "sdram_addr<10>"  LOC = L3   | IOSTANDARD = LVCMOS33;
NET "sdram_addr<11>"  LOC = L1   | IOSTANDARD = LVCMOS33;
NET "sdram_addr<12>"  LOC = K1   | IOSTANDARD = LVCMOS33;

NET "sdram_ba<0>"     LOC = K3   | IOSTANDARD = LVCMOS33;
NET "sdram_ba<1>"     LOC = K2   | IOSTANDARD = LVCMOS33;

NET "sdram_dq<0>"     LOC = A3   | IOSTANDARD = LVCMOS33;
NET "sdram_dq<1>"     LOC = A2   | IOSTANDARD = LVCMOS33;
NET "sdram_dq<2>"     LOC = B3   | IOSTANDARD = LVCMOS33;
NET "sdram_dq<3>"     LOC = B2   | IOSTANDARD = LVCMOS33;
NET "sdram_dq<4>"     LOC = C3   | IOSTANDARD = LVCMOS33;
NET "sdram_dq<5>"     LOC = C2   | IOSTANDARD = LVCMOS33;
NET "sdram_dq<6>"     LOC = D3   | IOSTANDARD = LVCMOS33;
NET "sdram_dq<7>"     LOC = E3   | IOSTANDARD = LVCMOS33;
NET "sdram_dq<8>"     LOC = G1   | IOSTANDARD = LVCMOS33;
NET "sdram_dq<9>"     LOC = F1   | IOSTANDARD = LVCMOS33;
NET "sdram_dq<10>"    LOC = F2   | IOSTANDARD = LVCMOS33;
NET "sdram_dq<11>"    LOC = E1   | IOSTANDARD = LVCMOS33;
NET "sdram_dq<12>"    LOC = E2   | IOSTANDARD = LVCMOS33;
NET "sdram_dq<13>"    LOC = D1   | IOSTANDARD = LVCMOS33;
NET "sdram_dq<14>"    LOC = C1   | IOSTANDARD = LVCMOS33;
NET "sdram_dq<15>"    LOC = B1   | IOSTANDARD = LVCMOS33;

NET "sdram_dqm<0>"    LOC = F3   | IOSTANDARD = LVCMOS33;
NET "sdram_dqm<1>"    LOC = H2   | IOSTANDARD = LVCMOS33;

NET "sdram_cke"       LOC = J1   | IOSTANDARD = LVCMOS33;
NET "sdram_cs_n"      LOC = J3   | IOSTANDARD = LVCMOS33;
NET "sdram_ras_n"     LOC = J4   | IOSTANDARD = LVCMOS33;
NET "sdram_cas_n"     LOC = H3   | IOSTANDARD = LVCMOS33;
NET "sdram_we_n"      LOC = G3   | IOSTANDARD = LVCMOS33;
NET "sdram_clk"       LOC = H1   | IOSTANDARD = LVCMOS33;

# Dedicated configuration pins are fixed by the device and need no
# LOC: TCK C14, TDI C12, TDO E14, TMS A15, DONE P13, PROGRAM_B T2,
# SUSPEND P14, CMPCS_B L11.
# Master-SPI configuration uses CCLK R11, MOSI T10, DIN P10,
# CSO_B T3 and INIT_B R3, with mode pins M0 T11 high and M1 N11 low.
# HSWAPEN C4 is strapped low on the board.

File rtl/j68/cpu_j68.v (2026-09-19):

// Portability adaptation: inferred memories; project-relative init paths.
// Copyright 2011-2018 Frederic Requin
//
// The J68 core:
// -------------
// Simple re-implementation of the MC68000 CPU
// The core has the following characteristics:
//  - Tested on a Cyclone III (90 MHz) and a Stratix II (180 MHz)
//  - from 1500 (~70 MHz) to 1900 LEs (~90 MHz) on Cyclone III
//  - 2048 x 20-bit microcode ROM
//  - 256 x 28-bit decode ROM
//  - 2 x block RAM for the data and instruction stacks
//  - stack based CPU with forth-like microcode
//  - not cycle-exact : needs a frequency ~3 x higher
//  - all 68000 instructions are implemented
//  - almost all 68000 exceptions are implemented (only bus error missing)
//  - only auto-vector interrupts supported

module cpu_j68
(
    // Clock and reset
    input         rst,          // CPU reset
    input         clk,          // CPU clock
    /* direct_enable = 1 */ input clk_ena, // CPU clock enable
    // Bus interface
    output        rd_ena,       // Read strobe
    output        wr_ena,       // Write strobe
    input         data_ack,     // Data acknowledge
    output [1:0]  byte_ena,     // Byte enable
    output [31:0] address,      // Address bus
    input  [15:0] rd_data,      // Data bus in
    output [15:0] wr_data,      // Data bus out
    // 68000 control
    output [2:0]  fc,           // Function code
    input  [2:0]  ipl_n,        // Interrupt level
    // 68000 debug
    output [3:0]  dbg_reg_addr, // Register address
    output [3:0]  dbg_reg_wren, // Register write enable
    output [15:0] dbg_reg_data, // Register write data
    output [15:0] dbg_sr_reg,   // Status register
    output [31:0] dbg_pc_reg,   // Program counter
    output [31:0] dbg_usp_reg,  // User stack pointer
    output [31:0] dbg_ssp_reg,  // Supervisor stack pointer
    output [31:0] dbg_vbr_reg,  // Vector base register
    output [31:0] dbg_cycles,   // Cycles counter
    output        dbg_ifetch,   // Instruction fetch
    output  [2:0] dbg_irq_lvl   // Interrupt level
);
    parameter USE_CLK_ENA = 0;

    // ALU operations
    localparam [4:0]
        ALU_ADD     = 5'b00000,
        ALU_ADDC    = 5'b00001,
        ALU_SUB     = 5'b00010,
        ALU_SUBC    = 5'b00011,
        ALU_AND     = 5'b00100,
        ALU_BAND    = 5'b10100,
        ALU_OR      = 5'b00101,
        ALU_BOR     = 5'b10101,
        ALU_XOR     = 5'b00110,
        ALU_BXOR    = 5'b10110,
        ALU_NOT     = 5'b00111,
        ALU_BNOT    = 5'b10111,
        ALU_SHL     = 5'b01000,
        ALU_SHR     = 5'b01100,
        ALU_DIV     = 5'b01110,
        ALU_MUL     = 5'b01111;
    
    // ALU inputs
    localparam [1:0]
        A_ADD_ZERO  = 2'b00,
        A_ADD_T     = 2'b10,
        A_ADD_NOT_T = 2'b11,
        B_ADD_ZERO  = 2'b00,
        B_ADD_N     = 2'b10,
        B_ADD_NOT_N = 2'b11,
        A_LOG_ZERO  = 2'b00,
        A_LOG_IMM   = 2'b01,
        A_LOG_T     = 2'b10,
        A_LOG_RAM   = 2'b11,
        B_LOG_ZERO  = 2'b00,
        B_LOG_IO    = 2'b01,
        B_LOG_N     = 2'b10,
        B_LOG_NOT_N = 2'b11;

    reg                 r_rst_dly;  // Delayed reset signal

    wire [19:0]         w_inst_in;  // Internal RAM instruction read
    wire                w_ram_rd;   // Internal RAM read
    reg                 r_ram_rd;   // Internal RAM read (delayed)
    wire                w_ram_wr;   // Internal RAM write
    wire [1:0]          w_ram_bena; // Internal RAM byte enable
    wire [10:0]         w_ram_addr; // Internal RAM address
    wire [15:0]         w_ram_din;  // Internal RAM data write
    wire [15:0]         w_ram_dout; // Internal RAM data read
    wire                w_ram_rdy;  // RAM data ready

    wire                w_reg_wr;   // CPU register write
    wire [1:0]          w_reg_bena; // CPU register byte enable
    wire [10:0]         w_reg_addr; // CPU register address
  
    reg  [11:0]         w_alu_c;    // ALU control (wire)
    reg  [10:0]         w_flg_c;    // Flags control (wire)
    reg  [3:0]          w_cin_c;    // Carry in control (wire)

    reg  [3:0]          r_ds_ptr;   // Data stack pointer (reg)
    reg  [3:0]          w_ds_nxt;   // Next data stack pointer (wire)
    wire [3:0]          w_ds_inc;   // Data stack pointer increment (wire)
    reg  [15:0]         r_ds[0:15]; // Data stack (regs)
    reg  [15:0]         r_ds_T;     // Data stack output T (reg)
    wire [15:0]         w_ds_N;     // Data stack output N (wire)
    wire [31:0]         w_ds_R;     // Data stack input : ALU result (wire)
    reg                 w_ds_wr;    // Data stack write enable (wire)

    wire                w_ifetch;   // Fetch next instruction
    wire [10:0]         w_pc_inc;   // PC value incremented by 1 (wire)
    reg  [10:0]         r_pc_reg;   // PC register (reg)
    reg  [10:0]         w_pc_nxt;   // Next PC value (wire)
    wire [10:0]         w_pc_loop;  // PC value for loop (wire)

    reg  [3:0]          r_rs_ptr;   // Return stack pointer (reg)
    reg  [3:0]          w_rs_nxt;   // Next return stack pointer (wire)
    reg  [10:0]         r_rs[0:15]; // Return stack (regs)
    wire [10:0]         w_rs_q;     // Return stack output (wire)
    reg  [10:0]         w_rs_d;     // Return stack input (wire)
    reg                 w_rs_wr;    // Return stack write enable (wire)
    reg                 w_rs_rd;    // Return stack read enable (wire)

    // Micro-instruction decode  
    wire        w_io_op   = (w_inst_in[19:17] == 3'b100)  ? 1'b1 : 1'b0;
    wire        w_reg_op  = (w_inst_in[19:17] == 3'b101)  ? 1'b1 : 1'b0;
    wire        w_t_mode  = (w_inst_in[15:12] == 4'b1111) ? 1'b1 : 1'b0;
    wire        w_branch;
    wire [3:0]  w_loop_cnt;
    wire        w_loop;
    wire        w_skip;

    // ALU <-> Flags
    wire [31:0] w_res;
    wire [3:0]  w_alu;
    wire [1:0]  w_size;
    wire [4:0]  w_c_flg;
    wire [5:0]  w_v_flg;
    wire [10:0] w_sr;
    wire [4:0]  w_ccr;
    wire        w_c_in;
    wire        w_z_flg;
    wire        w_g_flg;

    // Memory access
    wire        w_io_rd;    // I/O register read
    wire        w_io_wr;    // I/O register write
    wire        w_io_ext;   // External memory access
    wire        w_io_rdy;   // I/O data ready
    wire        w_io_end;   // End of I/O cycle
    wire [15:0] w_io_din;   // I/O data input
    wire [10:0] w_io_flg_c; // Flag control (for SR write)

    // M68k instruction decoder
    wire [15:0] w_insw;     // Instruction word
    wire [15:0] w_extw;     // Extension word
    wire [15:0] w_ea1b;     // Effective address #1 bitfield

    // Debug
    reg  [31:0] r_usp_reg;
    reg  [31:0] r_ssp_reg;
    reg  [31:0] r_cycles;
    reg         r_go_super;
    reg   [2:0] r_irq_lvl;
    wire        w_super_st;
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
